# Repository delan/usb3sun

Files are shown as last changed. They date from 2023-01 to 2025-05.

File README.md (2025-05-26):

usb3sun
=======

usb3sun is an adapter that allows you to connect USB keyboards and mice to the Sun 8-pin mini-DIN interface.

* [buy now](https://www.tindie.com/products/funnycomputer/usb3sun/) on tindie
* read more about
    * [the breadboard prototype](https://cohost.org/delan/post/787278-usb3sun-a-usb-input)
    * [the development of rev A1](https://cohost.org/delan/post/1650431-usb3sun-rev-a1-a-us)
    * [the development of rev A2](https://cohost.org/delan/post/2042852-usb3sun-rev-a2-now)
    * [the development of rev A3](https://cohost.org/delan/post/2973101-usb3sun-rev-a3-guar)
    * [the development of firmware 2.0](https://cohost.org/delan/post/5806830-usb3sun-2-0-faster)
    * [the development of rev B0](https://cohost.org/delan/post/6029886-usb3sun-rev-b0-a-us)
    * [the funny computer museum](https://funny.computer.daz.cat/)

see also:

* [USB2Sun](https://github.com/jgilje/USB2Sun) by @jgilje
* [sun2usb](https://github.com/jareklupinski/sun2usb) by @jareklupinski

**note:** this repo uses submodules! clone with `--recursive`, or if you forgot to do that:

```sh
$ git submodule update --init --recursive
```

documentation
-------------

* **[user guide](doc/manual.md)**
* hacking and assembly docs
    * [firmware](doc/firmware.md)
    * [breadboard prototype](doc/prototype.md)
    * [pcb](hardware/pcb) docs coming soon!
* maintainer docs
    * [how to release](doc/releasing.md)

what’s new
----------

**rev B0** allows for debug logging (and the new debug cli) **without disabling the sun keyboard interface**, and fixes some [minor bugs](https://github.com/delan/usb3sun/blob/B0/doc/manual.md#errata) that happen when resetting the adapter.

new in **firmware 2.0**:

- support for **NeXTSTEP** and **Plan 9**, which require the mouse to run at 1200 baud
- configurable **mouse baud rate** — 9600 (default), 4800, 2400, or 1200 baud
- **debug cli** over UART_RX, allowing you to automate keyboard and mouse inputs

as of **firmware 1.5**, usb3sun can now [**reprogram your idprom**](https://funny.computer.daz.cat/sun/nvram-hostid-faq.txt) with just a few keystrokes, making it easier to boot your workstation with a dead nvram battery!

hardware features
-----------------

usb3sun includes an **audible buzzer** to emulate the bell and click functions that would normally be included with a Sun keyboard.

usb3sun also emulates the **power key** in two ways:

* **soft power key** (Right Ctrl+P)
    * sends the power key scancodes (30h/B0h)
    * can turn on your workstation (only when usb3sun is powered externally)
* **onboard power button** (near the display)
    * doesn’t send any scancodes
    * can turn on your workstation (even when not powered externally)

usb3sun has an **oled display** that shows:

* keyboard led indicators (caps, compose, scroll, num)
* visual buzzer (click, bell)
* the settings menu

usb3sun has an **onboard reset button** in case the firmware gets stuck, and a **0.1″ debug header** (pins available as an option) that allows you to power the adapter externally for flashing or debugging.

firmware features
-----------------

usb3sun has **persistent settings** for:

* forcing click mode (no/off/on)
* click duration (5–100 ms)
* mouse baud rate (for NeXTSTEP and Plan 9)
* your hostid

features planned for a future firmware version:

* settings for bell/click tone frequency
* led indicators on your USB keyboard itself

release notes
-------------

### firmware ?.? (????-??-??)

* added experimental support for **leds on your usb keyboard** — led updates are not yet reliable, and currently has bugs that can cause usb devices to stop responding
* added experimental support for **analysing other sun keyboards** — this allows us to improve our firmware by observing the behaviour of real sun keyboards

### firmware 2.1 (2025-05-26)

* [pio_pkg_list.txt](https://github.com/delan/usb3sun/blob/2.1/pio_pkg_list.txt) = dependency tree at time of release
* [#15](https://github.com/delan/usb3sun/issues/15) — fixed “The IDPROM contents are invalid” when reprogramming the idprom on some machines, including the Ultra5
* [#20](https://github.com/delan/usb3sun/issues/20) — fixed a bug where the display may not work correctly on a cold start (affects rev B0 units starting from B1#7)

### pcb rev B1 (2025-04-20)

* this board **requires firmware 2.1** or newer — firmware 2.0 is affected by [#20](https://github.com/delan/usb3sun/issues/20)
* changed J1 from [USB-U267-BWS](https://jlcpcb.com/partdetail/HanboElectronic-USB_U267BWS/C2962392) to the compatible [USB-269-BRW](https://jlcpcb.com/partdetail/Xunpu-USB_268BRY/C720548) due to stock shortage
* migrated from kicad 7 to kicad 8

### pcb rev B0 (2024-05-25)

* this board **requires firmware 2.0** or newer
* [#2](https://github.com/delan/usb3sun/issues/2) — fixed a limitation where the workstation **drops you into an ok prompt** when resetting the adapter
* [#11](https://github.com/delan/usb3sun/issues/11) — fixed a bug where the adapter can **hang until power cycled** after being reset, especially when reset frequently
* [#10](https://github.com/delan/usb3sun/issues/10) — added support for logging over UART_TX/UART_RX **without disabling the sun keyboard interface**
* reworked component layout and routing for **sun interfaces** and **led indicators** — none of the user-facing component locations have changed
* replaced transistors Q1 through Q4 (2N7000) with dual transistors Q1 and Q3 (2N7002DW)
* removed solder jumpers JP1 and JP2, which were added in rev A2 in case of errata

### firmware 2.0 (2024-05-02)

* [pio_pkg_list.txt](https://github.com/delan/usb3sun/blob/2.0/pio_pkg_list.txt) = dependency tree at time of release
* added support for adapters with **pcb rev B0** — these use pinout v2, while older revs use pinout v1
* added a **mouse baud setting** that can be set to 9600 baud (default), 4800, 2400, or 1200 baud
    * this adds support for **NeXTSTEP** and **Plan 9**, which require the mouse to run at a lower baud rate ([#8](https://github.com/delan/usb3sun/issues/8))
* you can now choose whether to **save or discard settings changes** when you close the menu
    * this change was made as part of a workaround for usb devices that malfunction when saving settings ([#14](https://github.com/delan/usb3sun/issues/14)); if you have any affected devices, hold **Shift** while pressing **Enter** to reboot the adapter after saving settings
* the displayed **version number** can now include **uncommitted and/or unreleased changes** (`2.0+` / `2.0+1` / `2.0+1+`)
* several other improvements to the user interface
    * you can now **close the menu by pressing Esc**
    * the menu now **automatically closes** after *Reprogram idprom* and *Wipe idprom (AAh)*
    * the menu now **shows four menu items**, rather than three menu items and the version number
    * *Click duration* now **beeps to preview your changes**, regardless of whether clicks are enabled
    * *Reprogram idprom* now **tells you what hostid is being programmed** into your idprom
* **updated our usb host stack**, making usb devices enumerate faster
    * Adafruit TinyUSB Library (2.0.1 → 3.1.0), Pico PIO USB (0.5.2 → 0.5.3)
    * this may affect [compatibility](https://github.com/delan/usb3sun/blob/default/doc/manual.md#compatibility) with your usb devices; please [report any regressions or improvements](https://github.com/delan/usb3sun/issues?q=is%3Aissue+is%3Aopen+label%3Acompatibility)
* added support for logging over UART_TX/UART_RX **without disabling the sun keyboard interface** ([#10](https://github.com/delan/usb3sun/issues/10))
    * this feature requires **pcb rev B0** or newer, due to the pinout changes required
    * please report any regressions with the **buzzer** or **sun mouse interface**; the buzzer had to be moved from pio to hardware pwm, and the sun mouse had to be moved from hardware uart to pio
* added a **debug cli** over UART_RX — this lets you press keys and move the mouse without a usb keyboard or mouse
* the firmware can now be **built as a normal program for linux**, thanks to a new hardware abstraction layer; as a result:
    * added an **interactive demo** (`run-demo.sh`) that can be used to play with or develop the user interface
    * added a **test suite** (`run-tests.sh`) for the setup and pinout routines, sun keyboard interface (reset sequence), buzzer (click and bell), settings (reads, writes, upgrades), and menu (confirm-save, hostid, i/o)
    * we can **catch some memory access violations** with dynamic analysis by **AddressSanitizer** (asan)
* added some **build tests** (`run-build-tests.sh`) to catch compile errors with custom build flags
* fixed some potential future compatibility issues in the settings formats (variable-width integer types and variable struct padding)
    * your existing settings in their v1 formats will be upgraded automatically
* fixed a compile error when debug logging was enabled (**PICOPROBE_ENABLE**, now known as **DEBUG_OVER_UART**)
* fixed all compile warnings under -Wall with the current toolchains for `pico` and `linux` (via nix-shell)
* fixed incorrect debug log output for **report id**, **usage**, and **usage page** when enumerating usb hid devices
* fixed missing newline in debug log output when reporting ErrorRollOver inputs from usb keyboards
* fixed missing newline in UHID_VERBOSE output when reporting inputs from non-boot-protocol usb devices
* removed the splash screen from debug logging — this significantly slowed down the setup routine
* removed the fake sun emulation feature — this wasn’t too useful, and was broken by the pinout changes
* several changes to config.h
    * added **DEBUG_OVER_CDC** to disable logging over usb cdc
    * added **UHID_LED_ENABLE** to opt into experimental usb hid led support
    * added **UHID_LED_TEST** to blink leds on all usb keyboards
    * added pin definitions **PINOUT_V2_PIN**, **KTX_ENABLE**, **DISPLAY_ENABLE**, **DEBUG_UART**, **SUNK_UART_V1**, **SUNK_UART_V2**, and **SUNM_UART_V1**
    * removed **SUNM_BAUD** in favour of the new menu setting
    * renamed **PICOPROBE_ENABLE** to **DEBUG_OVER_UART**
    * renamed **PICOPROBE_BAUD** to **DEBUG_UART_BAUD**
    * renamed **PICOPROBE_TX** to **DEBUG_UART_TX**
    * renamed **PICOPROBE_RX** to **DEBUG_UART_RX**
    * **SUN_KTX**, **SUN_KRX**, **SUN_MTX**, and **SUN_MRX** were split into pinout v1 and v2 variants
    * **DEBUG_OVER_UART** no longer disables logging over usb cdc (see **DEBUG_OVER_CDC**)
    * **SUNK_ENABLE** was moved to platformio.ini, and takes precedence over **DEBUG_OVER_UART** in pinout v1
    * **SUNM_ENABLE** was moved to platformio.ini

### pcb rev [A3](https://github.com/delan/usb3sun/releases/tag/A3) (2023-10-15)

* fixed the inconsistent and excessive brightness of the led indicators (D2, D3)
* fixed a bug where the VBUS indicator led (D2) can be dimly lit without VBUS being connected
* changed J1 from [UJ2-ADH-W1-TH](https://jlcpcb.com/partdetail/CuiDevices-UJ2_ADH_W1TH/C5201729) to the compatible [USB-U267-BWS](https://jlcpcb.com/partdetail/HanboElectronic-USB_U267BWS/C2962392) due to stock shortage
* cleaned up unused kicad libraries, and checked in libraries that were missing from the repo

### firmware [1.5](https://github.com/delan/usb3sun/releases/tag/1.5) (2023-07-18)

* [pio_pkg_list.txt](https://github.com/delan/usb3sun/blob/1.5/pio_pkg_list.txt) = dependency tree at time of release
* added a **macro to reprogram your idprom** — this makes it easier to boot your workstation with a dead nvram battery
* added a **macro to wipe your idprom** — this makes your idprom contents invalid, as if you had a dead nvram battery
* added a **hostid setting** — this sets the hostid used when reprogramming your idprom
* changed behaviour of builtin led to turn on at the very start of setup — this may help troubleshoot problems with CDC serial port initialisation

### firmware [1.4](https://github.com/delan/usb3sun/releases/tag/1.4) (2023-07-17)

* [pio_pkg_list.txt](https://github.com/delan/usb3sun/blob/1.4/pio_pkg_list.txt) = dependency tree at time of release
* **fixed a serious bug** where opening the settings menu can make the adapter start releasing keys at the wrong times
* **fixed a serious bug** where special key bindings (Right Ctrl) can get stuck down if Right Ctrl is released early
* you can now press special key bindings (Right Ctrl) together with other modifiers (e.g. [Shift+Undo](https://docs.oracle.com/cd/E19683-01/806-7612/startup-tbl-5/index.html) for Redo)
* improved performance of keyboard processing — this reduces the latency of key presses by up to 90 µs

you should update your firmware if you have any of the following symptoms:

* modifiers like Shift stop working after closing the settings menu
* modifiers like Shift appear to have a delayed effect after closing the settings menu
* when a key gets stuck down, it remains stuck even after pressing and releasing another key

you can also work around these bugs by resetting the adapter.

### firmware [1.3](https://github.com/delan/usb3sun/releases/tag/1.3) (2023-07-16)

* [pio_pkg_list.txt](https://github.com/delan/usb3sun/blob/1.3/pio_pkg_list.txt) = dependency tree at time of release
* added **firmware version to display** — this replaces the logo, which became a bit redundant
* added **marquee display for long menu items** — this fixes a bug where they would wrap in an unreadable way

### pcb rev [A2](https://github.com/delan/usb3sun/releases/tag/A2) (2023-06-30)

* added usb-c port J4 — this makes firmware updates much easier, and makes it possible to debug the sun keyboard and mouse interfaces simultaneously
* added polyfuse F3 after power supply switches — this protects the adapter under more fault conditions, in addition to faults in the downstream usb ports
* changed led resistors R12 and R13 from 200R to 1K — this reduces the luminous intensity from ~80% down to ~10% relative to 20mA
* changed tactile switches SW1 and SW2 from [TS-1187A-C-H-B](https://jlcpcb.com/partdetail/XkbConnectivity-TS_1187A_C_HB/C528025) to [TS-1187A-B-A-B](https://jlcpcb.com/partdetail/XkbConnectivity-TS_1187A_B_AB/C318884) — this reduces the extended parts fee with jlcpcb

### firmware [1.2](https://github.com/delan/usb3sun/releases/tag/1.2) (2023-06-11)

* [pio_pkg_list.txt](https://github.com/delan/usb3sun/blob/1.2/pio_pkg_list.txt) = dependency tree at time of release
* added **audible usb plug/unplug notifications**
* added **persistence for settings** — including click duration!
* added **“force click” setting** — this replaces the old disable/enable click option in the settings menu, which toggled the same state as the host machine, with an independent override
* changed the initial click mode state to off
* changed the initial led indicator states to off
* fixed theoretical(?) race condition in buzzer management
* fixed errors in the README bindings table

### pcb rev [A1](https://github.com/delan/usb3sun/releases/tag/A1) (2023-05-10)

* added display mechanical support — **committed later in [74b367a12600d](https://github.com/delan/usb3sun/commit/74b367a12600d712eb7a05a9fc67c958bae3fe62)**
* added tactile switches for reset and hard power key
* added header pins for debug logging over UART0
* added mounting holes for display mechanical support
* added LED indicators for VBUS and VSUN
* improved enclosure compatibility by moving mini-din beyond bottom edge
* improved ground plane islands by stitching vias
* made all corner mounting holes padded on both sides — previously this was only the case for the hole connected to GNDPWR, but not the other three

### firmware [1.1](https://github.com/delan/usb3sun/releases/tag/1.1) (2023-05-06)

* [pio_pkg_list.txt](https://github.com/delan/usb3sun/blob/1.1/pio_pkg_list.txt) = dependency tree at time of release
* fixed regressions due to dependency updates
    * fixed panic regression with *Pico Pio USB* 0.5.2 by removing non-idempotent workaround for a bug that was fixed upstream (sekigon-gonnoc/Pico-PIO-USB#77)
    * worked around unsolved usb hid regression (adafruit/Adafruit_TinyUSB_Arduino#296) by pinning *Adafruit TinyUSB Library* to 2.0.1
* fixed panic when combining PICOPROBE_ENABLE and CFG_TINYUSB_DEBUG
* changed default DISPLAY_ROTATION to 0 — this better suits pcb rev A0 than the old value, and is equally suitable for the breadboard prototype
* changed debug/upload protocols to cmsis-dap — this fixes compatibility with new picoprobe firmware
* pinned sensitive dependencies to reduce future breakage — note that not all dependencies are pinned yet (platformio/platformio-core#4613), but see above for known-good dependency tree

### pcb rev [A0](https://github.com/delan/usb3sun/releases/tag/A0) (2023-04-28)

* initial release

### firmware [1.0](https://github.com/delan/usb3sun/releases/tag/1.0) (2023-01-08)

* initial release

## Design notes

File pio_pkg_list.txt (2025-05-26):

********************************************************************************
Obsolete PIO Core v6.1.11 is used (previous was 6.1.17)
Please remove multiple PIO Cores from a system:
https://docs.platformio.org/en/latest/core/installation/troubleshooting.html
********************************************************************************
Warning! Ignore unknown configuration option `rust_lib` in section [env]
Warning! Ignore unknown configuration option `rust_target` in section [env:pico]
Resolving pico dependencies...
Platform raspberrypi @ 1.14.0+sha.5e87ae3 (required: git+https://github.com/maxgerhardt/platform-raspberrypi.git#v1.2.0-gcc12)
├── framework-arduinopico @ 1.30101.0+sha.c276a36 (required: git+https://github.com/earlephilhower/arduino-pico.git#3.1.1)
├── tool-mklittlefs-rp2040-earlephilhower @ 5.100300.230216 (required: earlephilhower/tool-mklittlefs-rp2040-earlephilhower @ ~5.100300.0)
├── tool-openocd-rp2040-earlephilhower @ 5.120300.240818 (required: https://github.com/earlephilhower/pico-quick-toolchain/releases/download/2.2.0/x86_64-linux-gnu.openocd-ebec9504d.240818.tar.gz)
├── tool-picotool-rp2040-earlephilhower @ 5.120300.240818 (required: https://github.com/earlephilhower/pico-quick-toolchain/releases/download/2.2.0/x86_64-linux-gnu.picotool-8a9af99.240818.tar.gz)
└── toolchain-rp2040-earlephilhower @ 5.120300.240125 (required: https://github.com/earlephilhower/pico-quick-toolchain/releases/download/2.2.0/x86_64-linux-gnu.arm-none-eabi-028e019.240125.tar.gz)

Libraries
├── Adafruit GFX Library @ 1.11.5+sha.5ea4be3 (required: git+https://github.com/adafruit/Adafruit-GFX-Library.git#1.11.5)
│   └── Adafruit BusIO @ 1.17.0 (required: Adafruit BusIO)
├── Adafruit SSD1306 @ 2.5.7+sha.88711ef (required: git+https://github.com/adafruit/Adafruit_SSD1306.git#2.5.7)
├── Adafruit TinyUSB Library @ 0.0.0+sha.2ebb6ab (required: git+https://github.com/adafruit/Adafruit_TinyUSB_Arduino.git#3.1.0)
└── Pico PIO USB @ 0.5.3+sha.e2c862b (required: git+https://github.com/sekigon-gonnoc/Pico-PIO-USB.git#0.5.3)

Resolving linux dependencies...
Platform native @ 1.2.1 (required: native)
├── contrib-piohome @ 3.4.4 (required: platformio/contrib-piohome)
├── framework-arduinopico @ 1.30101.0+sha.c276a36 (required: git+https://github.com/earlephilhower/arduino-pico.git#3.1.1)
├── tool-mklittlefs-rp2040-earlephilhower @ 5.100300.230216 (required: earlephilhower/tool-mklittlefs-rp2040-earlephilhower)
├── tool-openocd-rp2040-earlephilhower @ 5.120300.240818 (required: https://github.com/earlephilhower/pico-quick-toolchain/releases/download/2.2.0/x86_64-linux-gnu.openocd-ebec9504d.240818.tar.gz)
├── tool-picotool-rp2040-earlephilhower @ 5.120300.240818 (required: https://github.com/earlephilhower/pico-quick-toolchain/releases/download/2.2.0/x86_64-linux-gnu.picotool-8a9af99.240818.tar.gz)
├── tool-scons @ 4.40502.0 (required: platformio/tool-scons)
└── toolchain-rp2040-earlephilhower @ 5.120300.240125 (required: https://github.com/earlephilhower/pico-quick-toolchain/releases/download/2.2.0/x86_64-linux-gnu.arm-none-eabi-028e019.240125.tar.gz)

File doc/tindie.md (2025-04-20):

SPARCstations have [a unique serial-like interface](https://deskthority.net/wiki/Sun_keyboard/mouse_interface) for keyboard and mouse input, using a single 8-pin mini-din port. **usb3sun** allows you to use an ordinary USB keyboard and mouse with your SPARCstation!

in addition to the adapter itself, you will also need a male-to-male 8-pin mini-din cable (available as an option or [sold separately](https://www.tindie.com/products/funnycomputer/sun-mini-din-cable-2-metres/)), and your own USB keyboard and mouse (see below for compatibility).

**caution:** these cables are often sold elsewhere as a “mini-din serial cable”, but you **must** check that each pin is connected to the same pin on the other end. some cables, like the apple 590-0552-A, swap pins 1/2 + 3/5 + 6/8, and such cables must not be used.

* [user guide](https://github.com/delan/usb3sun/blob/default/doc/manual.md)
* [release notes](https://github.com/delan/usb3sun/releases)
* [project writeups and other links](https://go.daz.cat/usb3sun)

### testimonials

[europa64](https://linktr.ee/europa64) says:

“Honestly this is such a game changer, it really makes Suns so much more accessible for people who don’t have a hoard of vintage kit or the money to buy a keyboard on eBay. Getting these old machines into the hands of people is honestly one of the best ways to ensure they get preserved and your device really helps with that <3”

### what’s new

**rev B0** allows for debug logging (and the new debug cli) **without disabling the sun keyboard interface**, and fixes some [minor bugs](https://github.com/delan/usb3sun/blob/B0/doc/manual.md#errata) that happen when resetting the adapter.

**rev B1** is the same as rev B0, but with the USB-A connector changed due to stock shortage.

new in **firmware 2.0**:

- support for **NeXTSTEP** and **Plan 9**, which require the mouse to run at 1200 baud
- configurable **mouse baud rate** — 9600 (default), 4800, 2400, or 1200 baud
- **debug cli** over UART_RX, allowing you to automate keyboard and mouse inputs

as of **firmware 1.5**, usb3sun can now [**reprogram your idprom**](https://funny.computer.daz.cat/sun/nvram-hostid-faq.txt) with just a few keystrokes, making it easier to boot your workstation with a dead nvram battery!

### hardware features

usb3sun includes an **audible buzzer** to emulate the bell and click functions that would normally be included with a Sun keyboard.

usb3sun also emulates the **power key** in two ways:

* **soft power key** (Right Ctrl+P)
    * sends the power key scancodes (30h/B0h)
    * can turn on your workstation (only when usb3sun is powered externally)
* **onboard power button** (below the display)
    * doesn’t send any scancodes
    * can turn on your workstation (even when not powered externally)

usb3sun has an **oled display** that shows:

* led indicators (caps, compose, scroll, num)
* visual buzzer (click, bell)
* the settings menu

usb3sun has an **onboard reset button** in case the firmware gets stuck, and a **0.1″ debug header** with pins that allow you to power the adapter externally for flashing or debugging.

### firmware features

usb3sun has **persistent settings** for:

* forcing click mode (no/off/on)
* click duration (5–100 ms)
* mouse baud rate (for NeXTSTEP and Plan 9)
* your hostid

### compatibility

usb3sun is compatible with any machine that would normally use a

* Sun Compact 1
* Sun Type 4
* Sun Type 5
* Sun Type 5c
* Sun Type 6 (non-usb)

usb3sun has been tested successfully with

- SPARCstation IPC (sun4c)
- SPARCstation IPX (sun4c)
- SPARCstation 2 (sun4c)
- SPARCstation 5 (sun4m)
- SPARCstation 20 (sun4m)
- Ultra 5 (sun4u)
- 1209:A1E5 Atreus (Technomancy version) **keyboard** with QMK
- 04A5:8001 BenQ Zowie EC2 **mouse**
- 046D:C063 Dell M-UAV-DEL8 **mouse**
- FEED:1307 gBoards Gergo **keyboard** with QMK
- 03F0:6941 HP 150 Wired **Keyboard** (HSA-A013K, 664R5AA)
- 0461:4E24 HP KB71211 **keyboard** — no scroll lock or right meta
- 0461:4E23 HP MOGIUO **mouse**
- 04D9:1503 Inland 208397 **keyboard**
- 30FA:2031 Keji KECK801UKB **keyboard**
- 17EF:608D Lenovo EMS-537A **mouse**
- 17EF:6019 Lenovo MSU1175 **mouse**
- 045E:0040 Microsoft Wheel **Mouse** Optical 1.1A — enumeration is unreliable
- 045E:0752 Microsoft Wired **Keyboard** 400
- 045E:0750 Microsoft Wired **Keyboard** 600
- 045E:0773 Microsoft Explorer Touch **Mouse** (model 1490)
- FEED:6061 Preonic OLKB-60 **keyboard** with QMK

usb3sun is not yet compatible with

- [#4](https://github.com/delan/usb3sun/issues/4) — 05AC:024F Apple Magic **Keyboard** with Numeric Keypad (model A1243)
- [#5](https://github.com/delan/usb3sun/issues/5) — 1209:2303 Atreus (Keyboardio version) **keyboard** with Kaleidoscope
- [#6](https://github.com/delan/usb3sun/issues/6) — 3367:1903 Endgame Gear XM1r **mouse** — buttons only (16-bit dx/dy, no boot protocol)
- [#7](https://github.com/delan/usb3sun/issues/7) — 045E:0039 Microsoft Intelli**Mouse** Optical 1.1A — broken (“Control FAILED”)

### bindings

| USB | Sun |
|---|---|
| context menu | Compose |
| Left Alt | Alt |
| Right Alt | Graph/Alt |
| Left GUI* | left Meta (diamond) |
| Right GUI* | right Meta (diamond) |
| Left Ctrl | Control |
| Right Ctrl+Space  | (usb3sun settings menu) |
| Right Ctrl+. | Stop |
| Right Ctrl+Esc | Front |
| Right Ctrl+Return | Line Feed |
| Right Ctrl+C | Copy |
| Right Ctrl+F | Find |
| Right Ctrl+O | Open |
| Right Ctrl+P | Power |
| Right Ctrl+V | Paste |
| Right Ctrl+X | Cut |
| Right Ctrl+Y | Again |
| Right Ctrl+Z | Undo |
| Right Ctrl+F1 | Help |
| Right Ctrl+F4 | Props |
| Right Ctrl+= | keypad = |

\* aka Super, Mod4, Windows, etc

### specs

|  |  |
| --- | --- |
| width | 36 mm |
| length | 98 mm |
| height | 23 mm |
| ports | 1x Sun mini-din |
|  | 2x USB-A |
|  | 1x USB-C (debug only) |
| buttons | power (for workstation) |
|  | reset (for adapter) |
| led indicators | VBUS ok |
|  | VSUN ok |
| debug header pinout | 1. GND |
|  | 2. UART_TX |
|  | 3. UART_RX |
|  | 4. SWDIO |
|  | 5. SWCLK |
|  | 6. VBUS |

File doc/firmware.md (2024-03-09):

[README](../README.md) >

firmware
========

## how to build the firmware

1. `git apply picopiousb1.patch` ([picopiousb1.patch](../picopiousb1.patch), [#12](https://github.com/delan/usb3sun/issues/12))\
→ improves compatibility with Microsoft Wired Keyboard 600 (045E:0750)
2. `git apply tinyusb3.patch` ([tinyusb3.patch](../tinyusb3.patch), [#13](https://github.com/delan/usb3sun/issues/13))\
→ fixes a bug where dummy event callbacks shadow our own callbacks ([Adafruit_TinyUSB_Arduino#296](https://github.com/adafruit/Adafruit_TinyUSB_Arduino/issues/296))
3. `git apply debug1.patch` ([debug1.patch](../debug1.patch))\
→ makes TinyUSB debug logging configurable at runtime
4. `git -C ~/.platformio/packages/framework-arduinopico apply $PWD/debug2.patch` ([debug2.patch](../debug2.patch))\
→ makes arduino-pico debug logging configurable at runtime
5. `git -C ~/.platformio/packages/framework-arduinopico apply $PWD/debug3.patch` ([debug3.patch](../debug3.patch))\
→ makes TinyUSB debug logging configurable at runtime

### linux users

if you get “patch does not apply” errors:

```sh
$ dos2unix '.pio/libdeps/pico/Adafruit TinyUSB Library/src/host/usbh.c'
```

copy these commands to do all of the above:

```sh
dos2unix '.pio/libdeps/pico/Adafruit TinyUSB Library/src/host/usbh.c'
git apply tinyusb1.patch
git apply tinyusb2.patch
git apply debug1.patch
git -C ~/.platformio/packages/framework-arduinopico apply $PWD/debug2.patch
```

### windows users

if you encounter problems with paths being too long:

1. open an admin command prompt (Win+X, A)
2. `git config --system core.longpaths true`
3. whenever you get `[WinError 3]` or `[WinError 145]`, delete `%USERPROFILE%\.platformio\.cache\tmp`

if you get “patch does not apply” errors in step 2:

1. change the line endings from CRLF to LF in <.pio/libdeps/pico/Adafruit TinyUSB Library/src/host/usbh.c>

## how to get clangd (LSP) working

```sh
$ pio run -t compiledb
```

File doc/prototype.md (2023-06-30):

[README](../README.md) >

breadboard prototype
====================

## bill of materials

* 1x [raspberry pi pico, with headers](https://www.altronics.com.au/p/z6421a-raspberry-pi-pico-rp2040-development-board-with-headers/)
    * or 1x [raspberry pi pico](https://www.altronics.com.au/p/z6421-raspberry-pi-pico-microcontroller-board/) + 1x [0.1″ header pin block, 40x1](https://www.altronics.com.au/p/p5430-oupiin-40-way-header-pin/)
* 1x [ssd1306 i2c oled display, 128x32, with headers](https://www.aliexpress.com/item/1005004375650245.html)
* 2x [2n7000, n-channel mosfet, to-92 (s, g, d)](https://www.altronics.com.au/p/z1555-2n7000-to-92-n-channel-tmosfet/) ([datasheet](https://www.onsemi.com/pdf/datasheet/nds7002a-d.pdf))
* 3x 20K resistor, through hole
    * or 1x [20K resistor, through hole, 1% 0W25, bulk 10 units](https://www.altronics.com.au/p/r7589-20k-0.25w-metal-film-resistor-pk-10/)
    * or 1x [tinker component kit](https://www.altronics.com.au/p/k9640-tinker-parts-starter-kit/)
* 1x [solderless breadboard, 400 tie points (300+50+50)](https://www.altronics.com.au/p/p1002-400-way-breadboard/)
* 1x [solid wire kit, for solderless breadboards](https://www.altronics.com.au/p/p1018a-prototyping-breadboard-wire-packs-350pcs/)
    * or any sufficient amount of suitable solid wire
* 1x [mini-din plug, 8 pins, reversible](https://www.altronics.com.au/p/p1098-8-pin-line-mini-din-plug/)
* 16x jumper wire, dupont 0.1″, pin to socket
    * or 1x [jumper wire, dupont 0.1″, pin to socket, row of 30](https://www.altronics.com.au/p/p1021-pin-to-socket-30-way-prototyping-ribbon-strips/)
* ⎰ 3x crimp housing, dupont 0.1″, 4x1
* ⎱ 4x crimp housing, dupont 0.1″, 2x1
    * or 1x [crimp kit, dupont 0.1″](https://www.altronics.com.au/p/k9642-2.54mm-header-kit-310pc/)
* ⎰ 1x usb breakout board, usb a, 2 ports
* ⎱ 1x piezo buzzer, passive
    * you can often find these in old computer cases

## reference designators

* Q1 = 2n7000 for keyboard rx level shifter
* Q2 = 2n7000 for keyboard tx level shifter (optional)
* Q3 = 2n7000 for mouse tx level shifter (optional)
* Q4 = 2n7000 for soft power key
* U1 = pico
* U2 = display

## assembly instructions

1. connect a3 (U1 GND) to the left (Vusb) negative rail
2. connect g1 (U1 VBUS) to the left (Vusb) positive rail
3. connect j3 (U1 GND) to the right (3V3) negative rail
4. connect j5 (U1 3V3(OUT)) to the right (3V3) positive rail
5. connect j23 (U2 GND) to the right (3V3) negative rail
6. connect j22 (U2 VCC) to the right (3V3) positive rail
7. connect e22 (Q1 pin 2) to f22 (3V3 supply)
8. connect a24 (Q4 pin 1) to the left (Vusb) negative rail
9. connect g21 (U2 SCK) to g19 (U1 GP17)
10. connect d21 (Q1 pin 1) to d17 (U1 GP13)
    * picture below erroneously shows d21 to d12 (U1 GP9)
11. connect e25 (Q4 pin 2) to e20 (U1 GP15)
12. place Q1 pins (1,2,3) in (c21,c22,c23)
13. place Q4 pins (1,2,3) in (c24,c25,c26)
14. place resistor between b21 (Q1 pin 1) and b22 (3V3 supply)
15. place resistor between b23 (Q1 pin 3) and b27 (Vsun)
16. place resistor between b25 (Q4 pin 2) and b24 (ground)

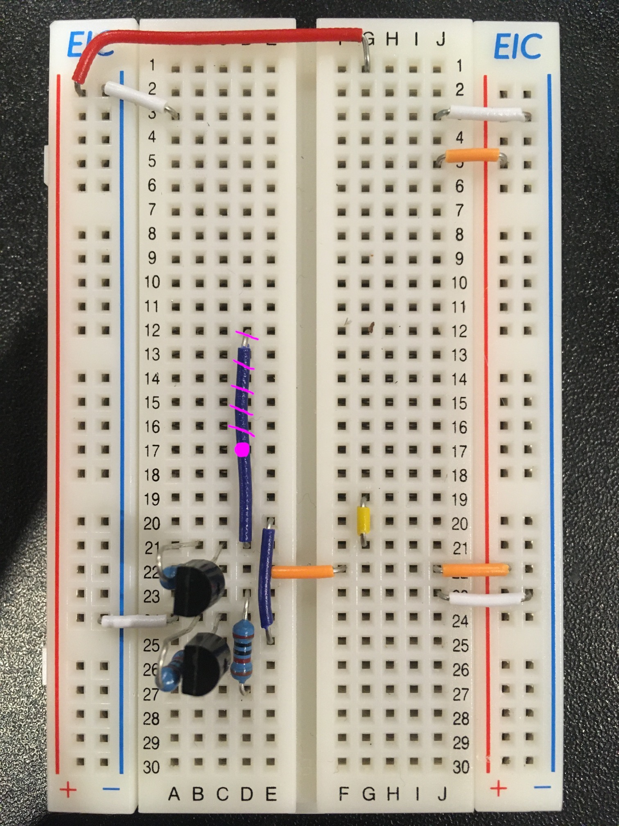
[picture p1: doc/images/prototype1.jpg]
prototype1


17. extract 1x1 crimp housings from both ends of 8 jumper wires
18. attach 4x1 crimp housing to socket ends of (VCC1,D-1,D+1,GND1)
19. attach 4x1 crimp housing to socket ends of (VCC2,D-2,D+2,GND2)
20. attach 2x1 crimp housing to pin ends of (VCC1,VCC2)
21. attach 2x1 crimp housing to pin ends of (GND1,GND2)
22. attach 4x1 crimp housing to pin ends of (D+1,D-1,D+2,D-2)
23. connect socket ends of (VCC1,D-1,D+1,GND1) and (VCC2,D-2,D+2,GND2)
24. connect pin ends of (GND1,GND2) to left (Vusb) negative rail
25. connect pin ends of (VCC1,VCC2) to left (Vusb) positive rail
26. connect pin ends of (D+1,D-1,D+2,D-2) to (a4,a5,a6,a7) (U1 (GP2,GP3,GP4,GP5))

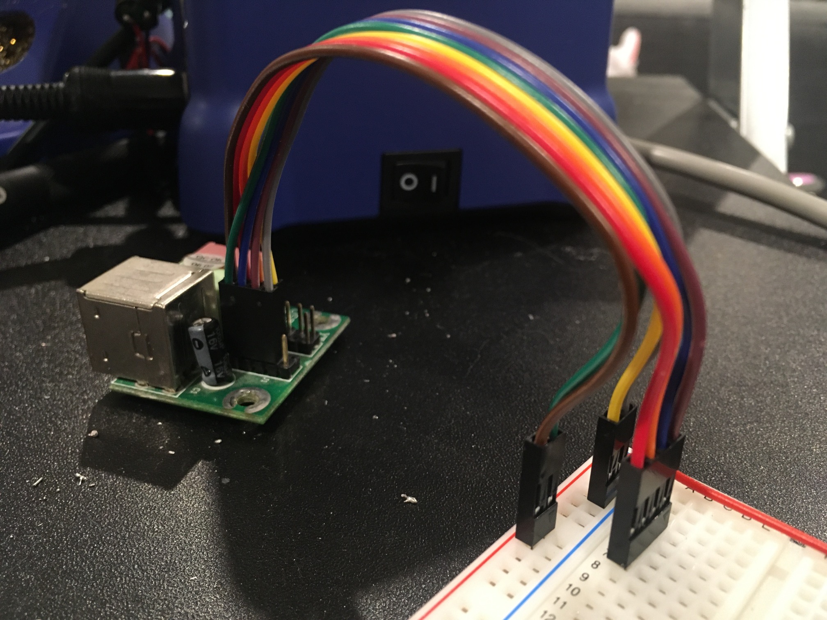
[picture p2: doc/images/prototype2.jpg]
prototype2


27. strip and tin the socket ends of 8 jumper wires
28. solder those wires to the mini-din plug

**DO NOT** solder to the side where the middle pin is closer to the left, when orienting the connector body such that the pins are in rows of (3,3,2) from top to bottom. this is the side that faces the sun.

**DO** solder to the side where the middle pin is closer to the right.

```
 side facing sun           solder side
                         (same as socket
                             on sun)

        ^                       ^
    6   7   8               8   7   6
  3   4       5           5       4   3
      1   2                   2   1
```

29. extract 1x1 crimp housings from wires for mini-din pins (1,2) (ground)
30. attach 2x1 crimp housing to wires for mini-din pins (1,2) (ground)
31. extract 1x1 crimp housings from wires for mini-din pins (3,8) (Vsun)
32. attach 2x1 crimp housing to wires for mini-din pins (3,8) (Vsun)
33. connect wires for mini-din pins (1,2) (ground) to left (Vusb) negative rail
34. connect wire for mini-din pins (3,8) (Vsun) to (a27,b27) (resistor on Q1 pin 3)
35. connect wire for mini-din pin 4 (mouse tx) to b11 (U1 GP8)
36. connect wire for mini-din pin 6 (keyboard tx) to b16 (U1 GP12)
37. connect wire for mini-din pin 5 (keyboard rx) to b23 (Q1 pin 3)
38. connect wire for mini-din pin 7 (power key) to b26 (Q4 pin 3)

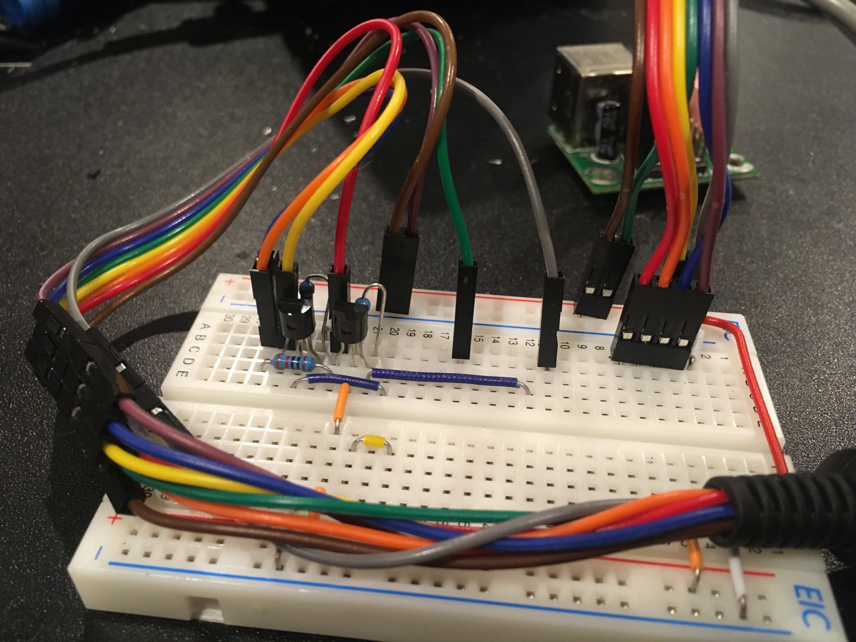
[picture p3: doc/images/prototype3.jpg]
prototype3


39. place U1 pins (GP0…GP15,GP16…VBUS) in (c1…c20,h20…h1)
40. place U2 pins (SDA,SCK,VCC,GND) in (i20,i21,i22,i23)
41. connect buzzer negative to i8 (U1 GND)
42. connect buzzer positive to i7 (U1 GP28)

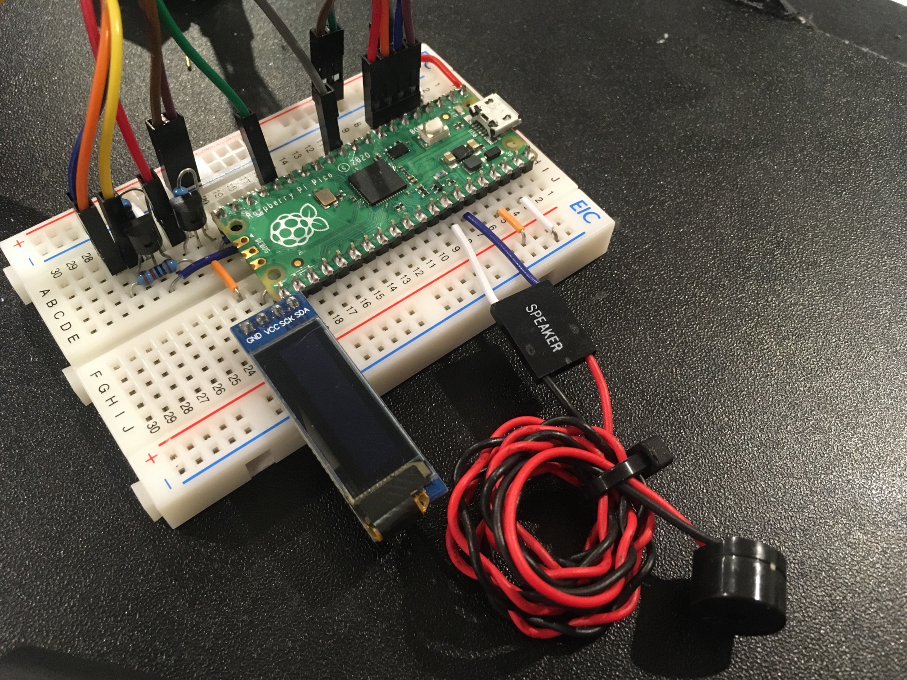
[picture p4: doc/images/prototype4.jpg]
prototype4


## troubleshooting

### monitor gets sync but no video

*observed on SPARCstation 5*

some machines will refuse to send any video unless a working keyboard is connected.

1. check that your adapter is assembled correctly
2. check that your mini-din housing isn’t interfering with the connection
    * you may need to retract the housing from time to time (see below)

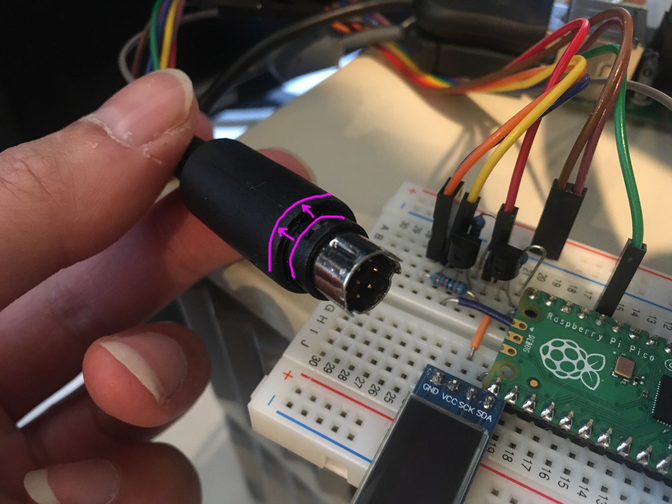
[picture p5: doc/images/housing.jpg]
housing


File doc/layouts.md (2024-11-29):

# sun keyboard layout support

supporting the various type 4 and type 5 keyboard layouts has a few challenges:
- identifying the physical keyboard layouts
- knowing what keycodes they send
- building tables of what the keycodes mean in each layout
- deciding how to map usb keycodes to them

also…
- layout codes ([0Fh Layout Command](https://temlib.org/pub/SparcStation/Standards/KBD.pdf) and [FEh Layout Request Response](https://temlib.org/pub/SparcStation/Standards/KBD.pdf)) are used to select the keymap in solaris/sunos and the firmware (openboot/sunmon), but seem to be ignored by linux distros (tested with debian 7.11.0)
- [sparc keyboard spec version1](https://temlib.org/pub/SparcStation/Standards/KBD.pdf) has incomplete and incorrect information about non-US keyboard layouts, notably table 2 (“International Scan Set”) is identical to table 1 (“US Scan Set”), both only documenting the 107-key layout

## physical keyboard layouts

- there are ?two physical type 4 layouts
  - 107-key layout with 47 main character keys ([pic en-US](https://www.flickr.com/photos/jgrove/3051883468/)), used by the US keyboard (320-1005)
  - 109-key layout with 49 main character keys ([pic de-DE](https://github.com/delan/usb3sun/assets/465303/2aa3ea0e-02fa-488c-a6cb-80acda7aae20), [pic BE fr-FR](https://tinkerdifferent.com/threads/sun-type-4-keyboard.1444/#post-9703)), used by ?all other keyboards ([part numbers](https://dogemicrosystems.ca/pub/Sun/System_Handbook/Sun_syshbk_V3.4/Systems/Sun4/INPUT_Type4_Keyboard.html))
  - see also [§ appendix: type 4 keyboard variants](#appendix-type-4-keyboard-variants)
- there are four physical type 5 layouts [[1]](https://www.vaxbarn.com/downloads/pub/pdf/sun/workstation/Sun%20Type%205c%20Keyboard%20and%20Type%205%20Mouse%20Product%20Notes%20-%201994-07.pdf)[[2]](https://vtda.org/docs/computing/Sun/hardware/800-6802-12_Type5KeyboardandMouseProductNotes_RevA_Oct93.pdf)[[3]](https://ia802806.us.archive.org/29/items/Sun_Type_5_Keyboard_Product_Notes/Sun_Type_5_Keyboard_Product_Notes.pdf)
  - 118-key layout with 47 main character keys ([pic en-US](https://www.flickr.com/photos/jgrove/3051046581/)), for US/TW/KR keyboards <!-- 10+1+1+4+4+4+3+4+6+4+4+3+4+3+3+14+14+13+12+7; 10+9+7+10+3+3+2+3 -->
  - 119-key layout with 47 main character keys ([pic en-US](https://deskthority.net/wiki/File:Suntype5.jpg)), for the “UNIX” keyboard <!-- 10+1+1+4+4+4+3+4+6+4+4+3+4+3+3+15+14+13+12+7; 10+9+7+10+4+2+2+3 -->
  - 119-key layout with 48 main character keys ([pic de-DE](https://github.com/delan/usb3sun/assets/465303/ecaf231e-8db7-405c-a329-d7a3bd58c9db), [pic en-UK](https://deskthority.net/wiki/File:Sun_Type_5_UK.jpg), [pic sv-SE](https://deskthority.net/wiki/File:SunType5c.jpg)), for “TUV-Compliant” keyboards (all other keyboards) <!-- 10+1+1+4+4+4+3+4+6+4+4+3+4+3+3+14+13+14+13+7; 10+9+7+10+3+2+3+4 -->
  - 122-key layout with 48 main character keys, for the JP keyboard <!-- 10+1+1+4+4+4+3+4+6+4+4+3+4+3+3+14+13+14+13+10; 10+9+7+10+3+2+3+4 --> ([pic jp-JP](images/type5-jp.jpg))
  - see also [§ appendix: type 5 keyboard variants](#appendix-type-4-keyboard-variants)
- physical usb layouts
  - 101/104-key layout with 47 main character keys, ansi/incits 154 <!-- 10+9+7+10+3+3+2+3 -->
  - 102/105-key layout with 48 main character keys, [iso 9995](https://en.wikipedia.org/w/index.php?title=ISO/IEC_9995&oldid=1242965538#ISO/IEC_9995-2) with B00 and C12 <!-- 10+9+7+10+3+2+3+4 -->
  - 106/109-key layout with 48 main character keys, jis x 6002 <!-- 10+9+7+10+3+2+3+4 -->
  - see also [List of QWERTY keyboard language variants](https://en.wikipedia.org/w/index.php?title=List_of_QWERTY_keyboard_language_variants&oldid=1253689618) and [Keyboard layout#Physical layouts](https://en.wikipedia.org/w/index.php?title=Keyboard_layout&oldid=1259709337#Physical_layouts) on wikipedia

## keycodes for each physical layout

### type 4, 107-key en-US (320-1005)

- gathered by building the firmware with `-DSUNK_SNIFFER_ENABLE` ([25d9defbb9ef7](https://github.com/delan/usb3sun/commit/25d9defbb9ef707f8eb204be7a572ce0c875a7cc)), then connecting my real sun keyboard to both workstation and usb3sun
- as expected, keycodes did not change when changing layout code from 00h ([United States](https://dogemicrosystems.ca/pub/Sun/System_Handbook/Sun_syshbk_V3.4/Systems/Sun4/INPUT_Type4_Keyboard.html)) to 02h ([Belgium/French](https://dogemicrosystems.ca/pub/Sun/System_Handbook/Sun_syshbk_V3.4/Systems/Sun4/INPUT_Type4_Keyboard.html)) or 05h ([German](https://dogemicrosystems.ca/pub/Sun/System_Handbook/Sun_syshbk_V3.4/Systems/Sun4/INPUT_Type4_Keyboard.html))

```
01h 03h  05h 06h 08h 0Ah 0Ch 0Eh 10h 11h 12h 07h 09h 0Bh 58h ====42h  15h 16h 17h 62h
19h 1Ah  1Dh 1Eh 1Fh 20h 21h 22h 23h 24h 25h 26h 27h 28h 29h ====2Bh  2Dh 2Eh 2Fh 47h
31h 33h  35h== 36h 37h 38h 39h 3Ah 3Bh 3Ch 3Dh 3Eh 3Fh 40h 41h |___|  44h 45h 46h |_|
48h 49h  4Ch=== 4Dh 4Eh 4Fh 50h 51h 52h 53h 54h 55h 56h 57h 2Ah |59h  5Bh 5Ch 5Dh 7Dh
5Fh 61h  63h===== 64h 65h 66h 67h 68h 69h 6Ah 6Bh 6Ch 6Dh ===6Eh 6Fh  70h 71h 72h |_|
76h====  77h 13h 78h 79h================================ 7Ah 43h 0Dh  5Eh==== 32h 5Ah
```

### type 4, 109-key layouts

- gathered by collating illumos keymaps (see [§ what the keycodes mean in each layout](#what-the-keycodes-mean-in-each-layout)) with some photos found online ([pic de-DE](https://github.com/delan/usb3sun/assets/465303/2aa3ea0e-02fa-488c-a6cb-80acda7aae20), [pic BE fr-FR](https://tinkerdifferent.com/threads/sun-type-4-keyboard.1444/#post-9703))

```
01h 03h  05h 06h 08h 0Ah 0Ch 0Eh 10h 11h 12h 07h 09h 0Bh 58h 0Fh 42h  15h 16h 17h 62h
19h 1Ah  1Dh 1Eh 1Fh 20h 21h 22h 23h 24h 25h 26h 27h 28h 29h ====2Bh  2Dh 2Eh 2Fh 47h
31h 33h  35h== 36h 37h 38h 39h 3Ah 3Bh 3Ch 3Dh 3Eh 3Fh 40h 41h |___|  44h 45h 46h |_|
48h 49h  4Ch=== 4Dh 4Eh 4Fh 50h 51h 52h 53h 54h 55h 56h 57h 2Ah |59h  5Bh 5Ch 5Dh 7Dh
5Fh 61h  63h= 7Ch 64h 65h 66h 67h 68h 69h 6Ah 6Bh 6Ch 6Dh ===6Eh 6Fh  70h 71h 72h |_|
76h====  77h 13h 78h 79h================================ 7Ah 43h 0Dh  5Eh==== 32h 5Ah
```

### type 5, 118-key US/TW/KR

- gathered from *Sun Type 5 Keyboard and Mouse Product Notes* (October 1993, [800-6802-12](https://vtda.org/docs/computing/Sun/hardware/800-6802-12_Type5KeyboardandMouseProductNotes_RevA_Oct93.pdf)), figure 7

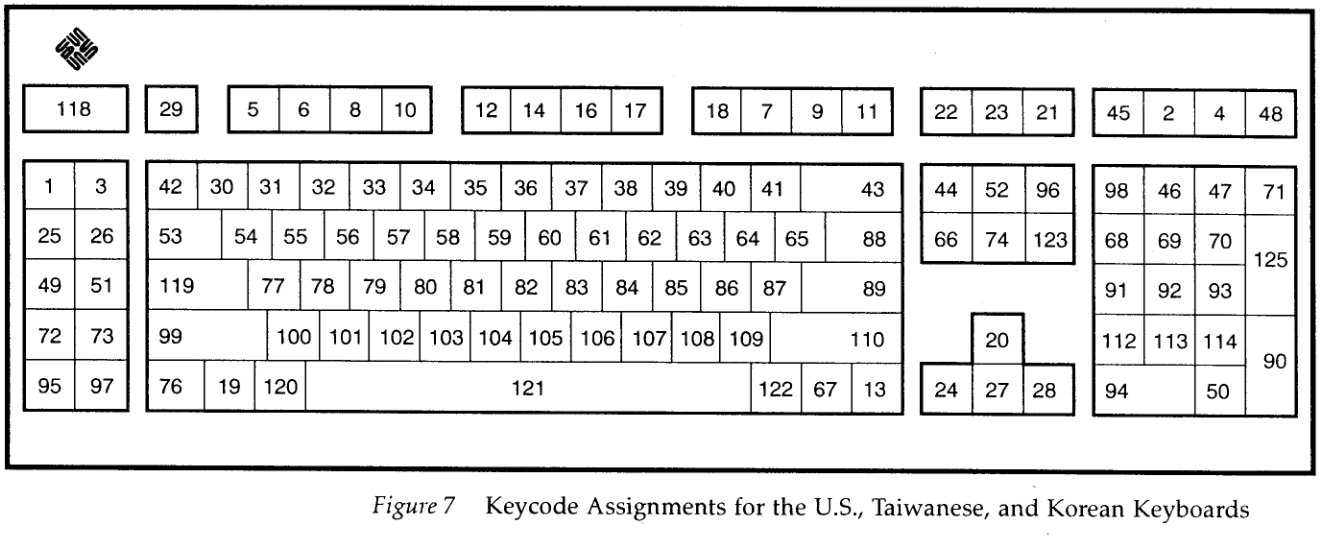
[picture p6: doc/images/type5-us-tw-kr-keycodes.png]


### type 5, 119-key “UNIX”

- gathered from *Sun Type 5 Keyboard and Mouse Product Notes* (October 1993, [800-6802-12](https://vtda.org/docs/computing/Sun/hardware/800-6802-12_Type5KeyboardandMouseProductNotes_RevA_Oct93.pdf)), figure 8

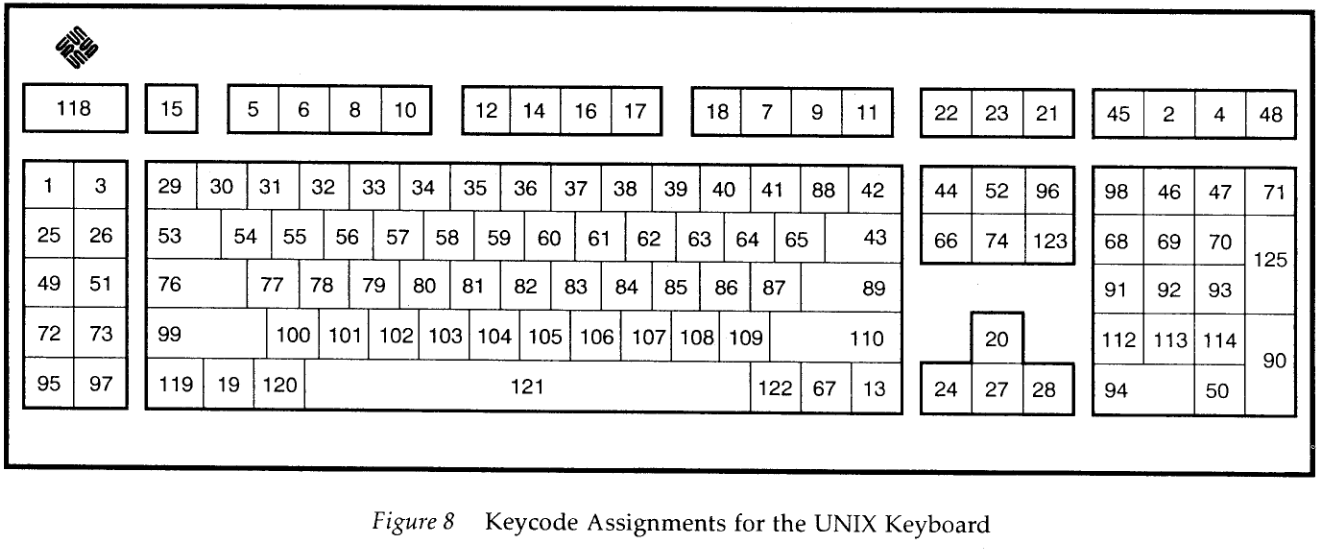
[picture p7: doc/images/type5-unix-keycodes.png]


### type 5, 119-key “TUV-Compliant”

- gathered from *Sun Type 5 Keyboard and Mouse Product Notes* (October 1993, [800-6802-12](https://vtda.org/docs/computing/Sun/hardware/800-6802-12_Type5KeyboardandMouseProductNotes_RevA_Oct93.pdf)), figure 9

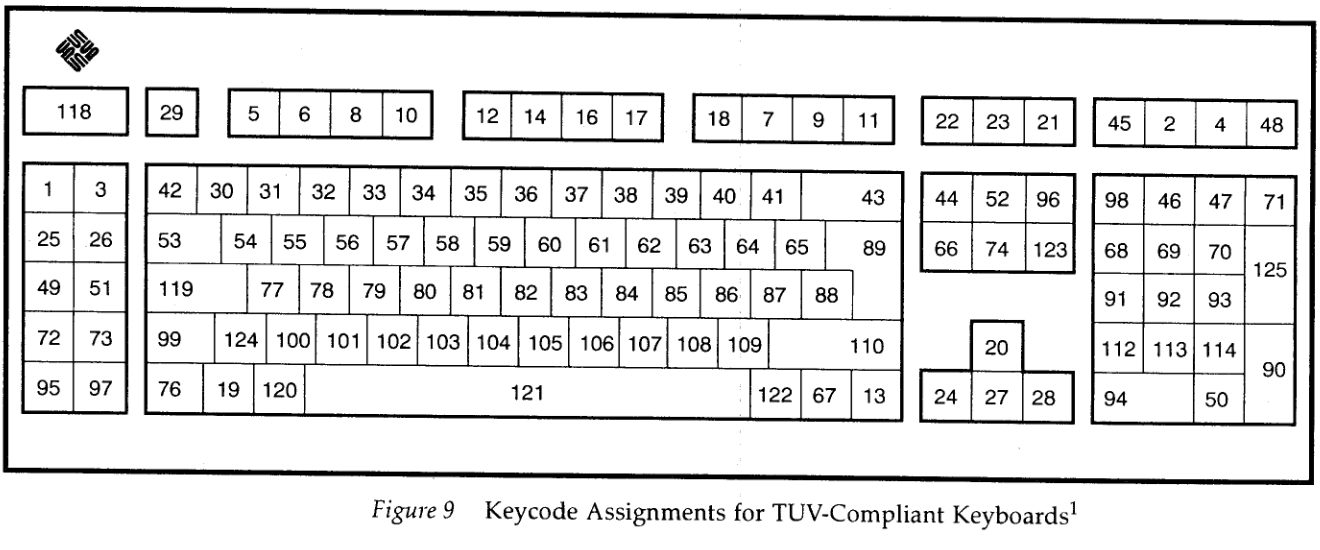
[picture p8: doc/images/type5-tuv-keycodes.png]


### type 5, 122-key JP

- gathered from *Sun Type 5 Keyboard and Mouse Product Notes* (October 1993, [800-6802-12](https://vtda.org/docs/computing/Sun/hardware/800-6802-12_Type5KeyboardandMouseProductNotes_RevA_Oct93.pdf)), figure 10

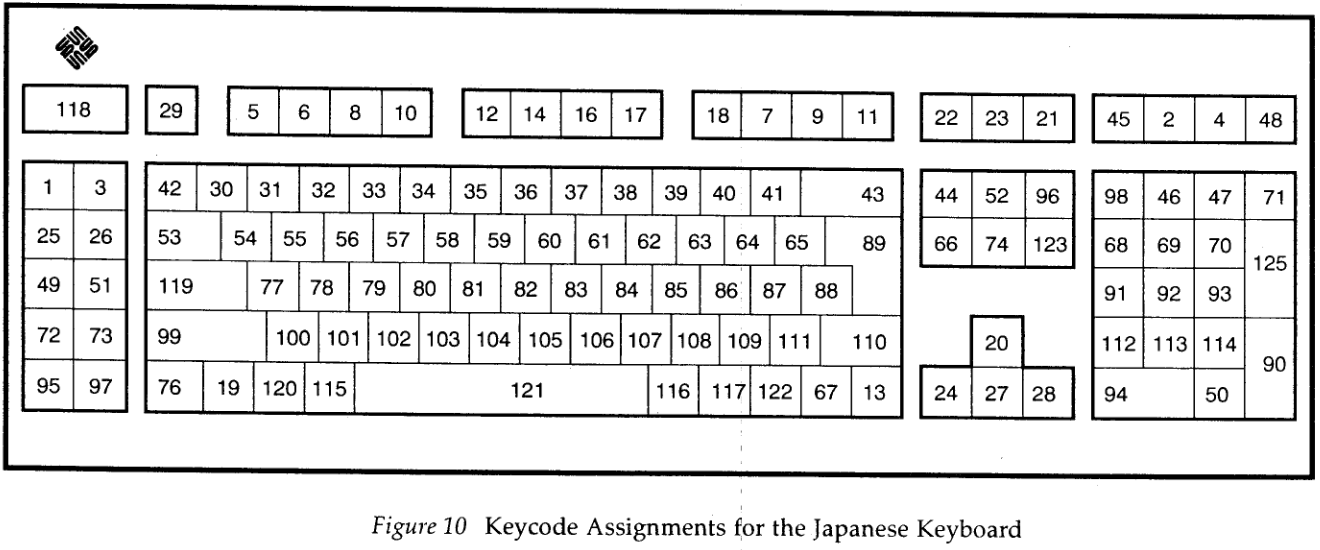
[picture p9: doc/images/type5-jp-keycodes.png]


## what the keycodes mean in each layout

- gathered from the [type 4 (and 5) keymaps](https://github.com/illumos/illumos-gate/tree/616c76953410e11aab663c510c9ba143e545bd4b/usr/src/cmd/loadkeys/type_4) in illumos-gate with [`doc/attic/query-illumos-keymaps.sh`](https://github.com/delan/usb3sun/blob/ce851c6adff445e0aab2189fc1ff3773a01b7e50/doc/attic/query-illumos-keymaps.sh) ([ce851c6adff44](https://github.com/delan/usb3sun/commit/ce851c6adff445e0aab2189fc1ff3773a01b7e50))
  - the layout code associated with each keymap is defined in [the Makefile](https://github.com/illumos/illumos-gate/blob/616c76953410e11aab663c510c9ba143e545bd4b/usr/src/cmd/loadkeys/type_4/Makefile)
- how to understand the output
  - [`src/bindings.h`](https://github.com/delan/usb3sun/blob/ce851c6adff445e0aab2189fc1ff3773a01b7e50/src/bindings.h) as of [ce851c6adff44](https://github.com/delan/usb3sun/commit/ce851c6adff445e0aab2189fc1ff3773a01b7e50) is included for reference
  - `reset` is next, because every keycode inherits its meaning from it if unspecified
  - finally the meanings of the keycode as overriden by other keymaps
  - for more details about the keymap syntax, see [solaris keytables(4)](https://docs.oracle.com/cd/E86824_01/html/E54775/keytables-4.html)

<details><summary>type 4 layouts</summary>

```
0 (00h)
reset:key 0	 all hole

1 (01h)
bindings.h:  {120, 0x01, 0x81}, // Keyboard Stop → 15. Stop
bindings.h:  {1u << 4, 55, 0x01, 0x81}, // CtrlR+. → 15. Stop
reset:key 1	 all buckybits+systembit up buckybits+systembit

2 (02h)
reset:key 2	 all hole

3 (03h)
bindings.h:  {121, 0x03, 0x83}, // Keyboard Again → 16. Again
bindings.h:  {1u << 4, 28, 0x03, 0x83}, // CtrlR+Y → 16. Again
reset:key 3	 all lf(2)

4 (04h)
reset:key 4	 all hole

5 (05h)
bindings.h:  {58, 0x05, 0x85}, // 1. F1
reset:key 5	 all tf(1)

6 (06h)
bindings.h:  {59, 0x06, 0x86}, // 2. F2
reset:key 6	 all tf(2)

7 (07h)
bindings.h:  {67, 0x07, 0x87}, // 10. F10
reset:key 7	 all tf(10)

8 (08h)
bindings.h:  {60, 0x08, 0x88}, // 3. F3
reset:key 8	 all tf(3)

9 (09h)
bindings.h:  {68, 0x09, 0x89}, // 11. F11
reset:key 9	 all tf(11)

10 (0Ah)
bindings.h:  {61, 0x0A, 0x8A}, // 4. F4
reset:key 10	 all tf(4)

11 (0Bh)
bindings.h:  {69, 0x0B, 0x8B}, // 12. F12
reset:key 11	 all tf(12)

12 (0Ch)
bindings.h:  {62, 0x0C, 0x8C}, // 5. F5
reset:key 12	 all tf(5)

13 (0Dh)
bindings.h:  {1u << 6, 0x0D, 0x8D}, // 105. Graph	Alt
reset:key 13	 all shiftkeys+altgraph up shiftkeys+altgraph
us:key 13	 all shiftkeys+altgraph up shiftkeys+altgraph
germany:key 13	 all shiftkeys+alt up shiftkeys+alt
swiss_german:key 13	 all compose
belgium_france:key 13	 all shiftkeys+capslock
uk:key 13	 all shiftkeys+altgraph up shiftkeys+altgraph
swiss_french:key 13	 all compose
netherlands:key 13	 all shiftkeys+capslock
sweden_finland:key 13	 all compose
denmark:key 13	 all compose
norway:key 13	 all shiftkeys+altgraph up shiftkeys+altgraph
italy:key 13	 all shiftkeys+altgraph up shiftkeys+altgraph
spain_latin_america:key 13	 all shiftkeys+altgraph up shiftkeys+altgraph
portugal:key 13	 all shiftkeys+altgraph up shiftkeys+altgraph
canada:key 13	 all shiftkeys+capslock

14 (0Eh)
bindings.h:  {63, 0x0E, 0x8E}, // 6. F6
reset:key 14	 all tf(6)

15 (0Fh)
reset:key 15	 all hole
us:key 15	 all hole
germany:key 15	 base ] shift } caps ] ctrl ^] altg »
swiss_german:key 15	 base > shift } caps > ctrl > altg nop
belgium_france:key 15	 base ] shift } caps ] ctrl ^] altg »
uk:key 15	 all hole
swiss_french:key 15	 base > shift } caps > ctrl > altg nop
netherlands:key 15	 base '\\' shift | caps '\\' ctrl ^\ altg nop
sweden_finland:key 15	 base ~ shift ^ caps ~ ctrl ^^ altg nop
denmark:key 15	 base ~ shift ^ caps ~ ctrl ^^ altg nop
norway:key 15	 base ~ shift ^ caps ~ ctrl ^^ altg nop
italy:key 15	 base ] shift } caps ] ctrl ^] altg »
spain_latin_america:key 15	 base ] shift } caps ] ctrl ^] altg »
portugal:key 15	 base ] shift } caps ] ctrl ^] altg »

16 (10h)
bindings.h:  {64, 0x10, 0x90}, // 7. F7
reset:key 16	 all tf(7)

17 (11h)
bindings.h:  {65, 0x11, 0x91}, // 8. F8
reset:key 17	 all tf(8)

18 (12h)
bindings.h:  {66, 0x12, 0x92}, // 9. F9
reset:key 18	 all tf(9)

19 (13h)
bindings.h:  {1u << 2, 0x13, 0x93}, // 100. Alt
reset:key 19	 all shiftkeys+alt up shiftkeys+alt
us:key 19	 all shiftkeys+alt up shiftkeys+alt
germany:key 19	 all shiftkeys+altgraph up shiftkeys+altgraph
swiss_german:key 19	 all shiftkeys+alt up shiftkeys+alt
belgium_france:key 19	 all shiftkeys+alt up shiftkeys+alt
uk:key 19	 all shiftkeys+alt up shiftkeys+alt
swiss_french:key 19	 all shiftkeys+alt up shiftkeys+alt
netherlands:key 19	 all shiftkeys+alt up shiftkeys+alt
sweden_finland:key 19	 all shiftkeys+alt up shiftkeys+alt
denmark:key 19	 all shiftkeys+alt up shiftkeys+alt
norway:key 19	 all shiftkeys+alt up shiftkeys+alt
italy:key 19	 all shiftkeys+alt up shiftkeys+alt
spain_latin_america:key 19	 all shiftkeys+alt up shiftkeys+alt
portugal:key 19	 all shiftkeys+alt up shiftkeys+alt
canada:key 19	 all shiftkeys+alt up shiftkeys+alt

20 (14h)
reset:key 20	 all hole

21 (15h)
bindings.h:  {72, 0x15, 0x95}, // Pause/Break(!) aka “Keyboard Pause” → 17. Pause
reset:key 21	 all rf(1)

22 (16h)
bindings.h:  {70, 0x16, 0x96}, // PrintScreen/SysRq aka “Keyboard PrintScreen” → 70. Pr Sc
reset:key 22	 all rf(2)

23 (17h)
bindings.h:  {71, 0x17, 0x97}, // Keyboard Scroll Lock → 71. Break(!)	Scroll Lock
reset:key 23	 all rf(3)

24 (18h)
reset:key 24	 all hole

25 (19h)
bindings.h:  {163, 0x19, 0x99}, // Keyboard CrSel/Props → 21. Props
bindings.h:  {1u << 4, 61, 0x19, 0x99}, // CtrlR+F4 → 21. Props
reset:key 25	 all lf(3)

26 (1Ah)
bindings.h:  {122, 0x1A, 0x9A}, // Keyboard Undo → 22. Undo
bindings.h:  {1u << 4, 29, 0x1A, 0x9A}, // CtrlR+Z → 22. Undo
reset:key 26	 all lf(4)

27 (1Bh)
reset:key 27	 all hole

28 (1Ch)
reset:key 28	 all hole

29 (1Dh)
bindings.h:  {41, 0x1D, 0x9D}, // 23. Esc
reset:key 29	 all ^[

30 (1Eh)
bindings.h:  {30, 0x1E, 0x9E}, // 24. 1	!
reset:key 30	 base 1 shift ! caps 1 ctrl 1 altg nop
us:key 30	 base 1 shift ! caps 1 ctrl 1 altg nop
germany:key 30	 base 1 shift ! caps 1 ctrl 1 altg nop
swiss_german:key 30	 base 1 shift + caps 1 ctrl 1 altg !
belgium_france:key 30	 base & shift 1 caps & ctrl & altg nop
uk:key 30	 base 1 shift ! caps 1 ctrl 1 altg |
swiss_french:key 30	 base 1 shift + caps 1 ctrl 1 altg !
netherlands:key 30	 base 1 shift ! caps 1 ctrl 1 altg ¹
sweden_finland:key 30	 base 1 shift ! caps 1 ctrl 1 altg nop
denmark:key 30	 base 1 shift ! caps 1 ctrl 1 altg nop
norway:key 30	 base 1 shift ! caps 1 ctrl 1 altg nop
italy:key 30	 base 1 shift ! caps 1 ctrl 1 altg nop
spain_latin_america:key 30	 base 1 shift ! caps 1 ctrl 1 altg nop
portugal:key 30	 base 1 shift ! caps 1 ctrl 1 altg nop
canada:key 30	 base 1 shift ! caps 1 ctrl 1 altg ±

31 (1Fh)
bindings.h:  {31, 0x1F, 0x9F}, // 25. 2	@
reset:key 31	 base 2 shift @ caps 2 ctrl ^@ altg nop
us:key 31	 base 2 shift @ caps 2 ctrl ^@ altg nop
germany:key 31	 base 2 shift '"' caps 2 ctrl 2 altg ²
swiss_german:key 31	 base 2 shift '"' caps 2 ctrl ^@ altg @
belgium_france:key 31	 base é shift 2 caps E ctrl É altg ²
uk:key 31	 base 2 shift @ caps 2 ctrl ^@ altg nop
swiss_french:key 31	 base 2 shift '"' caps 2 ctrl ^@ altg @
netherlands:key 31	 base 2 shift '"' caps 2 ctrl 2 altg ²
sweden_finland:key 31	 base 2 shift '"' caps 2 ctrl ^@ altg @
denmark:key 31	 base 2 shift '"' caps 2 ctrl ^@ altg @
norway:key 31	 base 2 shift '"' caps 2 ctrl ^@ altg @
italy:key 31	 base 2 shift '"' caps 2 ctrl 2 altg ²
spain_latin_america:key 31	 base 2 shift '"' caps 2 ctrl ^@ altg @
portugal:key 31	 base 2 shift '"' caps 2 ctrl ^@ altg @
canada:key 31	 base 2 shift '"' caps 2 ctrl ^@ altg @

32 (20h)
bindings.h:  {32, 0x20, 0xA0}, // 26. 3	#
reset:key 32	 base 3 shift # caps 3 ctrl 3 altg nop
us:key 32	 base 3 shift # caps 3 ctrl 3 altg nop
germany:key 32	 base 3 shift § caps 3 ctrl 3 altg ³
swiss_german:key 32	 base 3 shift * caps 3 ctrl 3 altg #
belgium_france:key 32	 base '"' shift 3 caps '"' ctrl '"' altg ³
uk:key 32	 base 3 shift £ caps 3 ctrl 3 altg #
swiss_french:key 32	 base 3 shift * caps 3 ctrl 3 altg #
netherlands:key 32	 base 3 shift # caps 3 ctrl 3 altg ³
sweden_finland:key 32	 base 3 shift # caps 3 ctrl 3 altg £
denmark:key 32	 base 3 shift # caps 3 ctrl 3 altg £
norway:key 32	 base 3 shift # caps 3 ctrl 3 altg £
italy:key 32	 base 3 shift £ caps 3 ctrl 3 altg ³
spain_latin_america:key 32	 base 3 shift · caps 3 ctrl 3 altg #
portugal:key 32	 base 3 shift # caps 3 ctrl 3 altg £
canada:key 32	 base 3 shift / caps 3 ctrl 3 altg £

33 (21h)
bindings.h:  {33, 0x21, 0xA1}, // 27. 4	$
reset:key 33	 base 4 shift $ caps 4 ctrl 4 altg nop
us:key 33	 base 4 shift $ caps 4 ctrl 4 altg nop
germany:key 33	 base 4 shift $ caps 4 ctrl 4 altg nop
swiss_german:key 33	 base 4 shift ç caps 4 ctrl 4 altg ¢
belgium_france:key 33	 base '\'' shift 4 caps '\'' ctrl '\'' altg nop
uk:key 33	 base 4 shift $ caps 4 ctrl 4 altg nop
swiss_french:key 33	 base 4 shift ç caps 4 ctrl 4 altg ¢
netherlands:key 33	 base 4 shift $ caps 4 ctrl 4 altg ¼
sweden_finland:key 33	 base 4 shift ¤ caps 4 ctrl 4 altg $
denmark:key 33	 base 4 shift ¤ caps 4 ctrl 4 altg $
norway:key 33	 base 4 shift ¤ caps 4 ctrl 4 altg $
italy:key 33	 base 4 shift $ caps 4 ctrl 4 altg nop
spain_latin_america:key 33	 base 4 shift $ caps 4 ctrl 4 altg nop
portugal:key 33	 base 4 shift $ caps 4 ctrl 4 altg §
canada:key 33	 base 4 shift $ caps 4 ctrl 4 altg ¢

34 (22h)
bindings.h:  {34, 0x22, 0xA2}, // 28. 5	%
reset:key 34	 base 5 shift % caps 5 ctrl 5 altg nop
us:key 34	 base 5 shift % caps 5 ctrl 5 altg nop
germany:key 34	 base 5 shift % caps 5 ctrl 5 altg nop
swiss_german:key 34	 base 5 shift % caps 5 ctrl 5 altg ~
belgium_france:key 34	 base ( shift 5 caps ( ctrl ( altg nop
uk:key 34	 base 5 shift % caps 5 ctrl 5 altg nop
swiss_french:key 34	 base 5 shift % caps 5 ctrl 5 altg ~
netherlands:key 34	 base 5 shift % caps 5 ctrl 5 altg ½
sweden_finland:key 34	 base 5 shift % caps 5 ctrl 5 altg nop
denmark:key 34	 base 5 shift % caps 5 ctrl 5 altg nop
norway:key 34	 base 5 shift % caps 5 ctrl 5 altg nop
italy:key 34	 base 5 shift % caps 5 ctrl 5 altg nop
spain_latin_america:key 34	 base 5 shift % caps 5 ctrl 5 altg °
portugal:key 34	 base 5 shift % caps 5 ctrl 5 altg nop
canada:key 34	 base 5 shift % caps 5 ctrl 5 altg ¤

35 (23h)
bindings.h:  {35, 0x23, 0xA3}, // 29. 6	^
reset:key 35	 base 6 shift ^ caps 6 ctrl ^^ altg nop
us:key 35	 base 6 shift ^ caps 6 ctrl ^^ altg nop
germany:key 35	 base 6 shift & caps 6 ctrl 6 altg nop
swiss_german:key 35	 base 6 shift & caps 6 ctrl 6 altg §
belgium_france:key 35	 base § shift 6 caps § ctrl ^^ altg ^
uk:key 35	 base 6 shift ^ caps 6 ctrl ^^ altg nop
swiss_french:key 35	 base 6 shift & caps 6 ctrl 6 altg §
netherlands:key 35	 base 6 shift & caps 6 ctrl 6 altg ¾
sweden_finland:key 35	 base 6 shift & caps 6 ctrl 6 altg nop
denmark:key 35	 base 6 shift & caps 6 ctrl 6 altg nop
norway:key 35	 base 6 shift & caps 6 ctrl 6 altg nop
italy:key 35	 base 6 shift & caps 6 ctrl 6 altg ¬
spain_latin_america:key 35	 base 6 shift & caps 6 ctrl 6 altg ¬
portugal:key 35	 base 6 shift & caps 6 ctrl 6 altg ¬
canada:key 35	 base 6 shift ? caps 6 ctrl 6 altg ¬

36 (24h)
bindings.h:  {36, 0x24, 0xA4}, // 30. 7	&
reset:key 36	 base 7 shift & caps 7 ctrl 7 altg nop
us:key 36	 base 7 shift & caps 7 ctrl 7 altg nop
germany:key 36	 base 7 shift / caps 7 ctrl 7 altg °
swiss_german:key 36	 base 7 shift / caps 7 ctrl 7 altg |
belgium_france:key 36	 base è shift 7 caps E ctrl è altg nop
uk:key 36	 base 7 shift & caps 7 ctrl 7 altg nop
swiss_french:key 36	 base 7 shift / caps 7 ctrl 7 altg |
netherlands:key 36	 base 7 shift _ caps 7 ctrl ^_ altg £
sweden_finland:key 36	 base 7 shift / caps 7 ctrl 7 altg {
denmark:key 36	 base 7 shift / caps 7 ctrl 7 altg {
norway:key 36	 base 7 shift / caps 7 ctrl 7 altg {
italy:key 36	 base 7 shift / caps 7 ctrl 7 altg nop
spain_latin_america:key 36	 base 7 shift / caps 7 ctrl 7 altg nop
portugal:key 36	 base 7 shift / caps 7 ctrl 7 altg nop
canada:key 36	 base 7 shift & caps 7 ctrl 7 altg |

37 (25h)
bindings.h:  {37, 0x25, 0xA5}, // 31. 8	*
reset:key 37	 base 8 shift * caps 8 ctrl 8 altg nop
us:key 37	 base 8 shift * caps 8 ctrl 8 altg nop
germany:key 37	 base 8 shift ( caps 8 ctrl 8 altg `
swiss_german:key 37	 base 8 shift ( caps 8 ctrl 8 altg °
belgium_france:key 37	 base ! shift 8 caps ! ctrl ! altg £
uk:key 37	 base 8 shift * caps 8 ctrl 8 altg nop
swiss_french:key 37	 base 8 shift ( caps 8 ctrl 8 altg °
netherlands:key 37	 base 8 shift ( caps 8 ctrl 8 altg {
sweden_finland:key 37	 base 8 shift ( caps 8 ctrl ^[ altg [
denmark:key 37	 base 8 shift ( caps 8 ctrl ^[ altg [
norway:key 37	 base 8 shift ( caps 8 ctrl ^[ altg [
italy:key 37	 base 8 shift ( caps 8 ctrl 8 altg nop
spain_latin_america:key 37	 base 8 shift ( caps 8 ctrl 8 altg nop
portugal:key 37	 base 8 shift ( caps 8 ctrl 8 altg nop
canada:key 37	 base 8 shift * caps 8 ctrl 8 altg ²

38 (26h)
bindings.h:  {38, 0x26, 0xA6}, // 32. 9	(
reset:key 38	 base 9 shift ( caps 9 ctrl 9 altg nop
us:key 38	 base 9 shift ( caps 9 ctrl 9 altg nop
germany:key 38	 base 9 shift ) caps 9 ctrl 9 altg '
swiss_german:key 38	 base 9 shift ) caps 9 ctrl ^\ altg '\\'
belgium_france:key 38	 base ç shift 9 caps C ctrl ^\ altg '\\'
uk:key 38	 base 9 shift ( caps 9 ctrl 9 altg nop
swiss_french:key 38	 base 9 shift ) caps 9 ctrl ^\ altg '\\'
netherlands:key 38	 base 9 shift ) caps 9 ctrl ^\ altg }
sweden_finland:key 38	 base 9 shift ) caps 9 ctrl ^] altg ]
denmark:key 38	 base 9 shift ) caps 9 ctrl ^] altg ]
norway:key 38	 base 9 shift ) caps 9 ctrl ^] altg ]
italy:key 38	 base 9 shift ) caps 9 ctrl ^\ altg '\\'
spain_latin_america:key 38	 base 9 shift ) caps 9 ctrl ^\ altg '\\'
portugal:key 38	 base 9 shift ) caps 9 ctrl ^\ altg '\\'
canada:key 38	 base 9 shift ( caps 9 ctrl 9 altg ³

39 (27h)
bindings.h:  {39, 0x27, 0xA7}, // 33. 0	)
reset:key 39	 base 0 shift ) caps 0 ctrl 0 altg nop
us:key 39	 base 0 shift ) caps 0 ctrl 0 altg nop
germany:key 39	 base 0 shift = caps 0 ctrl 0 altg |
swiss_german:key 39	 base 0 shift = caps 0 ctrl ^^ altg ^
belgium_france:key 39	 base à shift 0 caps A ctrl à altg nop
uk:key 39	 base 0 shift ) caps 0 ctrl 0 altg nop
swiss_french:key 39	 base 0 shift = caps 0 ctrl ^^ altg ^
netherlands:key 39	 base 0 shift '\'' caps 0 ctrl 0 altg `
sweden_finland:key 39	 base 0 shift = caps 0 ctrl 0 altg }
denmark:key 39	 base 0 shift = caps 0 ctrl 0 altg }
norway:key 39	 base 0 shift = caps 0 ctrl 0 altg }
italy:key 39	 base 0 shift = caps 0 ctrl 0 altg |
spain_latin_america:key 39	 base 0 shift = caps 0 ctrl 0 altg |
portugal:key 39	 base 0 shift = caps 0 ctrl 0 altg |
canada:key 39	 base 0 shift ) caps 0 ctrl 0 altg ¼

40 (28h)
bindings.h:  {45, 0x28, 0xA8}, // 34. -	_
reset:key 40	 base - shift _ caps - ctrl ^_ altg nop
us:key 40	 base - shift _ caps - ctrl ^_ altg nop
germany:key 40	 base ß shift ? caps ß ctrl ^\ altg '\\' 
swiss_german:key 40	 base '\'' shift ? caps '\'' ctrl '\'' altg `
belgium_france:key 40	 base ) shift ° caps ) ctrl ) altg ~
uk:key 40	 base - shift _ caps - ctrl ^_ altg ¬
swiss_french:key 40	 base '\'' shift ? caps '\'' ctrl '\'' altg `
netherlands:key 40	 base / shift ? caps / ctrl / altg nop
sweden_finland:key 40	 base + shift ? caps + ctrl ^\ altg '\\'
denmark:key 40	 base + shift ? caps + ctrl ^_ altg nop
norway:key 40	 base + shift ? caps + ctrl + altg nop
italy:key 40	 base '\'' shift ? caps '\'' ctrl '\'' altg `
spain_latin_america:key 40	 base '\'' shift ? caps '\'' ctrl ^\ altg `
portugal:key 40	 base '\'' shift ? caps '\'' ctrl '\'' altg `
canada:key 40	 base - shift _ caps - ctrl ^_ altg ½

41 (29h)
bindings.h:  {46, 0x29, 0xA9}, // 35. =	+
reset:key 41	 base = shift + caps = ctrl = altg nop
us:key 41	 base = shift + caps = ctrl = altg nop
germany:key 41	 base fa_acute shift fa_grave caps fa_acute ctrl fa_acute altg nop
swiss_german:key 41	 base fa_cflex shift fa_grave caps fa_cflex ctrl fa_cflex altg nop
belgium_france:key 41	 base - shift _ caps - ctrl ^_ altg #
uk:key 41	 base = shift + caps = ctrl = altg nop
swiss_french:key 41	 base fa_cflex shift fa_grave caps fa_cflex ctrl fa_cflex altg nop
netherlands:key 41	 base ° shift fa_tilde caps ° ctrl ° altg fa_cedilla
sweden_finland:key 41	 base fa_acute shift fa_grave caps fa_acute ctrl fa_acute altg nop
denmark:key 41	 base fa_acute shift fa_grave caps fa_acute ctrl fa_acute altg |
norway:key 41	 base '\\' shift fa_grave caps '\\' ctrl ^\ altg fa_acute
italy:key 41	 base ì shift ^ caps Ì ctrl ^^ altg nop
spain_latin_america:key 41	 base ¡ shift ¿ caps ¡ ctrl ¡ altg nop
portugal:key 41	 base ¡ shift ¿ caps ¡ ctrl ¡ altg nop
canada:key 41	 base = shift + caps = ctrl = altg ¾

42 (2Ah)
bindings.h:  {53, 0x2A, 0xAA}, // 75. `	~
reset:key 42	 base ` shift ~ caps ` ctrl ^^ altg nop
us:key 42	 base ` shift ~ caps ` ctrl ^^ altg nop
germany:key 42	 base # shift ^ caps # ctrl ^^ altg @
swiss_german:key 42	 base $ shift fa_tilde caps $ ctrl $ altg £
belgium_france:key 42	 base * shift | caps * ctrl ^\ altg ¤
uk:key 42	 base ` shift ~ caps ` ctrl ^^ altg nop
swiss_french:key 42	 base $ shift fa_tilde caps $ ctrl $ altg £
netherlands:key 42	 base < shift > caps < ctrl ^] altg nop
sweden_finland:key 42	 base '\'' shift * caps '\'' ctrl ^^ altg `
denmark:key 42	 base '\'' shift * caps '\'' ctrl ^^ altg `
norway:key 42	 base '\'' shift * caps '\'' ctrl '\'' altg `
italy:key 42	 base ù shift § caps U ctrl ù altg nop
spain_latin_america:key 42	 base ç shift Ç caps Ç ctrl ç altg nop
portugal:key 42	 base fa_tilde shift fa_cflex caps fa_tilde ctrl ^^ altg ^
canada:key 42	 base < shift > caps < ctrl ^[ altg }

43 (2Bh)
bindings.h:  {42, 0x2B, 0xAB}, // 36. Backspace
reset:key 43	 all '\b'

44 (2Ch)
reset:key 44	 all hole

45 (2Dh)
bindings.h:  {103, 0x2D, 0xAD}, // Keypad Equal Sign → 37. =
bindings.h:  {1u << 4, 46, 0x2D, 0xAD}, // “Keypad = and +” → 37. =
reset:key 45	 all rf(4) numl padequal

46 (2Eh)
bindings.h:  {84, 0x2E, 0xAE}, // 38. /
reset:key 46	 all rf(5) numl padslash

47 (2Fh)
bindings.h:  {85, 0x2F, 0xAF}, // 39. *
reset:key 47	 all rf(6) numl padstar

48 (30h)
bindings.h:  {102, 0x30, 0xB0}, // keyboard Power → bf(13) Power
bindings.h:  {1u << 4, 19, 0x30, 0xB0}, // CtrlR+P → bf(13) Power
reset:key 48	 all bf(13)

49 (31h)
bindings.h:  {1u << 4, 41, 0x31, 0xB1}, // CtrlR+Esc → 41. Front
reset:key 49	 all lf(5)

50 (32h)
bindings.h:  {99, 0x32, 0xB2}, // 107. Del	.
reset:key 50	 all bf(10) numl paddot

51 (33h)
bindings.h:  {124, 0x33, 0xB3}, // Keyboard Copy → 42. Copy
bindings.h:  {1u << 4, 6, 0x33, 0xB3}, // CtrlR+C → 42. Copy
reset:key 51	 all lf(6)

52 (34h)
reset:key 52	 all hole

53 (35h)
bindings.h:  {43, 0x35, 0xB5}, // 43. Tab
reset:key 53	 all '\t'

54 (36h)
bindings.h:  {20, 0x36, 0xB6}, // 44. Q
reset:key 54	 base q shift Q caps Q ctrl ^Q altg nop
us:key 54	 base q shift Q caps Q ctrl ^Q altg nop
germany:key 54	 base q shift Q caps Q ctrl ^Q altg nop
swiss_german:key 54	 base q shift Q caps Q ctrl ^Q altg nop
belgium_france:key 54	 base a shift A caps A ctrl ^A altg nop
uk:key 54	 base q shift Q caps Q ctrl ^Q altg nop
swiss_french:key 54	 base q shift Q caps Q ctrl ^Q altg nop
netherlands:key 54	 base q shift Q caps Q ctrl ^Q altg nop
sweden_finland:key 54	 base q shift Q caps Q ctrl ^Q altg nop
denmark:key 54	 base q shift Q caps Q ctrl ^Q altg nop
norway:key 54	 base q shift Q caps Q ctrl ^Q altg nop
italy:key 54	 base q shift Q caps Q ctrl ^Q altg nop
spain_latin_america:key 54	 base q shift Q caps Q ctrl ^Q altg nop
portugal:key 54	 base q shift Q caps Q ctrl ^Q altg nop
canada:key 54	 base q shift Q caps Q ctrl ^Q altg nop

55 (37h)
bindings.h:  {26, 0x37, 0xB7}, // 45. W
reset:key 55	 base w shift W caps W ctrl ^W altg nop
us:key 55	 base w shift W caps W ctrl ^W altg nop
germany:key 55	 base w shift W caps W ctrl ^W altg nop
swiss_german:key 55	 base w shift W caps W ctrl ^W altg nop
belgium_france:key 55	 base z shift Z caps Z ctrl ^Z altg nop
uk:key 55	 base w shift W caps W ctrl ^W altg nop
swiss_french:key 55	 base w shift W caps W ctrl ^W altg nop
netherlands:key 55	 base w shift W caps W ctrl ^W altg nop
sweden_finland:key 55	 base w shift W caps W ctrl ^W altg nop
denmark:key 55	 base w shift W caps W ctrl ^W altg nop
norway:key 55	 base w shift W caps W ctrl ^W altg nop
italy:key 55	 base w shift W caps W ctrl ^W altg nop
spain_latin_america:key 55	 base w shift W caps W ctrl ^W altg nop
portugal:key 55	 base w shift W caps W ctrl ^W altg nop
canada:key 55	 base w shift W caps W ctrl ^W altg nop

56 (38h)
bindings.h:  {8, 0x38, 0xB8}, // 46. E
reset:key 56	 base e shift E caps E ctrl ^E altg nop

57 (39h)
bindings.h:  {21, 0x39, 0xB9}, // 47. R
reset:key 57	 base r shift R caps R ctrl ^R altg nop

58 (3Ah)
bindings.h:  {23, 0x3A, 0xBA}, // 48. T
reset:key 58	 base t shift T caps T ctrl ^T altg nop

59 (3Bh)
bindings.h:  {28, 0x3B, 0xBB}, // 49. Y
reset:key 59	 base y shift Y caps Y ctrl ^Y altg nop
us:key 59	 base y shift Y caps Y ctrl ^Y altg nop
germany:key 59	 base z shift Z caps Z ctrl ^Z altg nop
swiss_german:key 59	 base z shift Z caps Z ctrl ^Z altg nop
belgium_france:key 59	 base y shift Y caps Y ctrl ^Y altg nop
uk:key 59	 base y shift Y caps Y ctrl ^Y altg nop
swiss_french:key 59	 base z shift Z caps Z ctrl ^Z altg nop
netherlands:key 59	 base y shift Y caps Y ctrl ^Y altg nop
sweden_finland:key 59	 base y shift Y caps Y ctrl ^Y altg nop
denmark:key 59	 base y shift Y caps Y ctrl ^Y altg nop
norway:key 59	 base y shift Y caps Y ctrl ^Y altg nop
italy:key 59	 base y shift Y caps Y ctrl ^Y altg nop
spain_latin_america:key 59	 base y shift Y caps Y ctrl ^Y altg nop
portugal:key 59	 base y shift Y caps Y ctrl ^Y altg nop
canada:key 59	 base y shift Y caps Y ctrl ^Y altg nop

60 (3Ch)
bindings.h:  {24, 0x3C, 0xBC}, // 50. U
reset:key 60	 base u shift U caps U ctrl ^U altg nop

61 (3Dh)
bindings.h:  {12, 0x3D, 0xBD}, // 51. I
reset:key 61	 base i shift I caps I ctrl '\t' altg nop

62 (3Eh)
bindings.h:  {18, 0x3E, 0xBE}, // 52. O
reset:key 62	 base o shift O caps O ctrl ^O altg nop
us:key 62	 base o shift O caps O ctrl ^O altg nop
germany:key 62	 base o shift O caps O ctrl ^O altg nop
swiss_german:key 62	 base o shift O caps O ctrl ^O altg nop
belgium_france:key 62	 base o shift O caps O ctrl ^O altg nop
uk:key 62	 base o shift O caps O ctrl ^O altg nop
swiss_french:key 62	 base o shift O caps O ctrl ^O altg nop
netherlands:key 62	 base o shift O caps O ctrl ^O altg nop
sweden_finland:key 62	 base o shift O caps O ctrl ^O altg nop
denmark:key 62	 base o shift O caps O ctrl ^O altg nop
norway:key 62	 base o shift O caps O ctrl ^O altg nop
italy:key 62	 base o shift O caps O ctrl ^O altg nop
spain_latin_america:key 62	 base o shift O caps O ctrl ^O altg º
portugal:key 62	 base o shift O caps O ctrl ^O altg nop
canada:key 62	 base o shift O caps O ctrl ^O altg §

63 (3Fh)
bindings.h:  {19, 0x3F, 0xEF}, // 53. P
reset:key 63	 base p shift P caps P ctrl ^P altg nop
us:key 63	 base p shift P caps P ctrl ^P altg nop
germany:key 63	 base p shift P caps P ctrl ^P altg nop
swiss_german:key 63	 base p shift P caps P ctrl ^P altg nop
belgium_france:key 63	 base p shift P caps P ctrl ^P altg nop
uk:key 63	 base p shift P caps P ctrl ^P altg nop
swiss_french:key 63	 base p shift P caps P ctrl ^P altg nop
netherlands:key 63	 base p shift P caps P ctrl ^P altg nop
sweden_finland:key 63	 base p shift P caps P ctrl ^P altg nop
denmark:key 63	 base p shift P caps P ctrl ^P altg nop
norway:key 63	 base p shift P caps P ctrl ^P altg nop
italy:key 63	 base p shift P caps P ctrl ^P altg nop
spain_latin_america:key 63	 base p shift P caps P ctrl ^P altg nop
portugal:key 63	 base p shift P caps P ctrl ^P altg nop
canada:key 63	 base p shift P caps P ctrl ^P altg ¶

64 (40h)
bindings.h:  {47, 0x40, 0xC0}, // 54. [	{
reset:key 64	 base [ shift { caps [ ctrl ^[ altg nop
us:key 64	 base [ shift { caps [ ctrl ^[ altg nop
germany:key 64	 base ü shift Ü caps Ü ctrl ü altg nop
swiss_german:key 64	 base ü shift è caps ü ctrl ü altg nop
belgium_france:key 64	 base fa_cflex shift fa_umlaut caps fa_cflex ctrl fa_cflex altg nop
uk:key 64	 base [ shift { caps [ ctrl ^[ altg nop
swiss_french:key 64	 base è shift ü caps E ctrl è altg nop
netherlands:key 64	 base fa_umlaut shift ^ caps fa_umlaut ctrl ^^ altg fa_cflex
sweden_finland:key 64	 base å shift Å caps Å ctrl å altg nop
denmark:key 64	 base å shift Å caps Å ctrl å altg nop
norway:key 64	 base å shift Å caps Å ctrl å altg nop
italy:key 64	 base è shift é caps E ctrl è altg nop
spain_latin_america:key 64	 base fa_grave shift fa_cflex caps fa_grave ctrl ^^ altg ^
portugal:key 64	 base fa_umlaut shift * caps fa_umlaut ctrl fa_umlaut altg +
canada:key 64   base fa_cflex shift ^ caps fa_cflex ctrl ^^ altg [

65 (41h)
bindings.h:  {48, 0x41, 0xC1}, // 55. ]	}
reset:key 65	 base ] shift } caps ] ctrl ^] altg nop
us:key 65	 base ] shift } caps ] ctrl ^] altg nop
germany:key 65	 base + shift * caps + ctrl + altg ~
swiss_german:key 65	 base fa_umlaut shift fa_acute caps fa_umlaut ctrl fa_umlaut altg nop
belgium_france:key 65	 base ` shift $ caps ` ctrl ^@ altg @
uk:key 65	 base ] shift } caps ] ctrl ^] altg nop
swiss_french:key 65	 base fa_umlaut shift fa_acute caps fa_umlaut ctrl fa_umlaut altg nop
netherlands:key 65	 base * shift ¦ caps * ctrl * altg ~
sweden_finland:key 65	 base fa_umlaut shift fa_cflex caps fa_umlaut ctrl fa_umlaut altg fa_tilde
denmark:key 65	 base fa_umlaut shift fa_cflex caps fa_umlaut ctrl fa_umlaut altg fa_tilde
norway:key 65	 base fa_umlaut shift fa_cflex caps fa_umlaut ctrl fa_umlaut altg fa_tilde
italy:key 65	 base + shift * caps + ctrl + altg ~
spain_latin_america:key 65	 base + shift * caps + ctrl + altg ~
portugal:key 65	 base fa_acute shift fa_grave caps fa_acute ctrl fa_acute altg ~
canada:key 65   base fa_cedilla shift fa_umlaut caps fa_cedilla ctrl ^] altg ]

66 (42h)
bindings.h:  {76, 0x42, 0xC2}, // 14. Delete
reset:key 66	 all '\177'

67 (43h)
bindings.h:  {101, 0x43, 0xC3}, // context menu aka “Keyboard Application” → 101. Compose
reset:key 67	 all compose
us:key 67	 all compose
germany:key 67	 all compose
swiss_german:key 67	 all shiftkeys+altgraph up shiftkeys+altgraph
belgium_france:key 67	 all compose
uk:key 67	 all compose
swiss_french:key 67	 all shiftkeys+altgraph up shiftkeys+altgraph
netherlands:key 67	 all compose
sweden_finland:key 67	 all shiftkeys+altgraph up shiftkeys+altgraph
denmark:key 67	 all shiftkeys+altgraph up shiftkeys+altgraph
norway:key 67	 all compose
italy:key 67	 all compose
spain_latin_america:key 67	 all compose
portugal:key 67	 all compose
canada:key 67	 all compose

68 (44h)
bindings.h:  {95, 0x44, 0xC4}, // 57. Home	7
reset:key 68	 all rf(7) numl pad7

69 (45h)
bindings.h:  {96, 0x45, 0xC5}, // 58. (up cur)	8
reset:key 69	 all string+uparrow numl pad8

70 (46h)
bindings.h:  {97, 0x46, 0xC6}, // 59. PgUp	9
reset:key 70	 all rf(9) numl pad9

71 (47h)
bindings.h:  {86, 0x47, 0xC7}, // 40. -
reset:key 71	 all bf(15) numl padminus

72 (48h)
bindings.h:  {1u << 4, 18, 0x48, 0xC8}, // CtrlR+O → 61. Open
reset:key 72	 all lf(7)

73 (49h)
bindings.h:  {125, 0x49, 0xC9}, // Keyboard Paste → 62. Paste
bindings.h:  {1u << 4, 25, 0x49, 0xC9}, // CtrlR+V → 62. Paste
reset:key 73	 all lf(8)

74 (4Ah)
reset:key 74	 all hole

75 (4Bh)
reset:key 75	 all hole

76 (4Ch)
bindings.h:  {1u << 0, 0x4C, 0xCC}, // CtrlL → 63. Control
reset:key 76	 all shiftkeys+leftctrl up shiftkeys+leftctrl
us:key 76	 all shiftkeys+leftctrl up shiftkeys+leftctrl
germany:key 76	 all shiftkeys+capslock
swiss_german:key 76	 all shiftkeys+capslock
belgium_france:key 76	 all shiftkeys+leftctrl up shiftkeys+leftctrl
uk:key 76	 all shiftkeys+leftctrl up shiftkeys+leftctrl
swiss_french:key 76	 all shiftkeys+capslock
netherlands:key 76	 all shiftkeys+leftctrl up shiftkeys+leftctrl
sweden_finland:key 76	 all shiftkeys+capslock
denmark:key 76	 all shiftkeys+capslock
norway:key 76 	 all shiftkeys+capslock
italy:key 76	 all shiftkeys+capslock
spain_latin_america:key 76	 all shiftkeys+capslock
portugal:key 76	 all shiftkeys+capslock
canada:key 76	 all shiftkeys+leftctrl up shiftkeys+leftctrl

77 (4Dh)
bindings.h:  {4, 0x4D, 0xCD}, // 64. A
reset:key 77	 base a shift A caps A ctrl ^A altg nop
us:key 77	 base a shift A caps A ctrl ^A altg nop
germany:key 77	 base a shift A caps A ctrl ^A altg nop
swiss_german:key 77	 base a shift A caps A ctrl ^A altg nop
belgium_france:key 77	 base q shift Q caps Q ctrl ^Q altg nop
uk:key 77	 base a shift A caps A ctrl ^A altg nop
swiss_french:key 77	 base a shift A caps A ctrl ^A altg nop
netherlands:key 77	 base a shift A caps A ctrl ^A altg nop
sweden_finland:key 77	 base a shift A caps A ctrl ^A altg nop
denmark:key 77	 base a shift A caps A ctrl ^A altg nop
norway:key 77	 base a shift A caps A ctrl ^A altg nop
italy:key 77	 base a shift A caps A ctrl ^A altg nop
spain_latin_america:key 77	 base a shift A caps A ctrl ^A altg ª
portugal:key 77	 base a shift A caps A ctrl ^A altg nop
canada:key 77	 base a shift A caps A ctrl ^A altg nop

78 (4Eh)
bindings.h:  {22, 0x4E, 0xCE}, // 65. S
reset:key 78	 base s shift S caps S ctrl ^S altg nop
us:key 78	 base s shift S caps S ctrl ^S altg nop
germany:key 78	 base s shift S caps S ctrl ^S altg nop
swiss_german:key 78	 base s shift S caps S ctrl ^S altg nop
belgium_france:key 78	 base s shift S caps S ctrl ^S altg nop
uk:key 78	 base s shift S caps S ctrl ^S altg nop
swiss_french:key 78	 base s shift S caps S ctrl ^S altg nop
netherlands:key 78	 base s shift S caps S ctrl ^S altg ß
sweden_finland:key 78	 base s shift S caps S ctrl ^S altg nop
denmark:key 78	 base s shift S caps S ctrl ^S altg nop
norway:key 78	 base s shift S caps S ctrl ^S altg nop
italy:key 78	 base s shift S caps S ctrl ^S altg nop
spain_latin_america:key 78	 base s shift S caps S ctrl ^S altg nop
portugal:key 78	 base s shift S caps S ctrl ^S altg nop
canada:key 78	 base s shift S caps S ctrl ^S altg nop

79 (4Fh)
bindings.h:  {7, 0x4F, 0xCF}, // 66. D
reset:key 79	 base d shift D caps D ctrl ^D altg nop

80 (50h)
bindings.h:  {9, 0x50, 0xD0}, // 67. F
reset:key 80	 base f shift F caps F ctrl ^F altg nop

81 (51h)
bindings.h:  {10, 0x51, 0xD1}, // 68. G
reset:key 81	 base g shift G caps G ctrl ^G altg nop

82 (52h)
bindings.h:  {11, 0x52, 0xD2}, // 69. H
reset:key 82	 base h shift H caps H ctrl '\b' altg nop

83 (53h)
bindings.h:  {13, 0x53, 0xD3}, // 70. J
reset:key 83	 base j shift J caps J ctrl '\n' altg nop

84 (54h)
bindings.h:  {14, 0x54, 0xD4}, // 71. K
reset:key 84	 base k shift K caps K ctrl '\v' altg nop

85 (55h)
bindings.h:  {15, 0x55, 0xD5}, // 72. L
reset:key 85	 base l shift L caps L ctrl ^L altg nop

86 (56h)
bindings.h:  {51, 0x56, 0xD6}, // 73. ;	:
reset:key 86	 base ; shift : caps ; ctrl ; altg nop
us:key 86	 base ; shift : caps ; ctrl ; altg nop
germany:key 86	 base ö shift Ö caps Ö ctrl ö altg nop
swiss_german:key 86	 base ö shift é caps ö ctrl ö altg nop
belgium_france:key 86	 base m shift M caps M ctrl '\r' altg µ
uk:key 86	 base ; shift : caps ; ctrl ; altg nop
swiss_french:key 86	 base é shift ö caps E ctrl é altg nop
netherlands:key 86	 base + shift ± caps + ctrl + altg nop
sweden_finland:key 86	 base ö shift Ö caps Ö ctrl ö altg nop
denmark:key 86	 base æ shift Æ caps Æ ctrl æ altg nop
norway:key 86	 base ø shift Ø caps Ø ctrl ø altg nop
italy:key 86	 base ò shift ç caps O ctrl ^@ altg @
spain_latin_america:key 86	 base ñ shift Ñ caps Ñ ctrl ñ altg nop
portugal:key 86	 base ç shift Ç caps Ç ctrl ç altg nop
canada:key 86	 base ; shift : caps ; ctrl ; altg ~

87 (57h)
bindings.h:  {52, 0x57, 0xD7}, // 74. '	"
reset:key 87	 base '\'' shift '"' caps '\'' ctrl '\'' altg nop
us:key 87	 base '\'' shift '"' caps '\'' ctrl '\'' altg nop
germany:key 87	 base ä shift Ä caps Ä ctrl ä altg nop
swiss_german:key 87	 base ä shift à caps ä ctrl ä altg nop
belgium_france:key 87	 base ù shift % caps U ctrl ù altg nop
uk:key 87	 base '\'' shift '"' caps '\'' ctrl '\'' altg nop
swiss_french:key 87	 base à shift ä caps A ctrl à altg nop
netherlands:key 87	 base fa_acute shift fa_grave caps fa_acute ctrl fa_acute altg nop
sweden_finland:key 87	 base ä shift Ä caps Ä ctrl ä altg nop
denmark:key 87	 base ø shift Ø caps Ø ctrl ø altg nop
norway:key 87	 base æ shift Æ caps Æ ctrl æ altg nop
italy:key 87	 base à shift ° caps A ctrl à altg #
spain_latin_america:key 87	 base fa_acute shift fa_umlaut caps fa_acute ctrl fa_acute altg nop
portugal:key 87	 base º shift ª caps º ctrl º altg nop
canada:key 87	 base fa_grave shift ` caps fa_grave ctrl ` altg {

88 (58h)
bindings.h:  {49, 0x58, 0xD8}, // Keyboard \ and | = 13. \	|
bindings.h:  {100, 0x58, 0xD8}, // Keyboard Non-US \ and | = 13. \	|
reset:key 88	 base '\\' shift | caps '\\' ctrl ^\ altg nop
us:key 88	 base '\\' shift | caps '\\' ctrl ^\ altg nop
germany:key 88	 base [ shift { caps [ ctrl ^[ altg «
swiss_german:key 88	 base < shift { caps < ctrl < altg nop
belgium_france:key 88	 base [ shift { caps [ ctrl ^[ altg «
uk:key 88	 base '\\' shift | caps '\\' ctrl ^\ altg nop
swiss_french:key 88	 base < shift { caps < ctrl < altg nop
netherlands:key 88	 base @ shift § caps @ ctrl ^@ altg '¬'
sweden_finland:key 88	 base § shift ½ caps § ctrl § altg nop
denmark:key 88	 base ½ shift § caps ½ ctrl ½ altg nop
norway:key 88	 base | shift § caps | ctrl | altg nop
italy:key 88	 base [ shift { caps [ ctrl ^[ altg «
spain_latin_america:key 88	 base [ shift { caps [ ctrl ^[ altg «
portugal:key 88	 base [ shift { caps [ ctrl ^[ altg «
canada:key 88	 base # shift | caps # ctrl ^\ altg '\\'

89 (59h)
bindings.h:  {40, 0x59, 0xD9}, // Keyboard Return (ENTER) (*not* “Keyboard Return”) → 56. Return
bindings.h:  {158, 0x59, 0xD9}, // Keyboard Return (*not* “Keyboard Return (ENTER)”) → 56. Return
reset:key 89	 all '\r'

90 (5Ah)
bindings.h:  {88, 0x5A, 0xDA}, // Keypad ENTER → 97. Enter
reset:key 90	 all bf(11) numl padenter

91 (5Bh)
bindings.h:  {92, 0x5B, 0xDB}, // 76. (Left Cur)	4
reset:key 91	 all string+leftarrow numl pad4

92 (5Ch)
bindings.h:  {93, 0x5C, 0xDC}, // 77. 5
reset:key 92	 all rf(11) numl pad5

93 (5Dh)
bindings.h:  {94, 0x5D, 0xDD}, // 78. (Right Cur)	6
reset:key 93	 all string+rightarrow numl pad6

94 (5Eh)
bindings.h:  {98, 0x5E, 0xDE}, // 106. Ins	0
reset:key 94	 all bf(8) numl pad0

95 (5Fh)
bindings.h:  {126, 0x5F, 0xDF}, // Keyboard Find → 79. Find
bindings.h:  {1u << 4, 9, 0x5F, 0xDF}, // CtrlR+F → 79. Find
reset:key 95	 all lf(9)

96 (60h)
reset:key 96	 all hole

97 (61h)
bindings.h:  {123, 0x61, 0xE1}, // Keyboard Cut → 80. Cut
bindings.h:  {1u << 4, 27, 0x61, 0xE1}, // CtrlR+X → 80. Cut
reset:key 97	 all lf(10)

98 (62h)
bindings.h:  {83, 0x62, 0xE2}, // 20. Num Lock
reset:key 98	 all shiftkeys+numlock

99 (63h)
bindings.h:  {1u << 1, 0x63, 0xE3}, // 81. left “Shift”
reset:key 99	 all shiftkeys+leftshift up shiftkeys+leftshift

100 (64h)
bindings.h:  {29, 0x64, 0xE4}, // 82. Z
reset:key 100	 base z shift Z caps Z ctrl ^Z altg nop
us:key 100	 base z shift Z caps Z ctrl ^Z altg nop
germany:key 100	 base y shift Y caps Y ctrl ^Y altg nop
swiss_german:key 100	 base y shift Y caps Y ctrl ^Y altg nop
belgium_france:key 100	 base w shift W caps W ctrl ^W altg nop
uk:key 100	 base z shift Z caps Z ctrl ^Z altg nop
swiss_french:key 100	 base y shift Y caps Y ctrl ^Y altg nop
netherlands:key 100	 base z shift Z caps Z ctrl ^Z altg «
sweden_finland:key 100	 base z shift Z caps Z ctrl ^Z altg nop
denmark:key 100	 base z shift Z caps Z ctrl ^Z altg nop
denmark:key 100	 base z shift Z caps Z ctrl ^Z altg nop
norway:key 100	 base z shift Z caps Z ctrl ^Z altg nop
italy:key 100	 base z shift Z caps Z ctrl ^Z altg nop
spain_latin_america:key 100	 base z shift Z caps Z ctrl ^Z altg nop
portugal:key 100	 base z shift Z caps Z ctrl ^Z altg nop
canada:key 100	 base z shift Z caps Z ctrl ^Z altg nop

101 (65h)
bindings.h:  {27, 0x65, 0xE5}, // 83. X
reset:key 101	 base x shift X caps X ctrl ^X altg nop
us:key 101  base x shift X caps X ctrl ^X altg nop
germany:key 101  base x shift X caps X ctrl ^X altg nop
swiss_german:key 101  base x shift X caps X ctrl ^X altg nop
belgium_france:key 101  base x shift X caps X ctrl ^X altg nop
uk:key 101  base x shift X caps X ctrl ^X altg nop
swiss_french:key 101  base x shift X caps X ctrl ^X altg nop
netherlands:key 101  base x shift X caps X ctrl ^X altg »
sweden_finland:key 101  base x shift X caps X ctrl ^X altg nop
denmark:key 101  base x shift X caps X ctrl ^X altg nop
italy:key 101  base x shift X caps X ctrl ^X altg nop
spain_latin_america:key 101  base x shift X caps X ctrl ^X altg nop
portugal:key 101  base x shift X caps X ctrl ^X altg nop
canada:key 101  base x shift X caps X ctrl ^X altg nop

102 (66h)
bindings.h:  {6, 0x66, 0xE6}, // 84. C
reset:key 102	 base c shift C caps C ctrl ^C altg nop
us:key 102	 base c shift C caps C ctrl ^C altg nop
germany:key 102	 base c shift C caps C ctrl ^C altg nop
swiss_german:key 102	 base c shift C caps C ctrl ^C altg nop
belgium_france:key 102	 base c shift C caps C ctrl ^C altg nop
uk:key 102	 base c shift C caps C ctrl ^C altg nop
swiss_french:key 102	 base c shift C caps C ctrl ^C altg nop
netherlands:key 102	 base c shift C caps C ctrl ^C altg ¢
sweden_finland:key 102	 base c shift C caps C ctrl ^C altg nop
denmark:key 102	 base c shift C caps C ctrl ^C altg nop
norway:key 102	 base c shift C caps C ctrl ^C altg nop
italy:key 102	 base c shift C caps C ctrl ^C altg nop
spain_latin_america:key 102	 base c shift C caps C ctrl ^C altg nop
portugal:key 102	 base c shift C caps C ctrl ^C altg nop
canada:key 102	 base c shift C caps C ctrl ^C altg nop

103 (67h)
bindings.h:  {25, 0x67, 0xE7}, // 85. V
reset:key 103	 base v shift V caps V ctrl ^V altg nop
us:key 103  base v shift V caps V ctrl ^V altg nop
germany:key 103  base v shift V caps V ctrl ^V altg nop
swiss_german:key 103  base v shift V caps V ctrl ^V altg nop
belgium_france:key 103  base v shift V caps V ctrl ^V altg nop
uk:key 103  base v shift V caps V ctrl ^V altg nop
swiss_french:key 103  base v shift V caps V ctrl ^V altg nop
netherlands:key 103  base v shift V caps V ctrl ^V altg nop
sweden_finland:key 103  base v shift V caps V ctrl ^V altg nop
denmark:key 103  base v shift V caps V ctrl ^V altg nop
italy:key 103  base v shift V caps V ctrl ^V altg nop
spain_latin_america:key 103  base v shift V caps V ctrl ^V altg nop
portugal:key 103  base v shift V caps V ctrl ^V altg nop
canada:key 103  base v shift V caps V ctrl ^V altg «

104 (68h)
bindings.h:  {5, 0x68, 0xE8}, // 86. B
reset:key 104	 base b shift B caps B ctrl ^B altg nop
us:key 104  base b shift B caps B ctrl ^B altg nop
germany:key 104  base b shift B caps B ctrl ^B altg nop
swiss_german:key 104  base b shift B caps B ctrl ^B altg nop
belgium_france:key 104  base b shift B caps B ctrl ^B altg nop
uk:key 104  base b shift B caps B ctrl ^B altg nop
swiss_french:key 104  base b shift B caps B ctrl ^B altg nop
netherlands:key 104  base b shift B caps B ctrl ^B altg nop
sweden_finland:key 104  base b shift B caps B ctrl ^B altg nop
denmark:key 104  base b shift B caps B ctrl ^B altg nop
italy:key 104  base b shift B caps B ctrl ^B altg nop
spain_latin_america:key 104  base b shift B caps B ctrl ^B altg nop
portugal:key 104  base b shift B caps B ctrl ^B altg nop
canada:key 104  base b shift B caps B ctrl ^B altg »

105 (69h)
bindings.h:  {17, 0x69, 0xE9}, // 87. N
reset:key 105	 base n shift N caps N ctrl ^N altg nop
us:key 105	 base n shift N caps N ctrl ^N altg nop
germany:key 105	 base n shift N caps N ctrl ^N altg nop
swiss_german:key 105	 base n shift N caps N ctrl ^N altg nop
belgium_france:key 105	 base n shift N caps N ctrl ^N altg nop
uk:key 105	 base n shift N caps N ctrl ^N altg nop
swiss_french:key 105	 base n shift N caps N ctrl ^N altg nop
netherlands:key 105	 base n shift N caps N ctrl ^N altg nop
sweden_finland:key 105	 base n shift N caps N ctrl ^N altg nop
denmark:key 105	 base n shift N caps N ctrl ^N altg nop
norway:key 105	 base n shift N caps N ctrl ^N altg nop
italy:key 105	 base n shift N caps N ctrl ^N altg nop
spain_latin_america:key 105	 base n shift N caps N ctrl ^N altg nop
portugal:key 105	 base n shift N caps N ctrl ^N altg nop
canada:key 105	 base n shift N caps N ctrl ^N altg °

106 (6Ah)
bindings.h:  {16, 0x6A, 0xEA}, // 88. M
reset:key 106	 base m shift M caps M ctrl '\r' altg nop
us:key 106	 base m shift M caps M ctrl '\r' altg nop
germany:key 106	 base m shift M caps M ctrl '\r' altg µ
swiss_german:key 106	 base m shift M caps M ctrl '\r' altg µ
belgium_france:key 106	 base , shift ? caps , ctrl , altg nop
uk:key 106	 base m shift M caps M ctrl '\r' altg nop
swiss_french:key 106	 base m shift M caps M ctrl '\r' altg µ
netherlands:key 106	 base m shift M caps M ctrl '\r' altg µ
sweden_finland:key 106	 base m shift M caps M ctrl '\r' altg nop
denmark:key 106	 base m shift M caps M ctrl '\r' altg nop
norway:key 106	 base m shift M caps M ctrl '\r' altg nop
italy:key 106	 base m shift M caps M ctrl '\r' altg nop
spain_latin_america:key 106	 base m shift M caps M ctrl '\r' altg nop
portugal:key 106	 base m shift M caps M ctrl '\r' altg nop
canada:key 106	 base m shift M caps M ctrl '\r' altg µ

107 (6Bh)
bindings.h:  {54, 0x6B, 0xEB}, // 89. ,	<
reset:key 107	 base , shift < caps , ctrl , altg nop
us:key 107	 base , shift < caps , ctrl , altg nop
germany:key 107	 base , shift ; caps , ctrl , altg nop
swiss_german:key 107	 base , shift ; caps , ctrl , altg nop
belgium_france:key 107	 base ; shift . caps ; ctrl ; altg nop
uk:key 107	 base , shift < caps , ctrl , altg nop
swiss_french:key 107	 base , shift ; caps , ctrl , altg nop
netherlands:key 107	 base , shift ; caps , ctrl , altg nop
sweden_finland:key 107	 base , shift ; caps , ctrl , altg nop
denmark:key 107	 base , shift ; caps , ctrl , altg nop
norway:key 107	 base , shift ; caps , ctrl , altg nop
italy:key 107	 base , shift ; caps , ctrl , altg nop
spain_latin_america:key 107	 base , shift ; caps , ctrl , altg nop
portugal:key 107	 base , shift ; caps , ctrl , altg nop
canada:key 107	 base , shift '\'' caps , ctrl , altg ¯

108 (6Ch)
bindings.h:  {55, 0x6C, 0xEC}, // 90. .	>
reset:key 108	 base . shift > caps . ctrl . altg nop
us:key 108	 base . shift > caps . ctrl . altg nop
germany:key 108	 base . shift : caps . ctrl . altg nop
swiss_german:key 108	 base . shift : caps . ctrl . altg nop
belgium_france:key 108	 base : shift / caps : ctrl : altg nop
uk:key 108	 base . shift > caps . ctrl . altg nop
swiss_french:key 108	 base . shift : caps . ctrl . altg nop
netherlands:key 108	 base . shift : caps . ctrl . altg nop
sweden_finland:key 108	 base . shift : caps . ctrl . altg nop
denmark:key 108	 base . shift : caps . ctrl . altg nop
norway:key 108	 base . shift : caps . ctrl . altg nop
italy:key 108	 base . shift : caps . ctrl . altg nop
spain_latin_america:key 108	 base . shift : caps . ctrl . altg nop
portugal:key 108	 base . shift : caps . ctrl . altg nop
canada:key 108	 base . shift . caps . ctrl . altg nop

109 (6Dh)
bindings.h:  {56, 0x6D, 0xED}, // 91. /	?
reset:key 109	 base / shift ? caps / ctrl ^_ altg nop
us:key 109	 base / shift ? caps / ctrl ^_ altg nop
germany:key 109	 base - shift _ caps - ctrl ^_ altg nop
swiss_german:key 109	 base - shift _ caps - ctrl ^_ altg nop
belgium_france:key 109	 base = shift + caps = ctrl = altg nop
uk:key 109	 base / shift ? caps / ctrl ^_ altg nop
swiss_french:key 109	 base - shift _ caps - ctrl ^_ altg nop
netherlands:key 109	 base - shift = caps - ctrl ^_ altg nop
sweden_finland:key 109	 base - shift _ caps - ctrl ^_ altg nop
denmark:key 109	 base - shift _ caps - ctrl ^_ altg nop
norway:key 109	 base - shift _ caps - ctrl ^_ altg nop
italy:key 109	 base - shift _ caps - ctrl ^_ altg nop
spain_latin_america:key 109	 base - shift _ caps - ctrl ^_ altg nop
portugal:key 109	 base - shift _ caps - ctrl ^_ altg nop
canada:key 109	 base é shift É caps É ctrl é altg fa_acute

110 (6Eh)
bindings.h:  {1u << 5, 0x6E, 0xEE}, // 92. right “Shift”
reset:key 110	 all shiftkeys+rightshift up shiftkeys+rightshift

111 (6Fh)
bindings.h:  {1u << 4, 40, 0x6F, 0xEF}, // CtrlR + Keyboard Return (ENTER) → 93. Line Feed
reset:key 111	 all '\n'

112 (70h)
bindings.h:  {89, 0x70, 0xF0}, // 94. End	1
reset:key 112	 all rf(13) numl pad1

113 (71h)
bindings.h:  {90, 0x71, 0xF1}, // 95. (Dn Cur)	2
reset:key 113	 all string+downarrow numl pad2

114 (72h)
bindings.h:  {91, 0x72, 0xF2}, // 96. PgDn	3
reset:key 114	 all rf(15) numl pad3

115 (73h)
reset:key 115	 all hole

116 (74h)
reset:key 116	 all hole

117 (75h)
reset:key 117	 all hole

118 (76h)
bindings.h:  {117, 0x76, 0xF6}, // Keyboard Help → 98. Help
bindings.h:  {1u << 4, 58, 0x76, 0xF6}, // CtrlR+F1 → 98. Help
reset:key 118	 all lf(16)

119 (77h)
bindings.h:  {57, 0x77, 0xF7}, // 99. Caps Lock
reset:key 119	 all shiftkeys+capslock
us:key 119	 all shiftkeys+capslock
germany:key 119	 all shiftkeys+leftctrl up shiftkeys+leftctrl
swiss_german:key 119	 all shiftkeys+leftctrl up shiftkeys+leftctrl
belgium_france:key 119	 all shiftkeys+altgraph up shiftkeys+altgraph
uk:key 119	 all shiftkeys+capslock
swiss_french:key 119	 all shiftkeys+leftctrl up shiftkeys+leftctrl
netherlands:key 119	 all shiftkeys+altgraph up shiftkeys+altgraph
sweden_finland:key 119	 all shiftkeys+leftctrl up shiftkeys+leftctrl
denmark:key 119	 all shiftkeys+leftctrl up shiftkeys+leftctrl
norway:key 119	 all shiftkeys+leftctrl up shiftkeys+leftctrl
italy:key 119	 all shiftkeys+leftctrl up shiftkeys+leftctrl
spain_latin_america:key 119	 all shiftkeys+leftctrl up shiftkeys+leftctrl
portugal:key 119	 all shiftkeys+leftctrl up shiftkeys+leftctrl
canada:key 119	 all shiftkeys+altgraph up shiftkeys+altgraph

120 (78h)
bindings.h:  {1u << 3, 0x78, 0xF8}, // 101. left meta aka “(L Triangle)”
reset:key 120	 all buckybits+metabit up buckybits+metabit

121 (79h)
bindings.h:  {44, 0x79, 0xF9}, // 102. (Space Bar)
reset:key 121	 base ' ' shift ' ' caps ' ' ctrl ^@ altg ' '

122 (7Ah)
bindings.h:  {1u << 7, 0x7A, 0xFA}, // 102. right meta aka “(R triangle)”
reset:key 122	 all buckybits+metabit up buckybits+metabit

123 (7Bh)
reset:key 123	 all hole

124 (7Ch)
reset:key 124	 all hole
us:key 124	 all hole
germany:key 124	 base < shift > caps < ctrl < altg nop numl nonl
swiss_german:key 124	 base ] shift [ caps ] ctrl ^] altg '\\' numl nonl
belgium_france:key 124	 base < shift > caps < ctrl < altg nop numl nonl
uk:key 124	 all hole
swiss_french:key 124	 base ] shift [ caps ] ctrl ^] altg '\\' numl nonl
netherlands:key 124	 base ] shift [ caps ] ctrl ^[ altg nop numl nonl
sweden_finland:key 124	 base < shift > caps < ctrl ^\ altg | numl nonl
denmark:key 124	 base < shift > caps < ctrl ^\ altg '\\' numl nonl
norway:key 124	 base < shift > caps < ctrl < altg nop numl nonl
italy:key 124	 base < shift > caps < ctrl < altg nop numl nonl
spain_latin_america:key 124	 base < shift > caps < ctrl < altg nop numl nonl
portugal:key 124	 base < shift > caps < ctrl < altg nop numl nonl
canada:key 124	 base « shift » caps « ctrl « altg ° numl nonl

125 (7Dh)
bindings.h:  {87, 0x7D, 0xFD}, // 60. +
reset:key 125	 all bf(14) numl padplus

126 (7Eh)
reset:key 126	 all error numl error up hole

127 (7Fh)
reset:key 127	 all idle numl idle up reset
```
</details>

<details><summary>type 5 layouts</summary>

```
0 (00h)
reset:key 0	 all hole

1 (01h)
bindings.h:  {120, 0x01, 0x81}, // Keyboard Stop → 15. Stop
bindings.h:  {1u << 4, 55, 0x01, 0x81}, // CtrlR+. → 15. Stop
reset:key 1	 all buckybits+systembit up buckybits+systembit

2 (02h)
reset:key 2	 all hole

3 (03h)
bindings.h:  {121, 0x03, 0x83}, // Keyboard Again → 16. Again
bindings.h:  {1u << 4, 28, 0x03, 0x83}, // CtrlR+Y → 16. Again
reset:key 3	 all lf(2)

4 (04h)
reset:key 4	 all hole

5 (05h)
bindings.h:  {58, 0x05, 0x85}, // 1. F1
reset:key 5	 all tf(1)

6 (06h)
bindings.h:  {59, 0x06, 0x86}, // 2. F2
reset:key 6	 all tf(2)

7 (07h)
bindings.h:  {67, 0x07, 0x87}, // 10. F10
reset:key 7	 all tf(10)

8 (08h)
bindings.h:  {60, 0x08, 0x88}, // 3. F3
reset:key 8	 all tf(3)

9 (09h)
bindings.h:  {68, 0x09, 0x89}, // 11. F11
reset:key 9	 all tf(11)

10 (0Ah)
bindings.h:  {61, 0x0A, 0x8A}, // 4. F4
reset:key 10	 all tf(4)

11 (0Bh)
bindings.h:  {69, 0x0B, 0x8B}, // 12. F12
reset:key 11	 all tf(12)

12 (0Ch)
bindings.h:  {62, 0x0C, 0x8C}, // 5. F5
reset:key 12	 all tf(5)

13 (0Dh)
bindings.h:  {1u << 6, 0x0D, 0x8D}, // 105. Graph	Alt
reset:key 13	 all shiftkeys+altgraph up shiftkeys+altgraph
japan_5:key 13         all bf(4)
korea_5:key 13  all bf(3)
traditional_chinese_5:key 13	all bf(3)
us_5:key 13	 all shiftkeys+altgraph up shiftkeys+altgraph

14 (0Eh)
bindings.h:  {63, 0x0E, 0x8E}, // 6. F6
reset:key 14	 all tf(6)

15 (0Fh)
reset:key 15	 all hole
sweden_5:key 15	 base ~ shift ^ caps ~ ctrl ^^ altg nop
us_5:key 15	 all hole

16 (10h)
bindings.h:  {64, 0x10, 0x90}, // 7. F7
reset:key 16	 all tf(7)

17 (11h)
bindings.h:  {65, 0x11, 0x91}, // 8. F8
reset:key 17	 all tf(8)

18 (12h)
bindings.h:  {66, 0x12, 0x92}, // 9. F9
reset:key 18	 all tf(9)

19 (13h)
bindings.h:  {1u << 2, 0x13, 0x93}, // 100. Alt
reset:key 19	 all shiftkeys+alt up shiftkeys+alt
us_5:key 19	 all shiftkeys+alt up shiftkeys+alt

20 (14h)
reset:key 20	 all hole
canadian_french_5:key 20   all string+uparrow
czech_5:key 20   all string+uparrow
denmark_5:key 20   all string+uparrow
france_5:key 20   all string+uparrow
germany_5:key 20   all string+uparrow
hungary_5:key 20   all string+uparrow
italy_5:key 20   all string+uparrow
japan_5:key 20   all string+uparrow
korea_5:key 20   all string+uparrow
netherlands_5:key 20   all string+uparrow
norway_5:key 20   all string+uparrow
poland_5:key 20   all string+uparrow
portugal_5:key 20   all string+uparrow
russia_5:key 20   all string+uparrow
spain_5:key 20   all string+uparrow
sweden_5:key 20   all string+uparrow
swiss_french_5:key 20   all string+uparrow
swiss_german_5:key 20   all string+uparrow
traditional_chinese_5:key 20   all string+uparrow
uk_5:key 20   all string+uparrow
us_5:key 20   all string+uparrow

21 (15h)
bindings.h:  {72, 0x15, 0x95}, // Pause/Break(!) aka “Keyboard Pause” → 17. Pause
reset:key 21	 all rf(1)

22 (16h)
bindings.h:  {70, 0x16, 0x96}, // PrintScreen/SysRq aka “Keyboard PrintScreen” → 70. Pr Sc
reset:key 22	 all rf(2)

23 (17h)
bindings.h:  {71, 0x17, 0x97}, // Keyboard Scroll Lock → 71. Break(!)	Scroll Lock
reset:key 23	 all rf(3)

24 (18h)
reset:key 24	 all hole
canadian_french_5:key 24   all string+leftarrow
czech_5:key 24   all string+leftarrow
denmark_5:key 24   all string+leftarrow
france_5:key 24   all string+leftarrow
germany_5:key 24   all string+leftarrow
hungary_5:key 24   all string+leftarrow
italy_5:key 24   all string+leftarrow
japan_5:key 24   all string+leftarrow
korea_5:key 24   all string+leftarrow
netherlands_5:key 24   all string+leftarrow
norway_5:key 24   all string+leftarrow
poland_5:key 24   all string+leftarrow
portugal_5:key 24   all string+leftarrow
russia_5:key 24   all string+leftarrow
spain_5:key 24   all string+leftarrow
sweden_5:key 24   all string+leftarrow
swiss_french_5:key 24   all string+leftarrow
swiss_german_5:key 24   all string+leftarrow
traditional_chinese_5:key 24   all string+leftarrow
uk_5:key 24   all string+leftarrow
us_5:key 24   all string+leftarrow

25 (19h)
bindings.h:  {163, 0x19, 0x99}, // Keyboard CrSel/Props → 21. Props
bindings.h:  {1u << 4, 61, 0x19, 0x99}, // CtrlR+F4 → 21. Props
reset:key 25	 all lf(3)

26 (1Ah)
bindings.h:  {122, 0x1A, 0x9A}, // Keyboard Undo → 22. Undo
bindings.h:  {1u << 4, 29, 0x1A, 0x9A}, // CtrlR+Z → 22. Undo
reset:key 26	 all lf(4)

27 (1Bh)
reset:key 27	 all hole
canadian_french_5:key 27   all string+downarrow
czech_5:key 27   all string+downarrow
denmark_5:key 27   all string+downarrow
france_5:key 27   all string+downarrow
germany_5:key 27   all string+downarrow
hungary_5:key 27   all string+downarrow
italy_5:key 27   all string+downarrow
japan_5:key 27   all string+downarrow
korea_5:key 27   all string+downarrow
netherlands_5:key 27   all string+downarrow
norway_5:key 27   all string+downarrow
poland_5:key 27   all string+downarrow
portugal_5:key 27   all string+downarrow
russia_5:key 27   all string+downarrow
spain_5:key 27   all string+downarrow
sweden_5:key 27   all string+downarrow
swiss_french_5:key 27   all string+downarrow
swiss_german_5:key 27   all string+downarrow
traditional_chinese_5:key 27   all string+downarrow
uk_5:key 27   all string+downarrow
us_5:key 27   all string+downarrow

28 (1Ch)
reset:key 28	 all hole
canadian_french_5:key 28   all string+rightarrow
czech_5:key 28   all string+rightarrow
denmark_5:key 28   all string+rightarrow
france_5:key 28   all string+rightarrow
germany_5:key 28   all string+rightarrow
hungary_5:key 28   all string+rightarrow
italy_5:key 28   all string+rightarrow
japan_5:key 28   all string+rightarrow
korea_5:key 28   all string+rightarrow
netherlands_5:key 28   all string+rightarrow
norway_5:key 28   all string+rightarrow
poland_5:key 28   all string+rightarrow
portugal_5:key 28   all string+rightarrow
russia_5:key 28   all string+rightarrow
spain_5:key 28   all string+rightarrow
sweden_5:key 28   all string+rightarrow
swiss_french_5:key 28   all string+rightarrow
swiss_german_5:key 28   all string+rightarrow
traditional_chinese_5:key 28   all string+rightarrow
uk_5:key 28   all string+rightarrow
us_5:key 28   all string+rightarrow

29 (1Dh)
bindings.h:  {41, 0x1D, 0x9D}, // 23. Esc
reset:key 29	 all ^[

30 (1Eh)
bindings.h:  {30, 0x1E, 0x9E}, // 24. 1	!
reset:key 30	 base 1 shift ! caps 1 ctrl 1 altg nop
canadian_french_5:key 30	 base 1 shift ! caps 1 ctrl 1 altg ±
czech_5:key 30	 base + shift 1 caps + ctrl nop altg +
france_5:key 30	 base & shift 1 caps & ctrl & altg nop
germany_5:key 30   base 1 shift ! caps 1 ctrl 1 altg nop
hungary_5:key 30   base 1 shift '\'' caps 1 ctrl 1 altg nop
netherlands_5:key 30	 base 1 shift ! caps 1 ctrl 1 altg ¹
poland_5:key 30	 base 1 shift ! caps 1 ctrl nop altg nop
spain_5:key 30	 base 1 shift ! caps 1 ctrl 1 altg |
swiss_french_5:key 30	 base 1 shift + caps 1 ctrl 1 altg |
swiss_german_5:key 30	 base 1 shift + caps 1 ctrl 1 altg |
us_5:key 30	 base 1 shift ! caps 1 ctrl 1 altg nop

31 (1Fh)
bindings.h:  {31, 0x1F, 0x9F}, // 25. 2	@
reset:key 31	 base 2 shift @ caps 2 ctrl ^@ altg nop
canadian_french_5:key 31	 base 2 shift @ caps 2 ctrl ^@ altg nop
czech_5:key 31	 base @ shift 2 caps @ ctrl nop altg @
denmark_5:key 31	 base 2 shift '"' caps 2 ctrl ^@ altg @
france_5:key 31	 base é shift 2 caps é ctrl é altg ~
germany_5:key 31	 base 2 shift '"' caps 2 ctrl ^@ altg ²
hungary_5:key 31	 base 2 shift '"' caps 2 ctrl 2 altg nop
italy_5:key 31	 base 2 shift '"' caps 2 ctrl 2 altg nop
japan_5:key 31         base 2 shift '"' caps 2 ctrl 2 altg nop
netherlands_5:key 31	 base 2 shift '"' caps 2 ctrl 2 altg ²
norway_5:key 31	 base 2 shift '"' caps 2 ctrl ^@ altg @
poland_5:key 31	 base 2 shift '"' caps 2 ctrl 2 altg @
portugal_5:key 31	 base 2 shift '"' caps 2 ctrl ^@ altg @
russia_5:key 31	 base 2 shift @ caps 2 ctrl 2 altg nop
spain_5:key 31	 base 2 shift '"' caps 2 ctrl ^@ altg @
sweden_5:key 31	 base 2 shift '"' caps 2 ctrl ^@ altg @
swiss_french_5:key 31	 base 2 shift '"' caps 2 ctrl ^@ altg @
swiss_german_5:key 31	 base 2 shift '"' caps 2 ctrl ^@ altg @
uk_5:key 31	 base 2 shift '"' caps 2 ctrl 2 altg nop
us_5:key 31	 base 2 shift @ caps 2 ctrl ^@ altg nop

32 (20h)
bindings.h:  {32, 0x20, 0xA0}, // 26. 3	#
reset:key 32	 base 3 shift # caps 3 ctrl 3 altg nop
canadian_french_5:key 32	 base 3 shift # caps 3 ctrl 3 altg £
czech_5:key 32	 base # shift 3 caps # ctrl nop altg #
denmark_5:key 32	 base 3 shift # caps 3 ctrl 3 altg £
france_5:key 32	 base '"' shift 3 caps '"' ctrl '"' altg #
germany_5:key 32	 base 3 shift § caps 3 ctrl 3 altg ³
hungary_5:key 32	 base 3 shift + caps 3 ctrl 3 altg #
italy_5:key 32	 base 3 shift £ caps 3 ctrl 3 altg nop
netherlands_5:key 32	 base 3 shift # caps 3 ctrl 3 altg ³
norway_5:key 32	 base 3 shift # caps 3 ctrl 3 altg £
poland_5:key 32	 base 3 shift : caps 3 ctrl 3 altg #
portugal_5:key 32	 base 3 shift # caps 3 ctrl 3 altg £
russia_5:key 32	 base 3 shift # caps 3 ctrl 3 altg nop
spain_5:key 32	 base 3 shift · caps 3 ctrl 3 altg #
sweden_5:key 32	 base 3 shift # caps 3 ctrl 3 altg £
swiss_french_5:key 32	 base 3 shift * caps 3 ctrl 3 altg #
swiss_german_5:key 32	 base 3 shift * caps 3 ctrl 3 altg #
uk_5:key 32	 base 3 shift £ caps 3 ctrl 3 altg nop
us_5:key 32	 base 3 shift # caps 3 ctrl 3 altg nop

33 (21h)
bindings.h:  {33, 0x21, 0xA1}, // 27. 4	$
reset:key 33	 base 4 shift $ caps 4 ctrl 4 altg nop
canadian_french_5:key 33	 base 4 shift $ caps 4 ctrl 4 altg ¢
czech_5:key 33	 base $ shift 4 caps $ ctrl nop altg $
denmark_5:key 33	 base 4 shift ¤ caps 4 ctrl 4 altg $
france_5:key 33	 base '\'' shift 4 caps '\'' ctrl '\'' altg {
germany_5:key 33   base 4 shift $ caps 4 ctrl 4 altg nop
hungary_5:key 33   base 4 shift ! caps 4 ctrl 4 altg $
netherlands_5:key 33	 base 4 shift $ caps 4 ctrl 4 altg ¼
norway_5:key 33	 base 4 shift ¤ caps 4 ctrl 4 altg $
poland_5:key 33	 base 4 shift ? caps 4 ctrl 4 altg $
portugal_5:key 33	 base 4 shift $ caps 4 ctrl 4 altg §
spain_5:key 33   base 4 shift $ caps 4 ctrl ^^ altg ^
sweden_5:key 33	 base 4 shift ¤ caps 4 ctrl 4 altg $
swiss_french_5:key 33	 base 4 shift ç caps 4 ctrl ^^ altg ^
swiss_german_5:key 33	 base 4 shift ç caps 4 ctrl ^^ altg ^
us_5:key 33	 base 4 shift $ caps 4 ctrl 4 altg nop

34 (22h)
bindings.h:  {34, 0x22, 0xA2}, // 28. 5	%
reset:key 34	 base 5 shift % caps 5 ctrl 5 altg nop
canadian_french_5:key 34   base 5 shift % caps 5 ctrl 5 altg ¤
czech_5:key 34	 base % shift 5 caps % ctrl nop altg %
denmark_5:key 34   base 5 shift % caps 5 ctrl 5 altg ~
france_5:key 34	 base ( shift 5 caps ( ctrl ^[ altg [
germany_5:key 34   base 5 shift % caps 5 ctrl 5 altg nop
hungary_5:key 34   base 5 shift % caps 5 ctrl 5 altg nop
netherlands_5:key 34	 base 5 shift % caps 5 ctrl 5 altg ½
norway_5:key 34   base 5 shift % caps 5 ctrl 5 altg ~
poland_5:key 34	 base 5 shift % caps 5 ctrl nop altg nop
portugal_5:key 34   base 5 shift % caps 5 ctrl 5 altg ~
spain_5:key 34   base 5 shift % caps 5 ctrl 5 altg ~
swiss_french_5:key 34   base 5 shift % caps 5 ctrl 5 altg ~
swiss_german_5:key 34   base 5 shift % caps 5 ctrl 5 altg ~
us_5:key 34	 base 5 shift % caps 5 ctrl 5 altg nop

35 (23h)
bindings.h:  {35, 0x23, 0xA3}, // 29. 6	^
reset:key 35	 base 6 shift ^ caps 6 ctrl ^^ altg nop
canadian_french_5:key 35	 base 6 shift ? caps 6 ctrl 6 altg nop
czech_5:key 35	 base ^ shift 6 caps ^ ctrl nop altg ^
denmark_5:key 35	 base 6 shift & caps 6 ctrl ^^ altg ^
france_5:key 35	 base - shift 6 caps - ctrl ^_ altg |
germany_5:key 35	 base 6 shift & caps 6 ctrl 6 altg nop
hungary_5:key 35   base 6 shift / caps 6 ctrl 6 altg ^
italy_5:key 35	 base 6 shift & caps 6 ctrl 6 altg nop
japan_5:key 35         base 6 shift & caps 6 ctrl 6 altg nop
netherlands_5:key 35	 base 6 shift & caps 6 ctrl 6 altg ¾
norway_5:key 35	 base 6 shift & caps 6 ctrl ^^ altg ^
poland_5:key 35	 base 6 shift + caps 6 ctrl nop altg ^
portugal_5:key 35	 base 6 shift & caps 6 ctrl ^^ altg ^
spain_5:key 35	 base 6 shift & caps 6 ctrl 6 altg ¬
sweden_5:key 35	 base 6 shift & caps 6 ctrl 6 altg nop
swiss_french_5:key 35	 base 6 shift & caps 6 ctrl 6 altg nop
swiss_german_5:key 35	 base 6 shift & caps 6 ctrl 6 altg nop
us_5:key 35	 base 6 shift ^ caps 6 ctrl ^^ altg nop

36 (24h)
bindings.h:  {36, 0x24, 0xA4}, // 30. 7	&
reset:key 36	 base 7 shift & caps 7 ctrl 7 altg nop
canadian_french_5:key 36	 base 7 shift & caps 7 ctrl 7 altg nop
czech_5:key 36	 base & shift 7 caps & ctrl nop altg &
denmark_5:key 36	 base 7 shift / caps 7 ctrl 7 altg {
france_5:key 36	 base è shift 7 caps è ctrl è altg `
germany_5:key 36	 base 7 shift / caps 7 ctrl 7 altg {
hungary_5:key 36   base 7 shift = caps 7 ctrl 7 altg {
italy_5:key 36	 base 7 shift / caps 7 ctrl 7 altg nop
japan_5:key 36         base 7 shift '\'' caps 7 ctrl 7 altg nop
netherlands_5:key 36	 base 7 shift _ caps 7 ctrl ^_ altg £
norway_5:key 36	 base 7 shift / caps 7 ctrl 7 altg {
poland_5:key 36	 base 7 shift _ caps 7 ctrl 7 altg &
portugal_5:key 36	 base 7 shift / caps 7 ctrl 7 altg {
spain_5:key 36	 base 7 shift / caps 7 ctrl 7 altg nop
sweden_5:key 36	 base 7 shift / caps 7 ctrl 7 altg {
swiss_french_5:key 36	 base 7 shift / caps 7 ctrl 7 altg nop
swiss_german_5:key 36	 base 7 shift / caps 7 ctrl 7 altg nop
us_5:key 36	 base 7 shift & caps 7 ctrl 7 altg nop

37 (25h)
bindings.h:  {37, 0x25, 0xA5}, // 31. 8	*
reset:key 37	 base 8 shift * caps 8 ctrl 8 altg nop
canadian_french_5:key 37	 base 8 shift * caps 8 ctrl 8 altg nop
czech_5:key 37	 base * shift 8 caps * ctrl nop altg *
denmark_5:key 37	 base 8 shift ( caps 8 ctrl ^[ altg [
france_5:key 37	 base _ shift 8 caps _ ctrl ^\ altg \
germany_5:key 37	 base 8 shift ( caps 8 ctrl ^[ altg [
hungary_5:key 37   base 8 shift ( caps 8 ctrl 8 altg [
italy_5:key 37	 base 8 shift ( caps 8 ctrl 8 altg {
japan_5:key 37         base 8 shift ( caps 8 ctrl 8 altg nop
netherlands_5:key 37	 base 8 shift ( caps 8 ctrl 8 altg {
norway_5:key 37	 base 8 shift ( caps 8 ctrl ^[ altg [
poland_5:key 37	 base 8 shift ( caps 8 ctrl 8 altg *
portugal_5:key 37	 base 8 shift ( caps 8 ctrl ^[ altg [
spain_5:key 37	 base 8 shift ( caps 8 ctrl 8 altg nop
sweden_5:key 37	 base 8 shift ( caps 8 ctrl ^[ altg [
swiss_french_5:key 37	 base 8 shift ( caps 8 ctrl 8 altg nop
swiss_german_5:key 37	 base 8 shift ( caps 8 ctrl 8 altg nop
us_5:key 37	 base 8 shift * caps 8 ctrl 8 altg nop

38 (26h)
bindings.h:  {38, 0x26, 0xA6}, // 32. 9	(
reset:key 38	 base 9 shift ( caps 9 ctrl 9 altg nop
canadian_french_5:key 38	 base 9 shift ( caps 9 ctrl 9 altg [
czech_5:key 38	 base { shift 9 caps { ctrl nop altg {
denmark_5:key 38	 base 9 shift ) caps 9 ctrl ^] altg ]
france_5:key 38	 base ç shift 9 caps ç ctrl ^^ altg ^
germany_5:key 38	 base 9 shift ) caps 9 ctrl ^] altg ]
hungary_5:key 38   base 9 shift ) caps 9 ctrl 9 altg ]
italy_5:key 38	 base 9 shift ) caps 9 ctrl 9 altg }
japan_5:key 38         base 9 shift ) caps 9 ctrl 9 altg nop
netherlands_5:key 38	 base 9 shift ) caps 9 ctrl ^] altg }
norway_5:key 38	 base 9 shift ) caps 9 ctrl ^] altg ]
poland_5:key 38	 base 9 shift ) caps 9 ctrl 9 altg nop
portugal_5:key 38	 base 9 shift ) caps 9 ctrl ^] altg ]
spain_5:key 38	 base 9 shift ) caps 9 ctrl 9 altg nop
sweden_5:key 38	 base 9 shift ) caps 9 ctrl ^] altg ]
swiss_french_5:key 38	 base 9 shift ) caps 9 ctrl 9 altg nop
swiss_german_5:key 38	 base 9 shift ) caps 9 ctrl 9 altg nop
us_5:key 38	 base 9 shift ( caps 9 ctrl 9 altg nop

39 (27h)
bindings.h:  {39, 0x27, 0xA7}, // 33. 0	)
reset:key 39	 base 0 shift ) caps 0 ctrl 0 altg nop
canadian_french_5:key 39	 base 0 shift ) caps 0 ctrl 0 altg ]
czech_5:key 39	 base } shift 0 caps } ctrl nop altg }
denmark_5:key 39	 base 0 shift = caps 0 ctrl 0 altg }
france_5:key 39	 base à shift 0 caps à ctrl ^@ altg @
germany_5:key 39	 base 0 shift = caps 0 ctrl 0 altg }
hungary_5:key 39   base } shift } caps } ctrl nop altg }
italy_5:key 39	 base 0 shift = caps 0 ctrl 0 altg nop
japan_5:key 39         base 0 shift nop caps 0 ctrl 0 altg nop
netherlands_5:key 39	 base 0 shift '\'' caps 0 ctrl 0 altg '`'
norway_5:key 39	 base 0 shift = caps 0 ctrl 0 altg }
poland_5:key 39	 base 0 shift = caps 0 ctrl 0 altg nop
portugal_5:key 39	 base 0 shift = caps 0 ctrl 0 altg }
spain_5:key 39	 base 0 shift = caps 0 ctrl 0 altg nop
sweden_5:key 39	 base 0 shift = caps 0 ctrl 0 altg }
swiss_french_5:key 39	 base 0 shift = caps 0 ctrl 0 altg '`'
swiss_german_5:key 39	 base 0 shift = caps 0 ctrl 0 altg '`'
us_5:key 39	 base 0 shift ) caps 0 ctrl 0 altg nop

40 (28h)
bindings.h:  {45, 0x28, 0xA8}, // 34. -	_
reset:key 40	 base - shift _ caps - ctrl ^_ altg nop
canadian_french_5:key 40	 base - shift _ caps - ctrl - altg nop
czech_5:key 40	 base = shift % caps = ctrl nop altg nop
denmark_5:key 40	 base + shift ? caps + ctrl ^_ altg nop
france_5:key 40	 base ) shift ° caps ) ctrl ^] altg ]
germany_5:key 40	 base ß shift ? caps ß ctrl ^\ altg '\\' 
hungary_5:key 40   base \ shift \ caps \ ctrl nop altg \
italy_5:key 40	 base '\'' shift ? caps '\'' ctrl '\'' altg '`'
japan_5:key 40         base - shift = caps - ctrl - altg nop
netherlands_5:key 40	 base / shift ? caps / ctrl ^\ altg '\\'
norway_5:key 40	 base + shift ? caps + ctrl + altg nop
poland_5:key 40	 base nop shift nop caps nop ctrl nop altg nop
portugal_5:key 40	 base '\'' shift ? caps '\'' ctrl '\'' altg '`'
spain_5:key 40	 base '\'' shift ? caps '\'' ctrl '\'' altg '`'
sweden_5:key 40	 base + shift ? caps + ctrl ^\ altg '\\'
swiss_french_5:key 40	 base '\'' shift ? caps '\'' ctrl '\'' altg fa_acute
swiss_german_5:key 40	 base '\'' shift ? caps '\'' ctrl '\'' altg fa_acute
us_5:key 40	 base - shift _ caps - ctrl ^_ altg nop

41 (29h)
bindings.h:  {46, 0x29, 0xA9}, // 35. =	+
reset:key 41	 base = shift + caps = ctrl = altg nop
canadian_french_5:key 41	 base = shift + caps = ctrl = altg ¬
czech_5:key 41	 base nop shift nop caps nop ctrl nop altg nop
denmark_5:key 41	 base fa_acute shift fa_grave caps fa_acute ctrl fa_acute altg |
france_5:key 41	 base = shift + caps = ctrl = altg }
germany_5:key 41	 base fa_acute shift fa_grave caps fa_acute ctrl fa_acute altg nop
hungary_5:key 41   base ~ shift ~ caps ~ ctrl nop altg ~
italy_5:key 41	 base ì shift ^ caps Ì ctrl ^^ altg nop
japan_5:key 41         base ^ shift ~ caps ^ ctrl ^^ altg nop
netherlands_5:key 41	 base ° shift fa_tilde caps ° ctrl ° altg fa_cedilla
norway_5:key 41	 base '\\' shift fa_grave caps '\\' ctrl ^\ altg fa_acute
poland_5:key 41	 base nop shift nop caps nop ctrl nop altg nop
portugal_5:key 41	 base « shift » caps « ctrl « altg nop
spain_5:key 41   base ¡ shift ¿ caps ¡ ctrl ¡ altg nop
sweden_5:key 41	 base fa_acute shift fa_grave caps fa_acute ctrl fa_acute altg nop
swiss_french_5:key 41	 base fa_cflex shift fa_grave caps fa_cflex ctrl ^^ altg fa_tilde
swiss_german_5:key 41	 base fa_cflex shift fa_grave caps fa_cflex ctrl ^^ altg fa_tilde
us_5:key 41	 base = shift + caps = ctrl = altg nop

42 (2Ah)
bindings.h:  {53, 0x2A, 0xAA}, // 75. `	~
reset:key 42	 base ` shift ~ caps ` ctrl ^^ altg nop
canadian_french_5:key 42	 base / shift \ caps / ctrl / altg |
czech_5:key 42	 base ` shift ~ caps ` ctrl nop altg nop
denmark_5:key 42	 base ½ shift § caps ½ ctrl ½ altg nop
france_5:key 42	 base ² shift nop caps ² ctrl ² altg nop
germany_5:key 42   base ^ shift ° caps ^ ctrl ^^ altg nop
hungary_5:key 42   base 0 shift nop caps 0 ctrl 0 altg nop
italy_5:key 42   base '\\' shift | caps '\\' ctrl ^\ altg nop
japan_5:key 42         base ¥ shift | caps ¥ ctrl ¥ altg nop
netherlands_5:key 42	 base @ shift § caps @ ctrl ^@ altg '¬'
norway_5:key 42	 base | shift § caps | ctrl | altg nop
poland_5:key 42	 base ` shift ~ caps ` ctrl nop altg nop
portugal_5:key 42	 base '\\' shift | caps '\\' ctrl ^\ altg nop
russia_5:key 42	 base ` shift ~ caps ` ctrl ` altg nop
spain_5:key 42	 base º shift ª caps º ctrl ^\ altg '\\'
sweden_5:key 42	 base § shift ½ caps § ctrl § altg nop
swiss_french_5:key 42	 base § shift ° caps § ctrl § altg nop
swiss_german_5:key 42	 base § shift ° caps § ctrl § altg nop
uk_5:key 42	 base ` shift ¬ caps ` ctrl ` altg ¦
us_5:key 42	 base ` shift ~ caps ` ctrl ^^ altg nop

43 (2Bh)
bindings.h:  {42, 0x2B, 0xAB}, // 36. Backspace
reset:key 43	 all '\b'
hungary_5:key 43   all '\b'
poland_5:key 43	 base '\b'

44 (2Ch)
reset:key 44	 all hole
canadian_french_5:key 44   all bf(8)
czech_5:key 44   all bf(8)
denmark_5:key 44   all bf(8)
france_5:key 44   all bf(8)
germany_5:key 44   all bf(8)
hungary_5:key 44   all bf(8)
italy_5:key 44   all bf(8)
japan_5:key 44   all bf(8)
korea_5:key 44   all bf(8)
netherlands_5:key 44   all bf(8)
norway_5:key 44   all bf(8)
poland_5:key 44   all bf(8)
portugal_5:key 44   all bf(8)
russia_5:key 44   all bf(8)
spain_5:key 44   all bf(8)
sweden_5:key 44   all bf(8)
swiss_french_5:key 44   all bf(8)
swiss_german_5:key 44   all bf(8)
traditional_chinese_5:key 44   all bf(8)
uk_5:key 44   all bf(8)
us_5:key 44   all bf(8)

45 (2Dh)
bindings.h:  {103, 0x2D, 0xAD}, // Keypad Equal Sign → 37. =
bindings.h:  {1u << 4, 46, 0x2D, 0xAD}, // “Keypad = and +” → 37. =
reset:key 45	 all rf(4) numl padequal

46 (2Eh)
bindings.h:  {84, 0x2E, 0xAE}, // 38. /
reset:key 46	 all rf(5) numl padslash

47 (2Fh)
bindings.h:  {85, 0x2F, 0xAF}, // 39. *
reset:key 47	 all rf(6) numl padstar

48 (30h)
bindings.h:  {102, 0x30, 0xB0}, // keyboard Power → bf(13) Power
bindings.h:  {1u << 4, 19, 0x30, 0xB0}, // CtrlR+P → bf(13) Power
reset:key 48	 all bf(13)

49 (31h)
bindings.h:  {1u << 4, 41, 0x31, 0xB1}, // CtrlR+Esc → 41. Front
reset:key 49	 all lf(5)

50 (32h)
bindings.h:  {99, 0x32, 0xB2}, // 107. Del	.
reset:key 50	 all bf(10) numl paddot
denmark_5:key 50   all bf(10) numl padsep
germany_5:key 50   all bf(10) numl padsep
netherlands_5:key 50   all bf(10) numl padsep
norway_5:key 50   all bf(10) numl padsep
sweden_5:key 50   all bf(10) numl padsep

51 (33h)
bindings.h:  {124, 0x33, 0xB3}, // Keyboard Copy → 42. Copy
bindings.h:  {1u << 4, 6, 0x33, 0xB3}, // CtrlR+C → 42. Copy
reset:key 51	 all lf(6)

52 (34h)
reset:key 52	 all hole
canadian_french_5:key 52   all rf(7)
czech_5:key 52   all rf(7)
denmark_5:key 52   all rf(7)
france_5:key 52   all rf(7)
germany_5:key 52   all rf(7)
hungary_5:key 52   all rf(7)
italy_5:key 52   all rf(7)
japan_5:key 52   all rf(7)
korea_5:key 52   all rf(7)
netherlands_5:key 52   all rf(7)
norway_5:key 52   all rf(7)
poland_5:key 52   all rf(7)
portugal_5:key 52   all rf(7)
russia_5:key 52   all rf(7)
spain_5:key 52   all rf(7)
sweden_5:key 52   all rf(7)
swiss_french_5:key 52   all rf(7)
swiss_german_5:key 52   all rf(7)
traditional_chinese_5:key 52   all rf(7)
uk_5:key 52   all rf(7)
us_5:key 52   all rf(7)

53 (35h)
bindings.h:  {43, 0x35, 0xB5}, // 43. Tab
reset:key 53	 all '\t'

54 (36h)
bindings.h:  {20, 0x36, 0xB6}, // 44. Q
reset:key 54	 base q shift Q caps Q ctrl ^Q altg nop
france_5:key 54   base a shift A caps A ctrl ^A altg nop
germany_5:key 54	 base q shift Q caps Q ctrl ^Q altg @
hungary_5:key 54   base q shift Q caps Q ctrl ^Q altg @
us_5:key 54	 base q shift Q caps Q ctrl ^Q altg nop

55 (37h)
bindings.h:  {26, 0x37, 0xB7}, // 45. W
reset:key 55	 base w shift W caps W ctrl ^W altg nop
france_5:key 55	 base z shift Z caps Z ctrl ^Z altg nop
us_5:key 55	 base w shift W caps W ctrl ^W altg nop

56 (38h)
bindings.h:  {8, 0x38, 0xB8}, // 46. E
reset:key 56	 base e shift E caps E ctrl ^E altg nop

57 (39h)
bindings.h:  {21, 0x39, 0xB9}, // 47. R
reset:key 57	 base r shift R caps R ctrl ^R altg nop

58 (3Ah)
bindings.h:  {23, 0x3A, 0xBA}, // 48. T
reset:key 58	 base t shift T caps T ctrl ^T altg nop

59 (3Bh)
bindings.h:  {28, 0x3B, 0xBB}, // 49. Y
reset:key 59	 base y shift Y caps Y ctrl ^Y altg nop
czech_5:key 59	 base z shift Z caps Z ctrl ^Z altg nop
germany_5:key 59	 base z shift Z caps Z ctrl ^Z altg nop
hungary_5:key 59   base z shift Z caps Z ctrl ^Z altg nop
poland_5:key 59	 base y shift Y caps Y ctrl nop altg nop
swiss_french_5:key 59	 base z shift Z caps Z ctrl ^Z altg nop
swiss_german_5:key 59	 base z shift Z caps Z ctrl ^Z altg nop
us_5:key 59	 base y shift Y caps Y ctrl ^Y altg nop

60 (3Ch)
bindings.h:  {24, 0x3C, 0xBC}, // 50. U
reset:key 60	 base u shift U caps U ctrl ^U altg nop

61 (3Dh)
bindings.h:  {12, 0x3D, 0xBD}, // 51. I
reset:key 61	 base i shift I caps I ctrl '\t' altg nop

62 (3Eh)
bindings.h:  {18, 0x3E, 0xBE}, // 52. O
reset:key 62	 base o shift O caps O ctrl ^O altg nop
us_5:key 62	 base o shift O caps O ctrl ^O altg nop

63 (3Fh)
bindings.h:  {19, 0x3F, 0xEF}, // 53. P
reset:key 63	 base p shift P caps P ctrl ^P altg nop
canadian_french_5:key 63	 base p shift P caps P ctrl  altg ¶
us_5:key 63	 base p shift P caps P ctrl ^P altg nop

64 (40h)
bindings.h:  {47, 0x40, 0xC0}, // 54. [	{
reset:key 64	 base [ shift { caps [ ctrl ^[ altg nop
canadian_french_5:key 64	 base fa_cflex shift fa_umlaut caps fa_cflex ctrl 
 altg fa_grave
czech_5:key 64	 base [ shift / caps [ ctrl nop altg [
denmark_5:key 64	 base å shift Å caps Å ctrl å altg nop
france_5:key 64	 base fa_cflex shift fa_umlaut caps fa_cflex ctrl fa_cflex altg nop
germany_5:key 64	 base ü shift Ü caps Ü ctrl ü altg nop
hungary_5:key 64   base nop shift nop caps nop ctrl nop altg nop
italy_5:key 64	 base è shift é caps È ctrl ^[ altg [
japan_5:key 64         base @ shift ` caps @ ctrl ^@ altg nop
netherlands_5:key 64	 base fa_umlaut shift fa_cflex caps fa_umlaut ctrl fa_umlaut altg nop
norway_5:key 64	 base å shift Å caps Å ctrl å altg nop
poland_5:key 64	 base [ shift { caps [ ctrl nop altg [
portugal_5:key 64	 base + shift * caps + ctrl + altg fa_umlaut
spain_5:key 64	 base fa_grave shift fa_cflex caps fa_grave ctrl ^[ altg [
sweden_5:key 64	 base å shift Å caps Å ctrl å altg nop
swiss_french_5:key 64	 base è shift ü caps È ctrl ^[ altg [
swiss_german_5:key 64	 base ü shift è caps Ü ctrl ^[ altg [
us_5:key 64	 base [ shift { caps [ ctrl ^[ altg nop

65 (41h)
bindings.h:  {48, 0x41, 0xC1}, // 55. ]	}
reset:key 65	 base ] shift } caps ] ctrl ^] altg nop
canadian_french_5:key 65	 base ç shift Ç caps Ç ctrl ç altg ~
czech_5:key 65	 base ) shift ( caps ) ctrl nop altg ]
denmark_5:key 65	 base fa_umlaut shift fa_cflex caps fa_umlaut ctrl fa_umlaut altg fa_tilde
france_5:key 65	 base $ shift £ caps $ ctrl $ altg ¤
germany_5:key 65	 base + shift * caps + ctrl + altg ~
hungary_5:key 65   base nop shift nop caps nop ctrl nop altg nop
italy_5:key 65	 base + shift * caps + ctrl ^] altg ]
japan_5:key 65         base [ shift { caps [ ctrl ^[ altg nop
netherlands_5:key 65	 base * shift | caps * ctrl * altg ~
norway_5:key 65	 base fa_umlaut shift fa_cflex caps fa_umlaut ctrl ^^ altg fa_tilde
poland_5:key 65	 base / shift } caps / ctrl nop altg ]
portugal_5:key 65	 base fa_acute shift fa_grave caps fa_acute ctrl fa_acute altg nop
spain_5:key 65	 base + shift * caps + ctrl ^] altg ]
sweden_5:key 65	 base fa_umlaut shift ^ caps fa_umlaut ctrl ^^ altg ~
swiss_french_5:key 65	 base fa_umlaut shift ! caps fa_umlaut ctrl ^] altg ]
swiss_german_5:key 65	 base fa_umlaut shift ! caps fa_umlaut ctrl ^] altg ]
us_5:key 65	 base ] shift } caps ] ctrl ^] altg nop

66 (42h)
bindings.h:  {76, 0x42, 0xC2}, // 14. Delete
reset:key 66	 all '\177'

67 (43h)
bindings.h:  {101, 0x43, 0xC3}, // context menu aka “Keyboard Application” → 101. Compose
reset:key 67	 all compose
korea_5:key 67	all bf(4)
us_5:key 67	 all compose

68 (44h)
bindings.h:  {95, 0x44, 0xC4}, // 57. Home	7
reset:key 68	 all rf(7) numl pad7

69 (45h)
bindings.h:  {96, 0x45, 0xC5}, // 58. (up cur)	8
reset:key 69	 all string+uparrow numl pad8

70 (46h)
bindings.h:  {97, 0x46, 0xC6}, // 59. PgUp	9
reset:key 70	 all rf(9) numl pad9

71 (47h)
bindings.h:  {86, 0x47, 0xC7}, // 40. -
reset:key 71	 all bf(15) numl padminus

72 (48h)
bindings.h:  {1u << 4, 18, 0x48, 0xC8}, // CtrlR+O → 61. Open
reset:key 72	 all lf(7)

73 (49h)
bindings.h:  {125, 0x49, 0xC9}, // Keyboard Paste → 62. Paste
bindings.h:  {1u << 4, 25, 0x49, 0xC9}, // CtrlR+V → 62. Paste
reset:key 73	 all lf(8)

74 (4Ah)
reset:key 74	 all hole
canadian_french_5:key 74   all rf(13)
czech_5:key 74   all rf(13)
denmark_5:key 74   all rf(13)
france_5:key 74   all rf(13)
germany_5:key 74   all rf(13)
hungary_5:key 74   all rf(13)
italy_5:key 74   all rf(13)
japan_5:key 74   all rf(13)
korea_5:key 74   all rf(13)
netherlands_5:key 74   all rf(13)
norway_5:key 74   all rf(13)
poland_5:key 74   all rf(13)
portugal_5:key 74   all rf(13)
russia_5:key 74   all rf(13)
spain_5:key 74   all rf(13)
sweden_5:key 74   all rf(13)
swiss_french_5:key 74   all rf(13)
swiss_german_5:key 74   all rf(13)
traditional_chinese_5:key 74   all rf(13)
uk_5:key 74   all rf(13)
us_5:key 74   all rf(13)

75 (4Bh)
reset:key 75	 all hole

76 (4Ch)
bindings.h:  {1u << 0, 0x4C, 0xCC}, // CtrlL → 63. Control
reset:key 76	 all shiftkeys+leftctrl up shiftkeys+leftctrl
us_5:key 76	 all shiftkeys+leftctrl up shiftkeys+leftctrl

77 (4Dh)
bindings.h:  {4, 0x4D, 0xCD}, // 64. A
reset:key 77	 base a shift A caps A ctrl ^A altg nop
france_5:key 77   base q shift Q caps Q ctrl ^Q altg nop
us_5:key 77	 base a shift A caps A ctrl ^A altg nop
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

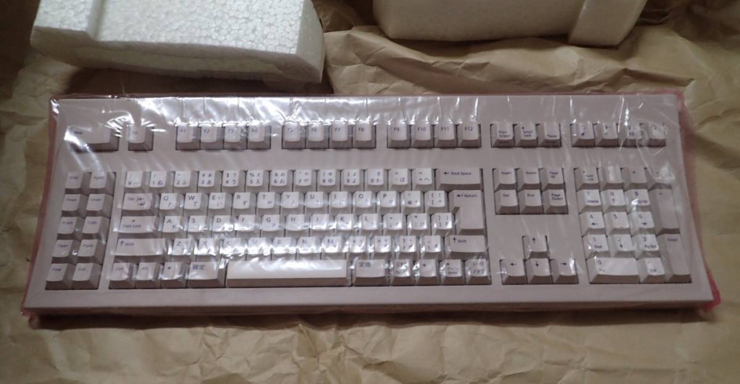
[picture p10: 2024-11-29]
doc/images/type5-jp.jpg

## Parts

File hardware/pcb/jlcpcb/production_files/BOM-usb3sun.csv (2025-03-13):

Comment | Designator | Footprint | LCSC
GZ2012D601TF | FB1 | L_0805_2012Metric | C1017
1K | R16,R17 | R_0402_1005Metric | C11702
100uF | C5 | CP_EIA-3528-21_Kemet-B | C16133
TYPE-C-31-M-12 | J4 | USB_C_Receptacle_HRO_TYPE-C-31-M-12 | C165948
330pF | C1,C2,C3,C4 | C_0603_1608Metric | C1664
1N5819WS | D4 | D_SOD-323 | C191023
22R | R10,R11,R8,R9 | R_0402_1005Metric | C25092
20K | R1,R18,R19,R2,R3,R4,R5,R6,R7 | R_0402_1005Metric | C25765
5K1 | R14,R15 | R_0402_1005Metric | C25905
MAX40200AUK | U3,U4 | SOT-23-5 | C2649430
TS-1187A-B-A-B | SW1,SW2 | SW_Push_1P1T_XKB_TS-1187A | C318884
Conn_01x06_Pin | J3 | PinHeader_1x06_P2.54mm_Vertical | C37208
6K2 | R12,R13 | R_0402_1005Metric | C4260
ESD5Z5V0 | D1 | D_SOD-523 | C502546
Pico | U1 | RPi_Pico_SMD | C5159530
CMOZ1L8 | D5,D6 | D_SOD-523 | C5240494
500mA | F1,F2 | Fuse_1206_3216Metric | C70076
1A5 | F3 | Fuse_1206_3216Metric | C70084
19-213/Y2C-CQ2R2L/3T(CY) | D2,D3 | LED_0603_1608Metric | C72038
USB-269-BRW | J1 | USB_A_CUI_UJ2-ADH-TH_Horizontal_Stacked | C720548
2N7002DW | Q1,Q3,Q7 | SOT-363_SC-70-6 | C83571
MMBT2222A | Q5,Q6 | SOT-23 | C8512
SRV05-4 | U5,U6,U7 | SOT-23-6-routable | C85364
MLT-7525 | BZ1 | PUIAudio_SMT_0825_S_4_R | C95299

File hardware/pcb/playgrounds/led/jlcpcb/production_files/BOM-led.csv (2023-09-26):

Comment | Designator | Footprint | LCSC
1K | R1 | R_0402_1005Metric | C11702
100R | R2 | R_0402_1005Metric | C25087
200R | RV3 | Potentiometer_Bourns_3314G_Vertical | C52238
CMOZ1L8 | D2 | D_SOD-523 | C5240494
2K | RV2 | Potentiometer_Bourns_3314G_Vertical | C711704
19-213/Y2C-CQ2R2L/3T(CY) | D1 | LED_0603_1608Metric | C72038
20K | RV1 | Potentiometer_Bourns_3314G_Vertical | C780217
MMDT2222A | Q1 | SOT-363_SC-70-6 | C96379

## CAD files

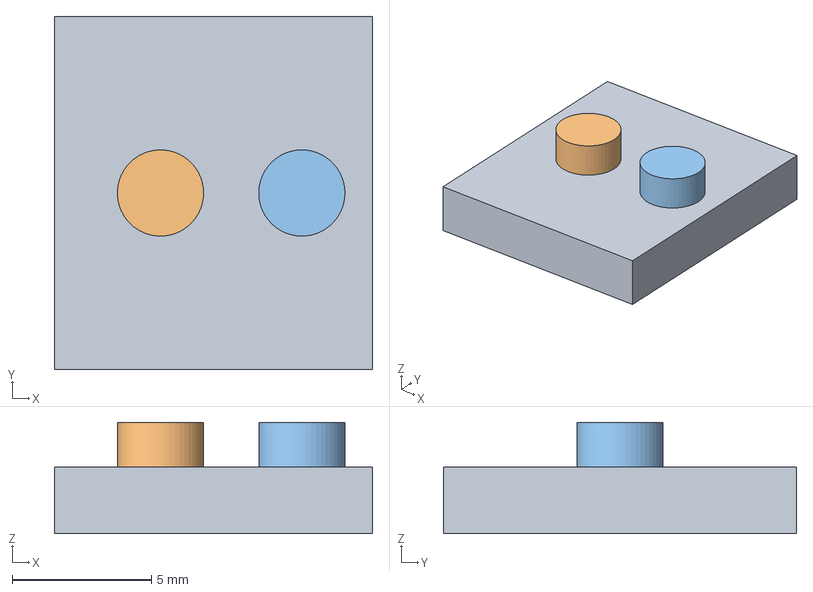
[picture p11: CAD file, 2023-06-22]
hardware/support/support.FCStd
11.4 x 12.7 x 4.00 mm

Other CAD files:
hardware/support/support.stl

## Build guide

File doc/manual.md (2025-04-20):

[README](../README.md) >

usb3sun user guide
==================

usb3sun is an adapter that allows you to use usb keyboards and mice with SPARCstations and other sun workstations.

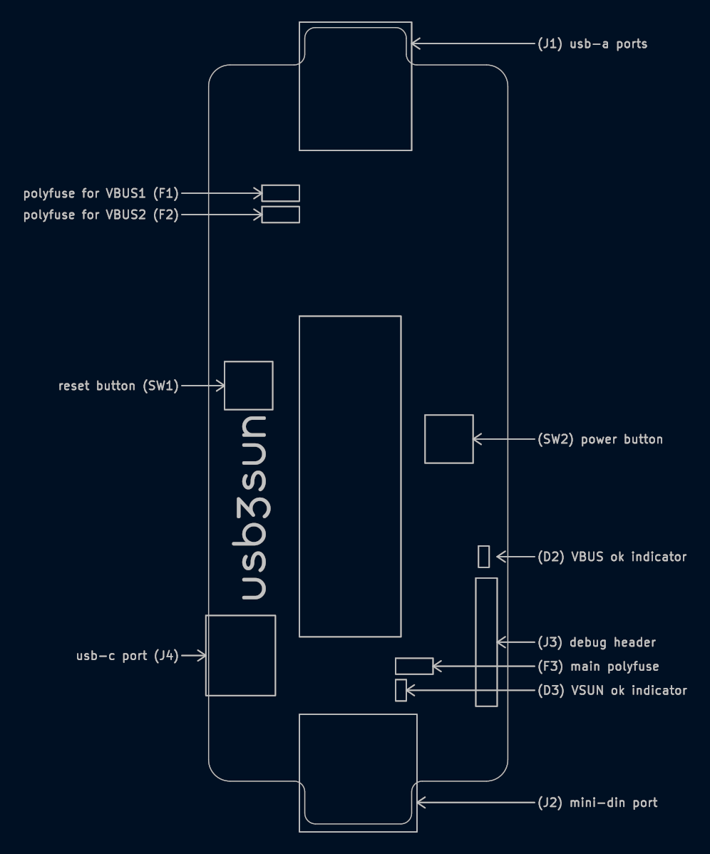
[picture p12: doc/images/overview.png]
board overview of rev A2+


<!-- export User.1 to svg, open in gimp at 300dpi, background #001023, expand 60x60 center -->

## toc

- [getting started](#getting-started)
- [the power key](#the-power-key)
- [the display](#the-display)
- [the settings menu](#the-settings-menu)
- [bindings](#bindings)
- [updating the firmware](#updating-the-firmware)
    - [usb method](#usb-method)
    - [picoprobe method](#picoprobe-method)
- [debugging and automation](#debugging-and-automation)
    - [debug logging over usb cdc](#debug-logging-over-usb-cdc)
    - [debug logging with the debug uart](#debug-logging-with-the-debug-uart)
    - [automation with the debug cli](#automation-with-the-debug-cli)
- [compatibility](#compatibility)
- [specifications](#specifications)
    - [electrical characteristics](#electrical-characteristics)
    - [design files](#design-files)
- [troubleshooting](#troubleshooting)
- [errata](#errata)

## getting started

to use the adapter, you will need a sun workstation, as well as a usb keyboard and/or mouse.

you will also need an 8-pin mini-din cable, male to male, **with each pin connected to the same pin on the other end**. we recommend the original sun cable (530-1442 or 530-1442-02) or the [lindy 31532](https://www.lindy.com.au/serial-cable-8-pin-mini-din-m-m-2m), but they are sometimes sold as a “mini-din serial cable”, LocalTalk cable, or AppleTalk cable.

|  |  |
|-|-|
| ⚠️<br>**watch out!** | do not use mini-din cables with any pins swapped, like the apple 590-0552-A. if you are unsure, check with a multimeter in continuity mode. |
| | be sure to hold the mini-din port on the adapter while connecting or disconnecting a cable. the port can be tight, so holding it will minimise strain on the board. |

connect the adapter to your sun workstation with the mini-din cable, and connect any keyboards and mice to the usb-a ports on the adapter. the usb-c port on the adapter (rev A2+) is for debugging and firmware updates only.

## the power key

some sun keyboards have a power key, which switches on the workstation by toggling pin 7 of the mini-din port, in addition to sending scancodes like other keys.

to switch on your workstation, press the onboard power button (rev A1+), or press **Right Ctrl+P** on your usb keyboard. note that the latter will only work if the adapter is powered externally via the usb-c port (rev A2+) or the VBUS pin of the debug header (J3).

to send the power key to software while the workstation is on, press **Right Ctrl+P** on your usb keyboard. the onboard power button (rev A1+) does not send any scancodes.

## the display

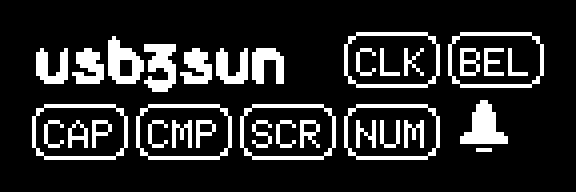
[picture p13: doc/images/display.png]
display


| off | on | meaning |
|-|-|-|
|  |  | **click mode** — as set by the workstation, ignoring the “force click” setting |
|  |  | **bell active** |
|  |  | **caps lock active** |
|  |  | **compose active** |
|  |  | **scroll lock active** |
|  |  | **num lock active** |
|  |  | **buzzer active** — making any sound, including click, bell, or plug or unplug notifications |

## the settings menu

usb3sun remembers its settings while powered off (firmware 1.2+).

to open the settings menu, press **Right Ctrl+Space**. use the **Up** and **Down** arrow keys to select a setting, then use **Left** and **Right** to change settings listed as “in place”, or **Return** or **Enter** to choose other actions.

to close the settings menu, press **Esc** (firmware 2.0+) or choose **Go back**.

if there are no unsaved changes, or if you have an older firmware that saves changes immediately (firmware &lt;2.0), that’s all you need to do! if there are unsaved changes (firmware 2.0+), you will be asked if you want to save your changes:

- press **Enter** to save your settings
- press **N** to close without saving
- press **Esc** to go back to the settings menu

some usb devices may start to malfunction after saving settings, because we need to pause the whole adapter (including the usb host) while we write to flash. if you have an affected device, pressing **Shift+Enter** instead of **Enter** will reboot usb3sun (the adapter, not your workstation) after saving your settings. please report any affected devices in the github issue ([#14](https://github.com/delan/usb3sun/issues/14)).

| setting | firmware | in place? | values |
|-|-|-|-|
| Go back | 1.0+ | no | closes the settings menu |
| Force click | 1.2+ | yes | **no** (default) = allow the workstation to control the click mode |
|  |  |  | **off** = never click when pressing keys |
|  |  |  | **on** = always click when pressing keys |
| Click duration | 1.0+ | yes | 0 ms, 5 ms (default), 10 ms, …, 100 ms |
| Mouse baud | 2.0+ | yes | 1200, 2400, 4800, 9600 (default) |
|  |  |  | lower baud rates may be required on **NeXTSTEP** and **Plan 9** |
| Hostid | 1.5+ | no | sets the hostid used when reprogramming your idprom |
| Reprogram idprom | 1.5+ | no | plays a macro that reprograms your idprom |
| Wipe idprom (AAh) | 1.5+ | no | plays a macro that makes your idprom contents invalid |

## bindings

for more details, see [/src/bindings.h](../src/bindings.h), but here are the important ones:

| USB | Sun |
|---|---|
| context menu | Compose |
| Left Alt | Alt |
| Right Alt | Graph/Alt |
| Left GUI* | left Meta (diamond) |
| Right GUI* | right Meta (diamond) |
| Left Ctrl | Control |
| Right Ctrl+Space  | (usb3sun settings menu) |
| Right Ctrl+. | Stop |
| Right Ctrl+Esc | Front |
| Right Ctrl+Return | Line Feed |
| Right Ctrl+C | Copy |
| Right Ctrl+F | Find |
| Right Ctrl+O | Open |
| Right Ctrl+P | Power |
| Right Ctrl+V | Paste |
| Right Ctrl+X | Cut |
| Right Ctrl+Y | Again |
| Right Ctrl+Z | Undo |
| Right Ctrl+F1 | Help |
| Right Ctrl+F4 | Props |
| Right Ctrl+= | keypad = |

\* aka Super, Mod4, Windows, etc

## updating the firmware

you can update or reflash the firmware over usb (rev A2+), or with a picoprobe.

### usb method

1. press and hold the BOOTSEL button underneath the adapter
2. connect the adapter’s usb-c port (J4) to your computer
3. release the BOOTSEL button
4. copy firmware.uf2 to the usb mass storage device — you can copy it as a file to the FAT file system, or write to the block device directly with dd(1)

### picoprobe method

you will need a [raspberry pi pico](https://www.altronics.com.au/p/z6421a-raspberry-pi-pico-rp2040-development-board-with-headers/), other than the one used by usb3sun, which we’ll call the debugger. you will also need a way to connect pins on the adapter’s debug header (J3) to pins on the debugger, such as [header pins](https://www.altronics.com.au/p/p5430-oupiin-40-way-header-pin/) and [jumper cables](https://www.altronics.com.au/p/p1023-socket-to-socket-30-way-prototyping-ribbon-strips/).

flash the debugger with [the picoprobe firmware](https://github.com/raspberrypi/picoprobe), then connect the adapter to the debugger as follows, being sure to connect GND first and disconnect GND last.

| rev A0 | rev A1+ | picoprobe |
|-|-|-|
| GND | GND | GND (pin 8) |
|  | UART_TX | GP5 (pin 7) |
|  | UART_RX | GP4 (pin 6) |
| SWDIO | SWDIO | GP3 (pin 5) |
| SWCLK | SWCLK | GP2 (pin 4) |
| VBUS | VBUS | VBUS (pin 40) |

to flash the adapter with firmware.elf, run the command below.

```
$ openocd -f interface/cmsis-dap.cfg -f target/rp2040.cfg -c 'adapter speed 1000' -c 'program firmware.elf verify reset exit'
```

## debugging and automation

usb3sun has a wide range of debugging options, which you can use to investigate bugs, find hardware defects, or diagnose usb compatibility issues. with new enough hardware and firmware, you can even automate input (firmware 2.0+)!

### debug logging over usb cdc

by default, usb3sun has built-in debug logging over usb cdc, via the usb-c port marked “debug only” (J4) (rev A2+). building the firmware with PICOPROBE_ENABLE (firmware &lt;2.0) or without DEBUG_OVER_CDC (firmware 2.0+) will disable this.

logging over usb cdc has some serious limitations:

- the **debug cli** (see below) is not currently supported over usb cdc — this may change in the future
- you can only get the logs for usb3sun this way, not the logs for tinyusb or the underlying arduino-pico framework — this will never change, because it would create a chicken-and-egg problem
- it can be very unreliable, because the output tx may stop working if idle for even a few seconds — the reasons for this are still unclear, but may be related to flow control or a usb suspend bug

to connect, plug your adapter into your computer via the usb-c port marked “debug only” (J4), then use picocom:

```sh
$ picocom -fn -b115200 --imap lfcrlf /dev/ttyACM0
```

### debug logging with the debug uart

the best debug logging method is to use the UART_TX and UART_RX pins in the debug header (J3) (rev A1+), which avoids all of the limitations of logging over usb cdc.

the debug uart is enabled by default in newer adapters (rev B0+), but older adapters have a hardware limitation that means you can only use the debug uart with a [custom firmware build](firmware.md#building-the-firmware-for-pico) that disables the sun keyboard interface. the exact procedure also depends on your firmware version:

- if you have **rev A0**, **rev A1**, **rev A2**, or **rev A3**, with **firmware &lt;2.0**, the debug uart is **disabled by default**, unless you build the firmware with PICOPROBE_ENABLE, and doing so disables the sun keyboard interface (even with SUNK_ENABLE)
- if you have **rev A0**, **rev A1**, **rev A2**, or **rev A3**, with **firmware 2.0+**, the debug uart is **disabled by default**, unless you build the firmware with DEBUG_OVER_UART (which is the default) but without SUNK_ENABLE (disabling the sun keyboard interface)
- if you have **rev B0** or **rev B1**, with **firmware 2.0+**, the debug uart is **enabled by default**, unless you build the firmware without DEBUG_OVER_UART

to connect, wire up your adapter to a picoprobe (see [§ *picoprobe method*](#picoprobe-method)) or 3V3-capable usb-to-serial adapter, then use picocom:

```sh
$ picocom -fn -b115200 --imap lfcrlf /dev/ttyACM0
```

### automation with the debug cli

when connected to [the debug uart](#debug-logging-with-the-debug-uart), you can type commands or press keys over that connection to send input over the sun keyboard and mouse interfaces, even without any usb devices! press **Enter** to get a prompt (`> `), then use the debug cli as follows:

- press **Alt+WASD** to **move up**, **down**, **left**, or **right** on the sun mouse
- press **Alt+QEZC** to **move diagonally** on the sun mouse
- press **Alt+123** to **toggle the left**, **middle**, or **right** buttons on the sun mouse
- press **Ctrl+H** to make the sun keyboard press **Backspace**
- press **Ctrl+J** to make the sun keyboard press **Return**
- type `stop a` to make the sun keyboard press **Stop+A**
- type `enter` to make the sun keyboard press **Enter**
- type `go` to make the sun keyboard type **“go” followed by Return**
- type `help` to get help, much like the help above

## compatibility

usb3sun is compatible with any machine that would normally use a

- Sun Compact 1
- Sun Type 4
- Sun Type 5
- Sun Type 5c
- Sun Type 6 (non-usb)

usb3sun has been tested successfully with

- SPARCstation IPC (sun4c)
- SPARCstation IPX (sun4c)
- SPARCstation 2 (sun4c)
- SPARCstation 5 (sun4m)
- SPARCstation 20 (sun4m)
- Ultra 5 (sun4u)
- 1209:A1E5 Atreus (Technomancy version) **keyboard** with QMK
- 04A5:8001 BenQ Zowie EC2 **mouse**
- 046D:C063 Dell M-UAV-DEL8 **mouse**
- FEED:1307 gBoards Gergo **keyboard** with QMK
- 03F0:6941 HP 150 Wired **Keyboard** (HSA-A013K, 664R5AA)
- 0461:4E24 HP KB71211 **keyboard** — no scroll lock or right meta
- 0461:4E23 HP MOGIUO **mouse**
- 04D9:1503 Inland 208397 **keyboard**
- 30FA:2031 Keji KECK801UKB **keyboard**
- 17EF:608D Lenovo EMS-537A **mouse**
- 17EF:6019 Lenovo MSU1175 **mouse**
- 045E:0040 Microsoft Wheel **Mouse** Optical 1.1A — enumeration is unreliable
- 045E:0752 Microsoft Wired **Keyboard** 400
- 045E:0750 Microsoft Wired **Keyboard** 600
- 045E:0773 Microsoft Explorer Touch **Mouse** (model 1490)
- FEED:6061 Preonic OLKB-60 **keyboard** with QMK

usb3sun is not yet compatible with

- [#4](https://github.com/delan/usb3sun/issues/4) — 05AC:024F Apple Magic **Keyboard** with Numeric Keypad (model A1243)
- [#5](https://github.com/delan/usb3sun/issues/5) — 1209:2303 Atreus (Keyboardio version) **keyboard** with Kaleidoscope
- [#6](https://github.com/delan/usb3sun/issues/6) — 3367:1903 Endgame Gear XM1r **mouse** — buttons only (16-bit dx/dy, no boot protocol)
- [#7](https://github.com/delan/usb3sun/issues/7) — 045E:0039 Microsoft Intelli**Mouse** Optical 1.1A — broken (“Control FAILED”)

## specifications

|  | rev A0 | rev A1 | rev A2 | rev A3+ |
|-|-|-|-|-|
| width | 36 mm | 36 mm | 36 mm | 36 mm |
| length | 95 mm | **98 mm** | 98 mm | 98 mm |
| height | 23 mm | 23 mm | 23 mm | 23 mm |
| ports | 1x sun mini-din | 1x sun mini-din | 1x sun mini-din | 1x sun mini-din |
|  | 2x usb-a | 2x usb-a | 2x usb-a | 2x usb-a |
|  |  |  | **1x usb-c (debug only)** | 1x usb-c (debug only) |
| buttons |  | **power (for workstation)** | power (for workstation) | power (for workstation) |
|  |  | **reset (for adapter)** | reset (for adapter) | reset (for adapter) |
| led indicators |  | **VBUS ok** | VBUS ok | VBUS ok |
|  |  | **VSUN ok** | VSUN ok | VSUN ok |

### electrical characteristics

|  | rev A0+ |
|-|-|
| operating temperature | -40°C to 85°C |
| storage temperature | -40°C to 85°C |
| VBUS | -0V3 to 6V0 |
| VSUN | -0V3 to 6V0 |
| I<sub>VBUS1</sub> | up to 500mA |
| I<sub>VBUS2</sub> | up to 500mA |

### design files

|  | rev A0 | rev A1 | rev A2 | rev A3 | rev B0 | rev B1 |
|-|-|-|-|-|-|-|
| schematic | [rendered](https://kicanvas.org/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) ([source](https://github.com/delan/usb3sun/blob/A0/hardware/pcb/usb3sun.kicad_sch)) | [rendered](https://kicanvas.org/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) ([source](https://github.com/delan/usb3sun/blob/A1/hardware/pcb/usb3sun.kicad_sch)) | [rendered](https://kicanvas.org/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) ([source](https://github.com/delan/usb3sun/blob/A2/hardware/pcb/usb3sun.kicad_sch)) | [rendered](https://kicanvas.org/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) ([source](https://github.com/delan/usb3sun/blob/A3/hardware/pcb/usb3sun.kicad_sch)) | [rendered](https://kicanvas.org/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) ([source](https://github.com/delan/usb3sun/blob/B0/hardware/pcb/usb3sun.kicad_sch)) | [rendered](https://kicanvas.org/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) ([source](https://github.com/delan/usb3sun/blob/B1/hardware/pcb/usb3sun.kicad_sch)) |
| pcb layout | [rendered](https://kicanvas.org/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) ([source](https://github.com/delan/usb3sun/blob/A0/hardware/pcb/usb3sun.kicad_pcb)) | [rendered](https://kicanvas.org/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) ([source](https://github.com/delan/usb3sun/blob/A1/hardware/pcb/usb3sun.kicad_pcb)) | [rendered](https://kicanvas.org/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) ([source](https://github.com/delan/usb3sun/blob/A2/hardware/pcb/usb3sun.kicad_pcb)) | [rendered](https://kicanvas.org/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) ([source](https://github.com/delan/usb3sun/blob/A3/hardware/pcb/usb3sun.kicad_pcb)) | [rendered](https://kicanvas.org/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) ([source](https://github.com/delan/usb3sun/blob/B0/hardware/pcb/usb3sun.kicad_pcb)) | [rendered](https://kicanvas.org/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) ([source](https://github.com/delan/usb3sun/blob/B1/hardware/pcb/usb3sun.kicad_pcb)) |
| display module support |  | [source](https://github.com/delan/usb3sun/blob/74b367a12600d712eb7a05a9fc67c958bae3fe62/hardware/support/support.FCStd) | [source](https://github.com/delan/usb3sun/blob/A2/hardware/support/support.FCStd) | [source](https://github.com/delan/usb3sun/blob/A3/hardware/support/support.FCStd) | [source](https://github.com/delan/usb3sun/blob/B0/hardware/support/support.FCStd) | [source](https://github.com/delan/usb3sun/blob/B1/hardware/support/support.FCStd) |

## troubleshooting

observed on solaris 2.5.1 — if you boot solaris immediately after reprogramming a previously invalid idprom, you may see the loading spinner hang after the following errors. if affected, press **Stop+A**, then rerun your `boot` command to reboot your workstation.

```
Invalid format code in IDprom.
WARNING: TOD clock not initialized -- CHECK AND RESET THE DATE!
|
```

## errata

[#2](https://github.com/delan/usb3sun/issues/2) (fixed in rev B0+) — in **rev A0**, **rev A1**, **rev A2**, and **rev A3**, resetting the adapter will make the workstation drop you into an ok prompt, because the initial state of the adapter after reset is a serial “break” on the sun keyboard tx line. this may cause the software on your workstation to behave unpredictably after typing “go” to continue. for example, solaris 2.5.1 often panics here if booted over nfs.

[#11](https://github.com/delan/usb3sun/issues/11) (fixed in rev B0+) — in **rev A0**, **rev A1**, **rev A2**, and **rev A3**, resetting the adapter may cause the adapter to hang until power cycled, with the pico’s green indicator led stuck on, because the display module can’t be reset and may start to malfunction. this is relatively rare, but also fairly easy to reproduce if you mash the reset button several times in quick succession.

[#14](https://github.com/delan/usb3sun/issues/14) (workaround available in firmware 2.0+) — in **all firmware versions**, some usb devices may start to malfunction after saving settings, because we need to pause the whole adapter (including the usb host) while we write to flash. for example, with the Microsoft Wheel Mouse Optical 1.1A (045E:0040), saving settings may make the red led go dim and make the mouse start spewing updates until disconnected. to work around this issue (firmware 2.0+), hold **Shift** while pressing **Enter** to reboot the adapter after saving settings.

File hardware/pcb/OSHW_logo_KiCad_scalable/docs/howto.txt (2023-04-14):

How to make your own:
---------------------

Watch / read this first:

* http://www.kicad-pcb.org/display/KICAD/Videos+by+zupnikal

The last two videos should be helpful for how to create a custom .emp file from images.

* http://www.re-innovation.co.uk/web12/index.php/en/blog-75/230-adding-logo-to-kicad

If you use linux (which you should), you don't have to use the online-scaler. Just use the scripts!

---

* Create a folder to hold your new footprint library.
* Copy the scripts 'make_lib.sh' and 'scale.pl' into that folder.
* Make sure these files are executable (chmod u+x ...).
* Copy your custom .emp file into that foler.

* Run the 'make_lib.sh' script as follows:

./make_lib.sh input-file.emp lib-name.mod START END

START and END are placeholders for positive integer numbers (1,2,3...) that determine
the range of created footprint sizes. The units are metric (mm).

The 'lib-name.mod' file will show up in the 'lib' sub-folder. Add it to your pcbnew
library settings as usual.

Footprints that are created for back-layers are automagically mirrored horizontally.
To place them onto a back-layer, hover the mouse-pointer over them and press 'f' for 'flip'.

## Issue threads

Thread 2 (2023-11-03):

workstation drops back to ok prompt when resetting adapter

delan, 2023-11-03:

delan, 2024-05-25:
fixed in [pcb rev B0](https://github.com/delan/usb3sun/releases/tag/B0)

Closed 2024-05-25.

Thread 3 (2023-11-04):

17EF:6019 Lenovo MSU1175 mouse — only works after reconnecting

hanshuebner, 2023-11-04:
Hey,

I have two Lenovo mice of the same type (MSU1175) which are not working when I start my SPARCstation IPX.  If I unplug and re-plug them, they work.  I hear one confirmation tone when the adapter initially starts - Would I head two separate tones for keyboard and mouse if they'd both be recognized upon power-up?

I have suspected that the problem might be a startup-up timing issue, but adding a second of delay in `setup()` or `loop()` did not solve the issue.

On one occasion, I found that only the mouse was enumerated, but not the keyboard: I re-plugged the usb3sun with both USB devices connected and heard one device confirmation tone.  The keyboard did not work, however.  When I unplugged and re-plugged it, it worked.

Does enumeration of both the mouse and keyboard at startup usually work, or is this a known issue?

Thanks,
Hans

delan, 2023-11-11:
The confirmation tones can overlap, depending on USB enumeration timing, so you may only hear a longer-than-usual low tone followed by a high tone when multiple devices are connected.

The underlying USB stack has often had bugs that cause problems when enumerating some devices. For example, the Microsoft Wired Keyboard 600 (045E:0750) and 400 (045E:0752) [needed a delay](https://github.com/delan/usb3sun/blob/5086173a7fd0bd8d7045c1833cf50d6981e62c4c/tinyusb2.patch) to work, while the WMO 1.1a (045E:0040) still fails to enumerate occasionally. Do you have the same problems with a different mouse and/or keyboard?

By the way, can you connect your keyboard and mouse to a Linux machine, and attach the output of `lsusb -v`?

hanshuebner, 2023-11-11:
I've verified that the problem only occurs with the Lenovo mouse, no matter what keyboard is connected.  The other mice that I tested work right away.

Here's the `lsusb` output for the mouse:

```
Bus 001 Device 028: ID 17ef:6019 Lenovo M-U0025-O Mouse
Device Descriptor:
  bLength                18
  bDescriptorType         1
  bcdUSB               2.00
  bDeviceClass            0
  bDeviceSubClass         0
  bDeviceProtocol         0
  bMaxPacketSize0         8
  idVendor           0x17ef Lenovo
  idProduct          0x6019 M-U0025-O Mouse
  bcdDevice            1.00
  iManufacturer           1 PixArt
  iProduct                2 Lenovo USB Optical Mouse
  iSerial                 0
  bNumConfigurations      1
  Configuration Descriptor:
    bLength                 9
    bDescriptorType         2
    wTotalLength       0x0022
    bNumInterfaces          1
    bConfigurationValue     1
    iConfiguration          0
    bmAttributes         0xa0
      (Bus Powered)
      Remote Wakeup
    MaxPower              100mA
    Interface Descriptor:
      bLength                 9
      bDescriptorType         4
      bInterfaceNumber        0
      bAlternateSetting       0
      bNumEndpoints           1
      bInterfaceClass         3 Human Interface Device
      bInterfaceSubClass      1 Boot Interface Subclass
      bInterfaceProtocol      2 Mouse
      iInterface              0
        HID Device Descriptor:
          bLength                 9
          bDescriptorType        33
          bcdHID               1.11
          bCountryCode            0 Not supported
          bNumDescriptors         1
          bDescriptorType        34 Report
          wDescriptorLength      46
         Report Descriptors:
           ** UNAVAILABLE **
      Endpoint Descriptor:
        bLength                 7
        bDescriptorType         5
        bEndpointAddress     0x81  EP 1 IN
        bmAttributes            3
          Transfer Type            Interrupt
          Synch Type               None
          Usage Type               Data
        wMaxPacketSize     0x0004  1x 4 bytes
        bInterval              10
Device Status:     0x0000
  (Bus Powered)
```

delan, 2023-11-11:
Thanks! I’ve [added](https://github.com/delan/usb3sun/commit/dc965b92e0eb1cb8f02df57a9f5b368a1d7067d7) this to the compatibility list. To help me diagnose the problem, can you flash the firmware below and attach the output you see on the UART_TX header? Set your UART to 115200 8N1, and be sure to connect both UART_TX and GND. If flashed correctly, your display will say “5a88d79f53.01” and the Sun keyboard interface will be disabled.

https://bucket.daz.cat/usb3sun/5a88d79f53.01%5B115200%2C8N1%2CUHID_VERBOSE%2CCFG_TUSB_DEBUG%3D3%5D.uf2

hanshuebner, 2023-11-11:
Here is the log file.  WIth the debug firmware, the timing seems to be different enough to make the enumeration at power-up somewhat work, although the tones don't sound quite right to me.  I recorded videos with the debug and the non-debug firmware for comparison:

[ZOC2311__dev_tty.usbserial-1221200309.log](https://github.com/delan/usb3sun/files/13325841/ZOC2311__dev_tty.usbserial-1221200309.log)

https://photos.app.goo.gl/pNuCwReeYDb4q52j6 (debug firmware)
https://photos.app.goo.gl/WJcabqi5TXRbQhb89 (non-debug firmware)

hanshuebner, 2023-11-12:
Hi Delan, I'm seeing the same issue with other keyboard/mouse combinations, so it does not seem to be a specific incompatibility.  How can I help diagnosing this further?

delan, 2023-11-12:
This smells a lot like [a previous tinyusb bug](https://cohost.org/delan/post/787278-usb3sun-a-usb-input#user-content-usb3sun-heisenbug) with the Microsoft Wired Keyboards 600 and 400, which I found by removing TU_LOG2 and TU_LOG3 lines until I could reproduce the problem, then inserting a delay accordingly (see [tinyusb2.patch](https://github.com/delan/usb3sun/blob/69845a2542b733e7301189c8374efba7ddb3d28a/tinyusb2.patch)).

I can try upgrading [tinyusb](https://github.com/adafruit/Adafruit_TinyUSB_Arduino) and [pico pio usb](https://github.com/sekigon-gonnoc/Pico-PIO-USB) again next weekend, since they are [currently held back](https://cohost.org/delan/post/1650431-usb3sun-rev-a1-a-us#user-content-usb3sun-usb-shenanigans) due to regressions that I haven’t yet investigated. In the meantime, you can try binary searching the log messages until you find a place where we can try inserting a delay, like I did for those Microsoft keyboards.

If you haven’t already tried the [prebuilt firmware 1.5](https://github.com/delan/usb3sun/releases/tag/1.5), be sure to try that first in case that solves your problem.

hanshuebner, 2023-11-12:
I've tried the 1.5 release binary and with that, the problem does not exist.  That puzzles me because I have built the firmware from the default branch, and there are no differences in the firmware compared to 1.5.  I'm using a Mac, but I'm not sure how that'd matter.  In any case, I think the problem is solved for me now.

delan, 2023-11-13:
I wonder if there’s a gap in our build process causing a build reproducibility problem. Did you remember to apply the two patches in [the firmware docs](https://github.com/delan/usb3sun/blob/69845a2542b733e7301189c8374efba7ddb3d28a/doc/firmware.md)? Can you tell me:

- the sha256 of the firmware.uf2 or firmware.elf you built
- what commit you built it from
- the output of pio pkg list

hanshuebner, 2023-11-13:
I'm more inclined to think that I have a gap in my documentation reading process.  With the two patches applied, the firmware I built works just fine.  I feel particularly stupid because of this:

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

Thank you for your help!

Closed 2023-11-12.

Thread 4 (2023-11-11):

05AC:024F Apple Magic Keyboard with Numeric Keypad (model A1243)

delan, 2023-11-11:
reported by Anthony Sorace in http://a.9srv.net/reports/usb3sun.html

plan 9 /dev/usb/ctl:

```
ep9.0 enabled control rw speed high maxpkt 64 pollival 0 samplesz 0 hz 0 hub 4 port 3 rootport 1 addr 7 busy
hub csp 0x010009 ports 3 ’Apple, Inc.’ ’Keyboard Hub’ xhci
ep10.0 enabled control rw speed low maxpkt 8 pollival 0 samplesz 0 hz 0 hub 7 port 2 rootport 1 addr 8 busy
hid csp 0x010103 csp 0x000003 vid 0x05ac did 0x024f ’Apple Inc.’ ’Apple Keyboard’ xhci
ep10.1 enabled interrupt r speed low maxpkt 8 pollival 10 samplesz 0 hz 0 hub 7 port 2 rootport 1 addr 8 busy
```

delan, 2023-11-11:
> The usb3sun makes no beep on connect, but makes the standard beep on disconnect.

this suggests we are getting our tuh_umount_cb (note: not tuh_hid_umount_cb) on disconnect, but not our tuh_hid_mount_cb (note: not tuh_mount_cb) on connect.

> If a different (working) keyboard is attached, it behaves normally. If the Apple keyboard is re-attached, though, the usb3sun seems hung: no connections from any keyboard are recognized, and no beep is emited on disconnecting the Apple keyboard.

this suggests the usb stack may be hitting an assertion failure or one of its device limits.

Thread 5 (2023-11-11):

1209:2303 Atreus (Keyboardio version) keyboard with Kaleidoscope

delan, 2023-11-11:
reported by Anthony Sorace in http://a.9srv.net/reports/usb3sun.html

plan 9 /dev/usb/ctl:

```
ep12.0 enabled control rw speed full maxpkt 64 pollival 0 samplesz 0 hz 0 hub 4 port 3 rootport 1 addr 15 busy
239 csp 0x0102ef csp 0x000202 csp 0x00000a csp 0x000003 csp 0x000003 csp 0x010103 vid 0x1209 did 0x2303 Keyboardio Atreus xhci
ep12.6 enabled interrupt r speed full maxpkt 64 pollival 1 samplesz 0 hz 0 hub 4 port 3 rootport 1 addr 15 busy
```

delan, 2023-11-11:
> The usb3sun makes no beep on connect, but makes the standard beep on disconnect.

this suggests we are getting our tuh_umount_cb (note: not tuh_hid_umount_cb) on disconnect, but not our tuh_hid_mount_cb (note: not tuh_mount_cb) on connect.

> If a different (working) keyboard is attached, it behaves normally. If the Apple keyboard is re-attached, though, the usb3sun seems hung: no connections from any keyboard are recognized, and no beep is emited on disconnecting the Apple keyboard.

this suggests the usb stack may be hitting an assertion failure or one of its device limits.

delan, 2023-11-11:
> Notably, the Keyboardio Atreus does not exhibit this behavior; the usb3sun beeps on connect/disconnect as for the working keyboards.

this suggests we are getting both our tuh_hid_mount_cb (note: not tuh_mount_cb) on connect, and our tuh_umount_cb (note: not tuh_hid_umount_cb) on disconnect.

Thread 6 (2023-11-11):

3367:1903 Endgame Gear XM1r mouse

delan, 2023-11-11:
buttons only (16-bit dx/dy, no boot protocol)

```
$ sudo lsusb -vd 3367:1903
Bus 005 Device 002: ID 3367:1903 EndGameGear XM1 Gaming Mouse
Device Descriptor:
  bLength                18
  bDescriptorType         1
  bcdUSB               2.00
  bDeviceClass            0
  bDeviceSubClass         0
  bDeviceProtocol         0
  bMaxPacketSize0        64
  idVendor           0x3367
  idProduct          0x1903
  bcdDevice            2.00
  iManufacturer           1 EndGameGear
  iProduct                2 XM1 Gaming Mouse
  iSerial                 3 0000000000000000
  bNumConfigurations      1
  Configuration Descriptor:
    bLength                 9
    bDescriptorType         2
    wTotalLength       0x0054
    bNumInterfaces          3
    bConfigurationValue     1
    iConfiguration          2 XM1 Gaming Mouse
    bmAttributes         0xa0
      (Bus Powered)
      Remote Wakeup
    MaxPower              500mA
    Interface Descriptor:
      bLength                 9
      bDescriptorType         4
      bInterfaceNumber        0
      bAlternateSetting       0
      bNumEndpoints           1
      bInterfaceClass         3 Human Interface Device
      bInterfaceSubClass      1 Boot Interface Subclass
      bInterfaceProtocol      2 Mouse
      iInterface              5 HID Device
        HID Device Descriptor:
          bLength                 9
          bDescriptorType        33
          bcdHID               1.11
          bCountryCode            0 Not supported
          bNumDescriptors         1
          bDescriptorType        34 Report
          wDescriptorLength      67
         Report Descriptors:
           ** UNAVAILABLE **
      Endpoint Descriptor:
        bLength                 7
        bDescriptorType         5
        bEndpointAddress     0x81  EP 1 IN
        bmAttributes            3
          Transfer Type            Interrupt
          Synch Type               None
          Usage Type               Data
        wMaxPacketSize     0x0008  1x 8 bytes
        bInterval               1
    Interface Descriptor:
      bLength                 9
      bDescriptorType         4
      bInterfaceNumber        1
      bAlternateSetting       0
      bNumEndpoints           1
      bInterfaceClass         3 Human Interface Device
      bInterfaceSubClass      0
      bInterfaceProtocol      0
      iInterface              5 HID Device
        HID Device Descriptor:
          bLength                 9
          bDescriptorType        33
          bcdHID               1.11
          bCountryCode            0 Not supported
          bNumDescriptors         1
          bDescriptorType        34 Report
          wDescriptorLength     158
         Report Descriptors:
           ** UNAVAILABLE **
      Endpoint Descriptor:
        bLength                 7
        bDescriptorType         5
        bEndpointAddress     0x82  EP 2 IN
        bmAttributes            3
          Transfer Type            Interrupt
          Synch Type               None
          Usage Type               Data
        wMaxPacketSize     0x0015  1x 21 bytes
        bInterval               1
    Interface Descriptor:
      bLength                 9
      bDescriptorType         4
      bInterfaceNumber        2
      bAlternateSetting       0
      bNumEndpoints           1
      bInterfaceClass         3 Human Interface Device
      bInterfaceSubClass      0
      bInterfaceProtocol      0
      iInterface              5 HID Device
        HID Device Descriptor:
          bLength                 9
          bDescriptorType        33
          bcdHID               1.11
          bCountryCode            0 Not supported
          bNumDescriptors         1
          bDescriptorType        34 Report
          wDescriptorLength      38
         Report Descriptors:
           ** UNAVAILABLE **
      Endpoint Descriptor:
        bLength                 7
        bDescriptorType         5
        bEndpointAddress     0x83  EP 3 IN
        bmAttributes            3
          Transfer Type            Interrupt
          Synch Type               None
          Usage Type               Data
        wMaxPacketSize     0x0040  1x 64 bytes
        bInterval               1
Device Status:     0x0001
  Self Powered
```

delan, 2025-04-24:
this device does advertise support for the boot mouse protocol, but if we send a Set_Protocol to switch from report protocol to boot protocol, the switch succeeds but no more reports are ever sent. cool.

that our firmware doesn’t do that yet is a bug (#19), but even once we fix that, we’ll need proper report protocol parsing to make this mouse work.

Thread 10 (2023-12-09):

support debug logging without disabling sun keyboard

delan, 2023-12-09:
unlike logging to usb cdc, logging to the debug header allows us to debug usb problems (CFG_TUSB_DEBUG), but this requires three uarts and the rp2040 only has two, so we currently disable the sun keyboard when doing so. wouldn’t it be nice if the debug header (tx + rx, but rx unused so far) could work without disabling the sun keyboard (tx + rx) or mouse (tx only)?

the good news is, [SerialPIO](https://arduino-pico.readthedocs.io/en/latest/piouart.html) allows us to set up a third uart, freeing up one of the hardware uarts for debugging. the docs say SoftwareSerial (and SerialPIO?) don’t support inverted mode, which are needed for the sun interfaces, but thankfully this is not (or no longer?) true.

to avoid running out of pio resources when beeping, we would need to go back to using analogWrite (hardware pwm) instead of tone (pio) for the buzzer (reverting 8922fe6f6ba269e96bbdb21e620982492abc54a7), but that’s ok.

the bad news is, there seems to be no way to actually do this without pcb changes. here are our requirements:

- usb tx needs 1/4 sm and 22/32 instructions ([usb_tx.pio](https://github.com/sekigon-gonnoc/Pico-PIO-USB/blob/0f747aaa0c16f750bdfa2ba37ec25d6c8e1bc117/src/usb_tx.pio))
- usb rx needs 2/4 sm and 31/32 instructions ([usb_rx.pio](https://github.com/sekigon-gonnoc/Pico-PIO-USB/blob/0f747aaa0c16f750bdfa2ba37ec25d6c8e1bc117/src/usb_rx.pio))
- SerialPIO tx needs 1/4 sm and 6/32 instructions ([pio_tx_inv](https://github.com/earlephilhower/arduino-pico/blob/0c7454b6f78e8e548ce8307ba533fa5b021b0483/cores/rp2040/pio_uart.pio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), [pio_tx_inv_program_instructions](https://github.com/earlephilhower/arduino-pico/blob/0c7454b6f78e8e548ce8307ba533fa5b021b0483/cores/rp2040/pio_uart.pio.h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))
- SerialPIO rx needs 1/4 sm and 7/32 instructions ([pio_rx_inv](https://github.com/earlephilhower/arduino-pico/blob/0c7454b6f78e8e548ce8307ba533fa5b021b0483/cores/rp2040/pio_uart.pio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), [pio_rx_inv_program_instructions](https://github.com/earlephilhower/arduino-pico/blob/0c7454b6f78e8e548ce8307ba533fa5b021b0483/cores/rp2040/pio_uart.pio.h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))
- UART_TX wired to pin 0 (valid for UART0 or SerialPIO)
- UART_RX wired to pin 1 (valid for UART0 or SerialPIO)
- INT_KTX wired to pin 12 (valid for UART0 or SerialPIO)
- INT_KRX wired to pin 13 (valid for UART0 or SerialPIO)
- INT_MTX wired to pin 8 (valid for UART1 or SerialPIO)
- debug console needs to be on a hardware UART?

if we move sun mouse tx to SerialPIO (and bump pio_cfg.sm_tx etc accordingly), both the sun and usb interfaces still work, and this frees up hardware UART1! but UART1 is not allowed on pins 0 + 1 (UART_TX + UART_RX).

if we move sun keyboard tx and rx to SerialPIO (and bump pio_cfg.sm_tx etc accordingly), we are guaranteed to run out of pio instruction space for usb, because 6+7+min(22,31)>32 and min(6,7)+max(22,31)>32.

if we move sun keyboard tx only to SerialPIO (and bump pio_cfg.sm_tx etc accordingly), we can free up hardware UART0 tx for debug logging! believe it or not, UART0 can be set to tx on pin 0 (UART_TX) and rx on pin 13 (INT_KRX)! but sharing it with the sun keyboard like this means we need to log at 1200 baud, which not only [would need](https://github.com/raspberrypi/picoprobe/blob/721b69cf5c8535e57995dbdd2e74f1bbc2f36944/include/board_pico_config.h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) a modified picoprobe firmware, but is also extremely slow: it takes 80(!) seconds to boot usb3sun with all debug logging on.

so we have three options, unless there’s some way to run the debug console over SerialPIO:
1. move sun mouse to SerialPIO, rewire UART_TX + UART_RX to pins valid for UART1
2. move sun mouse to SerialPIO, move sun keyboard to UART1, rewire sun keyboard to pins valid for UART1
3. do nothing, at least until we need a new pcb rev for some other reason

delan, 2024-05-25:
fixed in [pcb rev B0](https://github.com/delan/usb3sun/releases/tag/B0)

Closed 2024-05-25.

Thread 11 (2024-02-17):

adapter can hang until power cycled after being reset

delan, 2024-02-17:
when resetting the adapter, the firmware can start getting stuck in Adafruit_SSD1306::begin or the initial Adafruit_SSD1306::display (pico led on), until the adapter is power cycled. this is especially likely to happen if you mash the reset button several times in quick succession. stack trace:

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

our 4pin i2c display (U2) [doesn’t expose RES#](https://github.com/adafruit/Adafruit_SSD1306/issues/106#issuecomment-359274073), so we need to switch U2.VCC externally.

delan, 2024-05-25:
fixed in [pcb rev B0](https://github.com/delan/usb3sun/releases/tag/B0)

Closed 2024-05-25.

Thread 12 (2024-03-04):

regressions when upgrading Pico PIO USB to 0.5.3

delan, 2024-03-04:
- usb3sun d59f48b6d3e4939538a4ba5fd8dfc1c40b121cac
- Microsoft Wired Keyboard 600 (045E:0750)

[Pico PIO USB](https://github.com/sekigon-gonnoc/Pico-PIO-USB)
- 0.5.2 = works
- 9357706baa587f8b23010e5751cfb77354d4a08e = works
- 58879cfa0eca5725d8db6443ec17f8896a321042 = Control FAILED
- 0.5.3 = Control FAILED

cause seems to be sekigon-gonnoc/Pico-PIO-USB#88
- sof_count mask increases from 0x1f (5-bit) to 0x7ff (11-bit)
- 0x3ff (10-bit) = Control FAILED
- 0x1ff (9-bit) = works

delan, 2024-03-04:
when upgrading Adafruit TinyUSB Library to 3.1.0 (#13), the failure mode is different, but the same workaround works

```
[1:1] Class Request: 21 0A 00 00 01 00 00 00
on EP 81 with 0 bytes: FAILED
HID xfer callback
  Get Report callback (1, 0)
[1] Claimed EP 0x81
  Queue EP 81 with 8 bytes ...
OK
on EP 00 with 8 bytes: FAILED
[1:1] Control FAILED, xferred_bytes = 8
21 0A 00 00 01 00 00 00

HID Get Report Descriptor
[1:1] Get Descriptor: 81 06 00 22 01 00 6A 00
on EP 81 with 0 bytes: FAILED
HID xfer callback
  Get Report callback (1, 0)
[1] Claimed EP 0x81
  Queue EP 81 with 8 bytes ...
OK
on EP 00 with 8 bytes: FAILED
[1:1] Control FAILED, xferred_bytes = 8
81 06 00 22 01 00 6A 00

process_set_config 582: ASSERT FAILED
on EP 81 with 0 bytes: FAILED
HID xfer callback
  Get Report callback (1, 0)
[1] Claimed EP 0x81
  Queue EP 81 with 8 bytes ...
OK
on EP 81 with 0 bytes: FAILED
HID xfer callback
  Get Report callback (1, 0)
[1] Claimed EP 0x81
  Queue EP 81 with 8 bytes ...
OK
on EP 81 with 0 bytes: FAILED
HID xfer callback
  Get Report callback (1, 0)
[1] Claimed EP 0x81
  Queue EP 81 with 8 bytes ...
OK
on EP 81 with 0 bytes: FAILED
[...]
```

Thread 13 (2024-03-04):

regressions when upgrading Adafruit TinyUSB Library to 3.1.0

delan, 2024-03-04:
- usb3sun d59f48b6d3e4939538a4ba5fd8dfc1c40b121cac
- Microsoft Wired Keyboard 600 (045E:0750)

[Adafruit TinyUSB Library](https://github.com/adafruit/Adafruit_TinyUSB_Arduino)
- 2.0.1 = works
- 3.1.0 = adafruit/Adafruit_TinyUSB_Arduino#296
- successful workaround in [tinyusb3.patch.txt](https://github.com/delan/usb3sun/files/14480101/tinyusb3.patch.txt)

status of other patches with 3.1.0
- [tinyusb1.patch](https://github.com/delan/usb3sun/blob/d59f48b6d3e4939538a4ba5fd8dfc1c40b121cac/tinyusb1.patch) is definitely no longer required
- [tinyusb2.patch](https://github.com/delan/usb3sun/blob/d59f48b6d3e4939538a4ba5fd8dfc1c40b121cac/tinyusb1.patch) seems to no longer be required?
  - we should bisect and figure out why
- we need to update [debug1.patch](https://github.com/delan/usb3sun/blob/d59f48b6d3e4939538a4ba5fd8dfc1c40b121cac/debug1.patch) → [debug1.patch.txt](https://github.com/delan/usb3sun/files/14480123/debug1.patch.txt)
  - `#include <Arduino.h>` in Adafruit_TinyUSB.h now yields “undefined reference to _ZN17Adafruit_USBD_CDC16getInstanceCountEv”
  - moving the declaration to the local Adafruit_TinyUSB_API.h in .pio doesn’t work, we need to patch the copy in ~/.platformio/packages/framework-arduinopico
  - using HardwareSerial in declaration now yields “'HardwareSerial' does not name a type” due to circular include
- we now need [debug3.patch.txt](https://github.com/delan/usb3sun/files/14480120/debug3.patch.txt)
  `git -C ~/.platformio/packages/framework-arduinopico apply $PWD/debug3.patch`

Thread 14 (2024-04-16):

writing settings can cause usb devices to malfunction

delan, 2024-04-16:
- affects pcb rev A3 and firmware 1.5
- affects Microsoft Wheel Mouse Optical 1.1A (045E:0040)
    - writing settings has a >20% chance of causing malfunction
    - red led goes dim, mouse spews reports until disconnected
- probably due to suspending interrupts and pausing the other core when writing to flash
    - same failure if you replace Settings::write impl with just noInterrupts() + sleep_ms(5) + interrupts()

delan, 2024-05-25:
workaround in [firmware 2.0](https://github.com/delan/usb3sun/releases/tag/2.0): settings are now saved when you close the menu, and you can hold **Shift** to reboot the adapter after saving (**Shift+Enter**).

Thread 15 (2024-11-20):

“The IDPROM contents are invalid” when reprogramming on Ultra5

delan, 2024-11-20:
before reprogramming:

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

after reprogramming:

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

Ultra5 has no real-machine-type (`real-machine-type ?`), so the system type byte and first byte of date are left unchanged. this usually ends up being FFh in both cases, but that seems to be invalid, even though the checksum is definitely still 29h:

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

delan, 2024-11-20:
after 1738e5ddd6aa367606f4d0a663db2160774e77ad:

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

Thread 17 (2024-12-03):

Linker error when compiling newest firmware (Ubuntu MATE 22.04 LTS, Kernel 5.15 x86_64)

europa64, 2024-12-03:
I've been working on getting the newest firmware compiled, and I've run into a linker error.

Here's my `uname` string:
`Linux 5.15.0-78-generic #85-Ubuntu SMP Fri Jul 7 15:25:09 UTC 2023 x86_64 GNU/Linux`

and here's the error itself:
```/home/europa/.platformio/packages/toolchain-rp2040-earlephilhower/bin/../lib/gcc/arm-none-eabi/14.2.0/../../../../arm-none-eabi/bin/ld: warning: /home/europa/.platformio/packages/toolchain-rp2040-earlephilhower/bin/../lib/gcc/arm-none-eabi/14.2.0/thumb/crtn.o: missing .note.GNU-stack section implies executable stack
/home/europa/.platformio/packages/toolchain-rp2040-earlephilhower/bin/../lib/gcc/arm-none-eabi/14.2.0/../../../../arm-none-eabi/bin/ld: NOTE: This behaviour is deprecated and will be removed in a future version of the linker
/home/europa/.platformio/packages/toolchain-rp2040-earlephilhower/bin/../lib/gcc/arm-none-eabi/14.2.0/../../../../arm-none-eabi/bin/ld: warning: .pio/build/pico/firmware.elf has a LOAD segment with RWX permissions
/home/europa/.platformio/packages/toolchain-rp2040-earlephilhower/bin/../lib/gcc/arm-none-eabi/14.2.0/../../../../arm-none-eabi/bin/ld: /home/europa/.platformio/packages/toolchain-rp2040-earlephilhower/bin/../lib/gcc/arm-none-eabi/14.2.0/../../../../arm-none-eabi/lib/thumb/libc.a(libc_a-findfp.o): in function `std':
/workdir/repo/newlib/newlib/libc/stdio/findfp.c:93:(.text+0xda): undefined reference to `__retarget_lock_init_recursive'
/home/europa/.platformio/packages/toolchain-rp2040-earlephilhower/bin/../lib/gcc/arm-none-eabi/14.2.0/../../../../arm-none-eabi/bin/ld: /workdir/repo/newlib/newlib/libc/stdio/findfp.c:93:(.text+0x124): undefined reference to `__retarget_lock_init_recursive'
/home/europa/.platformio/packages/toolchain-rp2040-earlephilhower/bin/../lib/gcc/arm-none-eabi/14.2.0/../../../../arm-none-eabi/bin/ld: /workdir/repo/newlib/newlib/libc/stdio/findfp.c:93:(.text+0x17c): undefined reference to `__retarget_lock_init_recursive'
/home/europa/.platformio/packages/toolchain-rp2040-earlephilhower/bin/../lib/gcc/arm-none-eabi/14.2.0/../../../../arm-none-eabi/bin/ld: /home/europa/.platformio/packages/toolchain-rp2040-earlephilhower/bin/../lib/gcc/arm-none-eabi/14.2.0/../../../../arm-none-eabi/lib/thumb/libc.a(libc_a-findfp.o): in function `__sfp':
/workdir/repo/newlib/newlib/libc/stdio/findfp.c:201:(.text+0x1ea): undefined reference to `__retarget_lock_init_recursive'
collect2: error: ld returned 1 exit status
*** [.pio/build/pico/firmware.elf] Error 1
```

delan, 2025-02-26:
thanks for the report! i can reproduce this on nixos with a fresh `~/.platformio` and `.pio`:

```
/home/delan/.platformio/packages/toolchain-rp2040-earlephilhower/bin/../lib/gcc/arm-none-eabi/14.2.0/../../../../arm-none-eabi/bin/ld: warning: /home/delan/.platformio/packages/toolchain-rp2040-earlephilhower/bin/../lib/gcc/arm-none-eabi/14.2.0/thumb/crtn.o: missing .note.GNU-stack section implies executable stack
/home/delan/.platformio/packages/toolchain-rp2040-earlephilhower/bin/../lib/gcc/arm-none-eabi/14.2.0/../../../../arm-none-eabi/bin/ld: NOTE: This behaviour is deprecated and will be removed in a future version of the linker
/home/delan/.platformio/packages/toolchain-rp2040-earlephilhower/bin/../lib/gcc/arm-none-eabi/14.2.0/../../../../arm-none-eabi/bin/ld: warning: .pio/build/pico/firmware.elf has a LOAD segment with RWX permissions
/home/delan/.platformio/packages/toolchain-rp2040-earlephilhower/bin/../lib/gcc/arm-none-eabi/14.2.0/../../../../arm-none-eabi/bin/ld: /home/delan/.platformio/packages/toolchain-rp2040-earlephilhower/bin/../lib/gcc/arm-none-eabi/14.2.0/../../../../arm-none-eabi/lib/thumb/libc.a(libc_a-findfp.o): in function `std':
/workdir/repo/newlib/newlib/libc/stdio/findfp.c:93:(.text+0xda): undefined reference to `__retarget_lock_init_recursive'
/home/delan/.platformio/packages/toolchain-rp2040-earlephilhower/bin/../lib/gcc/arm-none-eabi/14.2.0/../../../../arm-none-eabi/bin/ld: /workdir/repo/newlib/newlib/libc/stdio/findfp.c:93:(.text+0x124): undefined reference to `__retarget_lock_init_recursive'
/home/delan/.platformio/packages/toolchain-rp2040-earlephilhower/bin/../lib/gcc/arm-none-eabi/14.2.0/../../../../arm-none-eabi/bin/ld: /workdir/repo/newlib/newlib/libc/stdio/findfp.c:93:(.text+0x17c): undefined reference to `__retarget_lock_init_recursive'
/home/delan/.platformio/packages/toolchain-rp2040-earlephilhower/bin/../lib/gcc/arm-none-eabi/14.2.0/../../../../arm-none-eabi/bin/ld: /home/delan/.platformio/packages/toolchain-rp2040-earlephilhower/bin/../lib/gcc/arm-none-eabi/14.2.0/../../../../arm-none-eabi/lib/thumb/libc.a(libc_a-findfp.o): in function `__sfp':
/workdir/repo/newlib/newlib/libc/stdio/findfp.c:201:(.text+0x1ea): undefined reference to `__retarget_lock_init_recursive'
```

it looks like this is maxgerhardt/platform-raspberrypi#79 (and [several others](https://github.com/maxgerhardt/platform-raspberrypi/issues?q=__retarget_lock_init_recursive)), caused by me pinning the framework version but failing to pin the platform version. i’ll pin the platform to a compatible version.

delan, 2025-02-26:
a02bb3ebe49d80b7ca608287310b9c2a175e3397 should fix this. let me know how you go :)

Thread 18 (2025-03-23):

main arrow keys on usb keyboards are unmapped

delan, 2025-03-23:

techomancer, 2025-06-15:
yeah, super annoying because I only have tenkeyless keyboards in my house (i have a thing agains numpads).
also del does not work as del in sunpci, i guess it sends different scancode?
would it be possible to add alternate mapping maybe with right control to send numpad del?
i really do not want to buy big keyboard, but maybe i will have to for amiga 2000 and amigahid-pico

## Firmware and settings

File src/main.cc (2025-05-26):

#include "config.h"

#include <atomic>

#ifdef USB3SUN_HAL_ARDUINO_PICO
#include <Arduino.h>
#include <Adafruit_TinyUSB.h>
#endif

#include "bindings.h"
#include "buzzer.h"
#include "cli.h"
#include "hal.h"
#include "menu.h"
#include "pinout.h"
#include "rust.h"
#include "settings.h"
#include "state.h"
#include "sunm.h"
#include "sunk.h"
#include "usb.h"
#include "view.h"

const char *const MODIFIER_NAMES[] = {
  "CtrlL", "ShiftL", "AltL", "GuiL",
  "CtrlR", "ShiftR", "AltR", "GuiR",
};

const char *const BUTTON_NAMES[] = {
  "LeftClick", "RightClick", "MiddleClick", "MouseBack", "MouseForward",
};

enum class Message : uint32_t {
  UHID_LED_FROM_STATE,
  UHID_LED_ALL_OFF,
  UHID_LED_ALL_ON,
};

// core 1 only
struct {
  bool present = false;
  uint8_t dev_addr;
  uint8_t instance;
  uint8_t if_protocol;
  struct {
    bool present = false;
    uint8_t report_id;
    uint8_t report;
  } led;
} hid[16];

std::atomic<bool> waiting = true;

Pinout pinout;
State state;
Buzzer buzzer;
Settings settings;
USB3SUN_MUTEX usb3sun_mutex buzzerMutex;
USB3SUN_MUTEX usb3sun_mutex settingsMutex;

void drawStatus(int16_t x, int16_t y, const char *label, bool on);

struct DefaultView : View {
  const char *name() const override {
    return "DefaultView";
  }

  void handlePaint() override {
    usb3sun_display_text(0, 0, false, USB3SUN_VERSION);
    drawStatus(78, 0, "CLK", state.clickEnabled);
    drawStatus(104, 0, "BEL", state.bell);
    drawStatus(0, 18, "CAP", state.caps);
    drawStatus(26, 18, "CMP", state.compose);
    drawStatus(52, 18, "SCR", state.scroll);
    drawStatus(78, 18, "NUM", state.num);
    if (buzzer.current != Buzzer::_::NONE) {
      const auto x = 106;
      const auto y = 16;
      usb3sun_display_rect(x + 6, y + 1, 2, 11, 0, false, true);
      usb3sun_display_rect(x + 5, y + 2, 4, 10, 0, false, true);
      usb3sun_display_rect(x + 4, y + 4, 6, 8, 0, false, true);
      usb3sun_display_rect(x + 2, y + 9, 10, 3, 0, false, true);
      usb3sun_display_rect(x + 1, y + 10, 12, 2, 0, false, true);
      usb3sun_display_rect(x + 5, y + 13, 4, 1, 0, false, true);
    } else {
      usb3sun_display_rect(106, 16, 14, 14, 0, true, true);
    }
  }

  void handleKey(const UsbkChanges &changes) override {
#ifdef DEBUG_TIMINGS
    unsigned long t = usb3sun_micros();
#endif

#ifdef SUNK_ENABLE
    for (size_t i = 0; i < changes.dvLen; i++) {
      // for DV bindings, make when key makes and break when key breaks
      if (uint8_t sunkMake = USBK_TO_SUNK.dv[changes.dv[i].usbkModifier])
        sunkSend(changes.dv[i].make, sunkMake);
    }
#endif

    // treat simultaneous DV and Sel changes as DV before Sel, for special bindings
    const uint8_t lastModifiers = changes.kreport.modifier;

    for (size_t i = 0; i < changes.selLen; i++) {
      const uint8_t usbkSelector = changes.sel[i].usbkSelector;
      const uint8_t make = changes.sel[i].make;

      // CtrlR+Space acts like a special binding, but opens the settings menu
      // note: no other modifiers are allowed, to avoid getting them stuck down
      if (changes.sel[i].usbkSelector == USBK_SPACE && lastModifiers == USBK_CTRL_R) {
        MENU_VIEW.open();
        continue;
      }

      static bool specialBindingIsPressed[256]{};
      bool consumedBySpecialBinding[256]{};

      // for special bindings (CtrlR+Sel):
      // • make when the Sel key makes and the DV keys include CtrlR
      // • break when the Sel key breaks, even if the DV keys no longer include CtrlR
      // • do not make when CtrlR makes after the Sel key makes
      if (uint8_t sunkMake = USBK_TO_SUNK.special[usbkSelector]) {
        if (make && !!(state.lastModifiers & USBK_CTRL_R)) {
          sunkSend(true, sunkMake);
          specialBindingIsPressed[usbkSelector] = true;
          consumedBySpecialBinding[usbkSelector] = true;
        } else if (!make && specialBindingIsPressed[usbkSelector]) {
          sunkSend(false, sunkMake);
          specialBindingIsPressed[usbkSelector] = false;
          consumedBySpecialBinding[usbkSelector] = true;
        }
      }

      // for Sel bindings
      // • make when key makes and break when key breaks
      // • do not make or break when key was consumed by the corresponding special binding
      if (uint8_t sunkMake = USBK_TO_SUNK.sel[usbkSelector])
        if (!consumedBySpecialBinding[usbkSelector])
          sunkSend(make, sunkMake);
    }

#ifdef DEBUG_TIMINGS
    Sprintf("sent in %ju\n", usb3sun_micros() - t);
#endif
  }
};

static DefaultView DEFAULT_VIEW{};

void setup() {
  // pico led on, then configure pin modes
  pinout.begin();
  Sprintln("usb3sun " USB3SUN_VERSION);
  Sprintf("pinout: v%zu\n", usb3sun_pinout_version());

  usb3sun_display_init();
  Settings::begin();
  settings.readAll();
  pinout.beginSun();

  View::push(&DEFAULT_VIEW);

#ifdef WAIT_PIN
  while (usb3sun_gpio_read(WAIT_PIN));
#endif
#ifdef WAIT_SERIAL
  while (usb3sun_debug_cdc_read() == -1);
#endif
  waiting = false;

  usb3sun_gpio_write(LED_PIN, false);
}

void drawStatus(int16_t x, int16_t y, const char *label, bool on) {
  usb3sun_display_rect(x, y, 24, 14, 4, false, on);
  usb3sun_display_text(x + 3, y + 4, on, label);
}

void loop() {
  usb3sun_display_clear();
  View::paint();
  usb3sun_display_flush();

#ifdef UHID_LED_TEST
  static int z = 0;
  Message message = ++z % 2 == 0
    ? Message::UHID_LED_ALL_OFF
    : Message::UHID_LED_ALL_ON;
  usb3sun_fifo_push((uint32_t)message);
#endif

  int input;
  while ((input = usb3sun_debug_uart_read()) != -1) {
    handleCliInput(input);
  }
#ifdef SUNK_SNIFFER_ENABLE
  while ((input = usb3sun_sunk_sniff_tx()) != -1) {
    uint8_t command = input;
    Sprintf("sunk: sniff tx %02Xh (%d)\n", command, command);
  }
#endif


  usb3sun_sleep_micros(10'000);
}

#if defined(SUNK_ENABLE) || defined(SUNK_SNIFFER_ENABLE)
void sunkEvent() {
  int result;
  while ((result = usb3sun_sunk_read()) != -1) {
    uint8_t command = result;
    Sprintf("sunk: rx %02Xh\n", command);
    switch (command) {
      case SUNK_RESET: {
#ifndef SUNK_SNIFFER_ENABLE
        // self test fail:
        // usb3sun_sunk_write(0x7E);
        // usb3sun_sunk_write(0x01);
        uint8_t response[]{SUNK_RESET_RESPONSE, 0x04, 0x7F}; // TODO optional make code
        usb3sun_sunk_write(response, sizeof response);
#endif
      } break;
      case SUNK_BELL_ON:
        state.bell = true;
        buzzer.update();
        break;
      case SUNK_BELL_OFF:
        state.bell = false;
        buzzer.update();
        break;
      case SUNK_CLICK_ON:
        state.clickEnabled = true;
        break;
      case SUNK_CLICK_OFF:
        state.clickEnabled = false;
        break;
      case SUNK_LED: {
        while ((result = usb3sun_sunk_read()) == -1) usb3sun_sleep_micros(1'000);
        uint8_t status = result;
        Sprintf("sunk: led status %02Xh\n", status);
        state.num = status & 1 << 0;
        state.compose = status & 1 << 1;
        state.scroll = status & 1 << 2;
        state.caps = status & 1 << 3;

        // ensure state update finished, then notify
        usb3sun_dmb();
        usb3sun_fifo_push((uint32_t)Message::UHID_LED_FROM_STATE);
      } break;
      case SUNK_LAYOUT: {
#ifndef SUNK_SNIFFER_ENABLE
        // UNITED STATES (TODO alternate layouts)
        uint8_t response[]{SUNK_LAYOUT_RESPONSE, 0b00000000};
        usb3sun_sunk_write(response, sizeof response);
#endif
      } break;
    }
  }
}
#endif

void serialEvent1() {
#if defined(SUNK_ENABLE) || defined(SUNK_SNIFFER_ENABLE)
  sunkEvent();
#endif
}

void serialEvent2() {
#if defined(SUNK_ENABLE) || defined(SUNK_SNIFFER_ENABLE)
  sunkEvent();
#endif
}

void setup1() {
  while (waiting);

  // Check for CPU frequency, must be multiple of 120Mhz for bit-banging USB
  uint32_t cpu_hz = usb3sun_clock_speed();
  if (cpu_hz != 120000000uL && cpu_hz != 240000000uL) {
    usb3sun_panic("error: cpu frequency %u, set [env:pico] board_build.f_cpu = 120000000L\n", cpu_hz);
  }

  usb3sun_usb_init();
}

void loop1() {
  uint32_t message;
  if (usb3sun_fifo_pop(&message)) {
    for (size_t i = 0; i < sizeof(hid) / sizeof(*hid); i++) {
      if (!hid[i].present || !hid[i].led.present)
        continue;
      uint8_t dev_addr = hid[i].dev_addr;
      uint8_t instance = hid[i].instance;
      uint8_t report_id = hid[i].led.report_id;
      switch (message) {
        case (uint32_t)Message::UHID_LED_FROM_STATE:
          hid[i].led.report =
            state.num << 0
            | state.caps << 1
            | state.scroll << 2
            | state.compose << 3;
          break;
        case (uint32_t)Message::UHID_LED_ALL_OFF:
          hid[i].led.report = 0x00;
          break;
        case (uint32_t)Message::UHID_LED_ALL_ON:
          hid[i].led.report = 0xFF;
          break;
      }
#if defined(UHID_LED_ENABLE)
#ifndef UHID_VERBOSE
      Sprint("*");
#endif
#ifdef UHID_VERBOSE
      Sprintf("hid [%zu]: usb [%u:%u]: set led report %02Xh\n", i, dev_addr, instance, hid[i].led.report);
#endif
      usb3sun_uhid_set_led_report(dev_addr, instance, report_id, hid[i].led.report);
#else
      (void) dev_addr;
      (void) instance;
      (void) report_id;
#endif
    }
  }
  usb3sun_usb_task();
  buzzer.update();
}

// Invoked when device with hid interface is mounted
// Report descriptor is also available for use.
// tuh_hid_parse_report_descriptor() can be used to parse common/simple enough
// descriptor. Note: if report descriptor length > CFG_TUH_ENUMERATION_BUFSIZE,
// it will be skipped therefore report_desc = NULL, desc_len = 0
void tuh_hid_mount_cb(uint8_t dev_addr, uint8_t instance, uint8_t const *desc_report, uint16_t desc_len) {
  uint16_t vid, pid;
  usb3sun_usb_vid_pid(dev_addr, &vid, &pid);
  Sprintf("usb [%u:%u]: hid mount vid:pid=%04x:%04x\n", dev_addr, instance, vid, pid);

  usb3sun_hid_report_info reports[16];
  size_t reports_len = usb3sun_uhid_parse_report_descriptor(reports, sizeof(reports) / sizeof(*reports), desc_report, desc_len);
  for (size_t i = 0; i < reports_len; i++)
    Sprintf("    reports[%zu] report_id=%u usage=%02Xh usage_page=%04Xh\n", i, reports[i].report_id, reports[i].usage, reports[i].usage_page);

  // hid_subclass_enum_t if_subclass = ...;
  uint8_t if_protocol = usb3sun_uhid_interface_protocol(dev_addr, instance);
  Sprintf("    bInterfaceProtocol=%u", if_protocol);
  switch (if_protocol) {
    case USB3SUN_UHID_KEYBOARD:
      Sprintln(" (boot keyboard)");
      break;
    case USB3SUN_UHID_MOUSE:
      Sprintln(" (boot mouse)");
      break;
    default:
      Sprintln();
  }

  // TODO non-boot input devices
  switch (if_protocol) {
    case USB3SUN_UHID_KEYBOARD:
    case USB3SUN_UHID_MOUSE: {
      bool ok = false;
      for (size_t i = 0; i < sizeof(hid) / sizeof(*hid); i++) {
        if (!hid[i].present) {
          Sprintf(
            "hid [%zu]: usb [%u:%u], bInterfaceProtocol=%u\n",
            i, dev_addr, instance, if_protocol
          );
          hid[i].dev_addr = dev_addr;
          hid[i].instance = instance;
          hid[i].if_protocol = if_protocol;
          hid[i].led.present = false;
          if (if_protocol == USB3SUN_UHID_KEYBOARD) {
            for (size_t j = 0; j < reports_len; j++) {
              if (reports[j].usage_page == 1 && reports[j].usage == 6) {
                hid[i].led.present = true;
                hid[i].led.report_id = reports[j].report_id;
                Sprintf("hid [%zu]: led report_id=%u\n", i, hid[i].led.report_id);
              }
            }
          }
          hid[i].present = true;
          ok = true;
          break;
        }
      }
      if (!ok)
        Sprintln("error: usb [%u:%u]: hid table full");
    }
  }

  if (!usb3sun_uhid_request_report(dev_addr, instance))
    Sprintf("error: usb [%u:%u]: failed to request to receive report\n", dev_addr, instance);

  buzzer.plug();
}

// FIXME this never seems to get called?
void tuh_hid_umount_cb(uint8_t dev_addr, uint8_t instance) {
  Sprintf("usb [%u:%u]: hid unmount\n", dev_addr, instance);
}

void tuh_mount_cb(uint8_t dev_addr) {
  Sprintf("usb [%u]: mount\n", dev_addr);
}

void tuh_umount_cb(uint8_t dev_addr) {
  Sprintf("usb [%u]: unmount\n", dev_addr);
  for (size_t i = 0; i < sizeof(hid) / sizeof(*hid); i++) {
    if (hid[i].present && hid[i].dev_addr == dev_addr) {
      Sprintf("hid [%zu]: removing\n", i);
      hid[i].present = false;
    }
  }
  buzzer.unplug();
}

void tuh_hid_set_protocol_complete_cb(uint8_t dev_addr, uint8_t instance, uint8_t protocol) {
  // haven’t seen this actually get printed so far, but only tried a few devices
  Sprintf("usb [%u:%u]: hid set protocol returned %u\n", dev_addr, instance, protocol);
}

// Invoked when received report from device via interrupt endpoint
void tuh_hid_report_received_cb(uint8_t dev_addr, uint8_t instance, uint8_t const *report, uint16_t len) {
  uint8_t if_protocol = usb3sun_uhid_interface_protocol(dev_addr, instance);
#ifdef UHID_VERBOSE
  Sprintf("usb [%u:%u]: hid report if_protocol=%u", dev_addr, instance, if_protocol);
  for (uint16_t i = 0; i < len; i++)
    Sprintf(" %02Xh", report[i]);
#else
  Sprint(".");
  (void) len;
#endif

  switch (if_protocol) {
    case USB3SUN_UHID_KEYBOARD: {
      const UsbkReport *kreport = reinterpret_cast<const UsbkReport *>(report);

#ifdef DEBUG_TIMINGS
      unsigned long t = usb3sun_micros();
#endif

      for (int i = 0; i < 6; i++) {
        if (kreport->keycode[i] != USBK_RESERVED && kreport->keycode[i] < USBK_FIRST_KEYCODE) {
#ifdef UHID_VERBOSE
          Sprintf(" !%u\n", kreport->keycode[i]);
#endif
          goto out;
        }
      }

      UsbkChanges changes{};
      changes.kreport = *kreport;

      for (int i = 0; i < 8; i++) {
        if ((state.lastModifiers & 1 << i) != (kreport->modifier & 1 << i)) {
#ifdef UHID_VERBOSE
          Sprintf(" %c%s", kreport->modifier & 1 << i ? '+' : '-', MODIFIER_NAMES[i]);
#endif
          changes.dv[changes.dvLen++] = {(uint8_t) (1u << i), kreport->modifier & 1 << i ? true : false};
        }
      }

      for (int i = 0; i < 6; i++) {
        bool oldInNews = false;
        bool newInOlds = false;
        for (int j = 0; j < 6; j++) {
          if (state.lastKeys[i] == kreport->keycode[j])
            oldInNews = true;
          if (kreport->keycode[i] == state.lastKeys[j])
            newInOlds = true;
        }
        if (!oldInNews && state.lastKeys[i] >= USBK_FIRST_KEYCODE) {
#ifdef UHID_VERBOSE
          Sprintf(" -%u", state.lastKeys[i]);
#endif
          changes.sel[changes.selLen++] = {state.lastKeys[i], false};
        }
        if (!newInOlds && kreport->keycode[i] >= USBK_FIRST_KEYCODE) {
#ifdef UHID_VERBOSE
          Sprintf(" +%u", kreport->keycode[i]);
#endif
          changes.sel[changes.selLen++] = {kreport->keycode[i], true};
        }
      }

#ifdef UHID_VERBOSE
      Sprintln();
#endif
#ifdef DEBUG_TIMINGS
      Sprintf("diffed in %ju\n", usb3sun_micros() - t);
#endif

      View::sendKeys(changes);

      // commit the DV and Sel changes
      state.lastModifiers = changes.kreport.modifier;
      for (int i = 0; i < 6; i++)
        state.lastKeys[i] = changes.kreport.keycode[i];
    } break;
    case USB3SUN_UHID_MOUSE: {
      const UsbmReport *mreport = reinterpret_cast<const UsbmReport *>(report);
#ifdef UHID_VERBOSE
      Sprintf(" buttons=%u x=%d y=%d", mreport->buttons, mreport->x, mreport->y);
#endif

#ifdef UHID_VERBOSE
      for (int i = 0; i < 3; i++)
        if ((state.lastButtons & 1 << i) != (mreport->buttons & 1 << i))
          Sprintf(" %c%s", mreport->buttons & 1 << i ? '+' : '-', BUTTON_NAMES[i]);
      Sprintln();
#endif

      sunmSend(
        mreport->x, mreport->y,
        !!(mreport->buttons & USBM_LEFT),
        !!(mreport->buttons & USBM_MIDDLE),
        !!(mreport->buttons & USBM_RIGHT));

      state.lastButtons = mreport->buttons;
    } break;
    default: {
#ifdef UHID_VERBOSE
      Sprintln();
#endif
    } break;
  }
out:
  // continue to request to receive report
  if (!usb3sun_uhid_request_report(dev_addr, instance))
    Sprintf("error: usb [%u:%u]: failed to request to receive report\n", dev_addr, instance);
}

#ifdef USB3SUN_HAL_LINUX_NATIVE

#include <cstring>
#include <iostream>
#include <unistd.h>
#include <fcntl.h>
#include <sys/stat.h>
#include <sys/types.h>
#include <sys/wait.h>

#define TEST_REQUIRES(expr) do { fprintf(stderr, ">>> skipping test (requires %s)\n", #expr); return true; } while (0)
#define TEST_ASSERT_EQ(actual, expected) do { if (actual != expected) { std::cerr << "\n" __FILE__ ":" << __LINE__ << ": assertion failed: " #actual "\n    actual: " << actual << "\n    expected: " << expected << "\n"; return false; } } while (0)
static bool assert_then_clear_test_history(const char *file, size_t line, const std::vector<Op> &expected) {
  const std::vector<Entry> &actual = usb3sun_test_get_history();
  std::optional<size_t> first_difference{};
  for (size_t i = 0; i < actual.size() || i < expected.size(); i++) {
    if ((i < actual.size()) != (i < expected.size()) || actual[i].op != expected[i]) {
      first_difference = i;
      break;
    }
  }
  if (first_difference.has_value()) {
    std::cerr << "\n" << file << ":" << line << ": assertion failed: bad test history!\n";
    for (size_t i = 0; i < *first_difference; i++) {
      std::cerr << "    " << actual[i] << "\n";
    }
    for (size_t i = *first_difference; i < actual.size() || i < expected.size(); i++) {
      std::cerr << "!!!";
      if (i < actual.size()) {
        std::cerr << " " << actual[i];
      }
      if (i < expected.size()) {
        std::cerr << " (expected " << expected[i] << ")";
      }
      std::cerr << "\n";
    }
  }
  usb3sun_test_clear_history();
  return !first_difference.has_value();
}
#define assert_then_clear_test_history(...) assert_then_clear_test_history(__FILE__, __LINE__, __VA_ARGS__)

static std::vector<const char *> test_names = {
  "setup_pinout_v1",
  "setup_pinout_v2",
  "sunk_reset",
  "uhid_mount",
  "buzzer_bell",
  "buzzer_click",
  "settings_read_ok",
  "settings_read_not_found",
  "settings_read_v1_ok",
  "settings_read_v1_wrong_version",
  "settings_read_v1_too_short",
  "view_stack",
  "menu_settings",
  "menu_hostid",
};

static void help() {
  std::cerr << "usage: path/to/program <demo|all|test_name>\n";
  std::cerr << "...where test_name can be one of:\n";
  for (const char *&name : test_names) {
    std::cerr << "    " << name << "\n";
  }
}

static std::vector<uint8_t> bytes(size_t len, const uint8_t *data) {
  return {data, data + len};
}

static std::vector<uint8_t> bytes(size_t len, const char *data) {
  return bytes(len, reinterpret_cast<const uint8_t *>(data));
}
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
int main(int argc, char **argv) {
  if (argc >= 2) {
    const char *test_name = argv[1];
    if (!strcmp(test_name, "demo")) {
      if (argc >= 3) {
        initDisplay(argv[2]);
      } else {
        char displayPath[] = "/tmp/usb3sun.XXXXXX\0display";
        if (mkdtemp(displayPath)) {
          displayPath[19] = '/';
          initDisplay(displayPath);
        } else {
          perror("mkdtemp");
        }
      }
      usb3sun_test_init(0);
      usb3sun_test_exit_on_reboot();
      usb3sun_test_terminal_demo_mode(true);
      setup();
      setup1();
      while (true) {
        constexpr size_t escAltTimeout = 100'000ul;
        static char prev = '\0';
        static uint64_t tLastEsc = usb3sun_micros();
        bool hadInput = false;
        int input;
        while ((input = usb3sun_debug_uart_read()) != -1) {
          handleDemoInput(static_cast<uint8_t>(input));
          hadInput = true;
          prev = input;
          if (input == /* ESC */ '\033') {
            tLastEsc = usb3sun_micros();
          }
        }
        if (!hadInput && prev == /* ESC */ '\033') {
          if (usb3sun_micros() - tLastEsc > escAltTimeout) {
            handleDemoInput({});
          }
        }
        loop();
        loop1();
      }
    } else if (!strcmp(test_name, "all")) {
      for (const char *&name : test_names) {
        std::cerr << ">>> starting test: " << name << "\n";
        test_name = name;
        pid_t pid = fork();
        if (pid == 0) {
          if (run_test(test_name)) {
            return 0;
          } else {
            std::cerr << ">>> test failed: " << test_name << "\n";
            return 1;
          }
        } else if (pid == -1) {
          perror("fatal: fork");
          return 1;
        } else {
          int result;
          wait(&result);
          if (!WIFEXITED(result) || WEXITSTATUS(result) != 0) {
            std::cerr << "fatal: wait(2) returned " << result << "\n";
            return 1;
          }
        }
      }
      return 0;
    } else {
      return run_test(test_name) ? 0 : 1;
    }
  }
  help();
  return 0;
}

#endif

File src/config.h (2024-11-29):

#define DISPLAY_ROTATION 0  // 0|1|2|3 where 0 means GND pin is bottom left

#define DEBUG_LOGGING           // allow any logging
#define DEBUG_OVER_CDC          // log to Serial (USB CDC); excludes TinyUSB debugging
#define DEBUG_OVER_UART         // log to Serial1 (UART0); includes TinyUSB debugging
                                // (ignored in pinout v1 when SUNK_ENABLE is defined)
#define DEBUG_UART_BAUD 115200  // only 115200 works with stock picoprobe firmware

// #define DEBUG_TIMINGS       // log time spent on critical operations
// #define BUZZER_VERBOSE      // log buzzer state changes for debugging
// #define SUNK_VERBOSE        // log keyboard tx for debugging
// #define SUNM_VERBOSE        // log mouse tx for debugging
// #define UHID_VERBOSE        // log hid reports for debugging

// #define UHID_LED_ENABLE     // enable leds on usb keyboards?
// #define UHID_LED_TEST       // blink leds on all usb keyboards

// #define WAIT_PIN 22      // GP# number (optional) to wait for ground on boot
// #define WAIT_SERIAL      // wait for serial input over USB CDC on boot (buggy)
#define USB0_DP 2           // GP# number for USB root port 0 D+
#define USB0_DM (USB_DP+1)  // GP# number for USB root port 0 D- (always D+ GP# + 1)
#define USB1_DP 4           // GP# number for USB root port 1 D+
#define USB1_DM (USB_DP+1)  // GP# number for USB root port 1 D- (always D+ GP# + 1)
#define BUZZER_PIN 28       // GP# number for positive of passive piezo buzzer
#define PINOUT_V2_PIN 7     // GP# number for detecting pinout v2 (rev A4+)
#define LED_PIN 25          // GP# number for pico’s built-in led

// the following must be GP# numbers valid for...
#define DEBUG_UART_TX 0     // ...UART0 TX: connect to picoprobe GP5
#define DEBUG_UART_RX 1     // ...UART0 RX: connect to picoprobe GP4
#define KTX_ENABLE 13       // ...any: break preventer for sun keyboard tx
#define DISPLAY_ENABLE 12   // ...any: external reset for SSD1306
#define DISPLAY_SCL 17      // ...I2C0 SCL: SCL pin of SSD1306
#define DISPLAY_SDA 16      // ...I2C0 SDA: SDA pin of SSD1306

// pinout v1/v2 config
// the following must be GP# numbers valid for...
                            // pin 1: 0 V (purple)
                            // pin 2: 0 V (brown)
                            // pin 3: +5 Vdc (blue)
                            // n/c: mouse rx
#define SUN_MRX_V1 9        // ...UART1 RX (required by SerialUART api)
                            // pin 4: mouse tx (gray)
#define SUN_MTX_V1 8        // ...UART1 TX
#define SUN_MTX_V2 14       // ...any
                            // pin 5: keyboard rx (red)
#define SUN_KRX_V1 13       // ...UART0 RX
#define SUN_KRX_V2 9        // ...UART1 RX
                            // pin 6: keyboard tx (green)
#define SUN_KTX_V1 12       // ...UART0 TX
#define SUN_KTX_V2 8        // ...UART1 TX
                            // pin 7: power key (yellow)
#define POWER_KEY 15        // ...any
                            // pin 8: +5 Vdc (orange)

// the following should generally be set in platformio.ini only, but remember
// to update compile_commands.json (pio run -t compiledb) when changing these,
// so clangd knows what features are enabled.
// -DSUNK_ENABLE in platformio.ini to enable sun keyboard interface
// -DSUNM_ENABLE in platformio.ini to enable sun mouse interface
// -DSUNK_SNIFFER_ENABLE in platform.ini to enable sun keyboard sniffer
// -DWIPE_SETTINGS in platformio.ini to wipe settings on every boot

#if defined(SUNK_ENABLE) || defined(SUNM_ENABLE)
#ifdef SUNK_SNIFFER_ENABLE
#error SUNK_ENABLE and SUNM_ENABLE are not allowed when SUNK_SNIFFER_ENABLE is set
#endif
#endif

#if defined(DEBUG_LOGGING)
#define Sprint(...) do { pinout.debugPrint(__VA_ARGS__); } while (0)
#define Sprintln(...) do { pinout.debugPrintln(__VA_ARGS__); } while (0)
#define Sprintf(...) do { pinout.debugPrintf(__VA_ARGS__); } while (0)
#else
#define Sprint(...) do {} while (0)
#define Sprintln(...) do {} while (0)
#define Sprintf(...) do {} while (0)
#endif

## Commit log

2022-12-07 fix Serial flushing with -DUSE_TINYUSB
    [main.cc]
2022-12-07 wait on boot and fix uart pin assignment
    [main.cc]
2022-12-07 improve buzzer-related status display
    [main.cc]
2022-12-07 fix tone-based buzzer (ty @ar1a)
    [main.cc]
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2022-12-07 change menu binding to CtrlR+Space
    [main.cc]
2022-12-08 fix keyboard rx in SUNK_LED
    [main.cc]
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2022-12-08 fix mouse tx format
    [config.h, main.cc]
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2023-01-07 fix minor error in bill of materials for resistors
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2023-01-07 fix bug in assembly section and add troubleshooting tip
2023-01-08 fix bug where mouse baud was too high
    (introduced in 50582effc58439b34bc68170c964e646415e4b76)
    [main.cc]
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2023-01-08 fix bug where led bits other than num were always treated as zero
    [main.cc]
2023-01-08 fix bug where button states were inverted in mouse tx
    [main.cc]
2023-01-08 fix bug where click happens when releasing a key
    [main.cc]
2023-01-08 fix bug where bell would pop then go silent
    [main.cc]
2023-04-10 pcb: initial kicad project
    [usb3sun.kicad_pcb, usb3sun.kicad_sch]
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2023-04-10 pcb schematic: use logical symbol for pico
    [usb3sun.kicad_pcb, usb3sun.kicad_sch]
2023-04-10 pcb schematic: add title and revision
    [usb3sun.kicad_sch]
2023-04-10 pcb schematic: aria shark review
    [usb3sun.kicad_sch]
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2023-04-11 pcb schematic: rework power to allow running on VSUN without VBUS
    [power.kicad_sch, usb3sun.kicad_sch]
2023-04-12 pcb schematic: rework power to use MAX40200 ideal diodes
    [usb3sun.kicad_sch]
2023-04-12 pcb schematic: clean up subcircuit boxes
    [usb3sun.kicad_sch]
2023-04-12 add caps to ideal diodes
    [usb3sun.kicad_sch]
2023-04-12 pick a fuse
    https://jlcpcb.com/partdetail/2981875-JK_nSMD10016V/C2830246
    [usb3sun.kicad_sch]
2023-04-12 add ESD protection and properly shield ports
    [usb3sun.kicad_sch]
2023-04-12 add mounting holes and ground one of them
    [usb3sun.kicad_sch]
2023-04-12 assign missing footprints
    [usb3sun.kicad_sch]
2023-04-12 fuse individual usb ports
    [usb3sun.kicad_sch]
2023-04-12 add 100uF cap to usb ports
    [usb3sun.kicad_sch]
2023-04-12 add SRV05-4 ESD protection to usb ports
    [usb3sun.kicad_sch]
2023-04-12 add 22 ohm termination resistors
    [usb3sun.kicad_sch]
2023-04-14 pcb schematic: clean up layouts and ERC lints
    [usb3sun.kicad_sch]
2023-04-14 pcb layout: redraw from scratch
    [usb3sun.kicad_pcb, usb3sun.kicad_sch]
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2023-04-15 pcb layout: use SMT piezo speaker
    [usb3sun.kicad_pcb, usb3sun.kicad_sch]
2023-04-15 pcb layout: shorten board edge on usb side
    [usb3sun.kicad_pcb, usb3sun.kicad_sch]
2023-04-15 pcb layout: don’t hide any objects on F.Fab/B.Fab
    [usb3sun.kicad_pcb]
2023-04-15 pcb layout: make board 100 mils narrower
    [usb3sun.kicad_pcb]
2023-04-15 pcb layout: remove pico holes
    [usb3sun.kicad_pcb]
2023-04-15 pcb layout: fix some thermal relief lints
    [usb3sun.kicad_pcb]
2023-04-15 pcb layout: rework to have only pico on back side
    [usb3sun.kicad_pcb, usb3sun.kicad_sch]
2023-04-15 pcb layout: trim unused space and stitch ground planes
    [usb3sun.kicad_pcb]
2023-04-15 pcb layout: unlock OSHW logo
    [usb3sun.kicad_pcb]
2023-04-15 pcb layout: expose picoprobe pins and fix remaining vias in pads
    [usb3sun.kicad_pcb, usb3sun.kicad_sch]
2023-04-15 pcb layout: fix ERC/DRC lints and finishing touches
    [usb3sun.kicad_pcb, usb3sun.kicad_sch]
2023-04-15 pcb layout: cleanup tracks/vias and add teardrops
    [usb3sun.kicad_pcb]
2023-04-15 pcb layout: update copper fill
    [usb3sun.kicad_pcb]
2023-04-15 pcb layout: fix incorrect footprint for picoprobe header
    [usb3sun.kicad_pcb]
2023-04-17 pcb layout: replace MD-80SM with another connector due to stock
    [usb3sun.kicad_pcb, usb3sun.kicad_sch]
2023-04-17 pcb layout: use curved teardrops and move sus via
    [BOM-usb3sun.csv, usb3sun.kicad_pcb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]
2023-04-26 pcb: finalise rev A0
    [usb3sun.kicad_pcb, usb3sun.kicad_sch]
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2023-04-28 fix panic when combining PICOPROBE_ENABLE and CFG_TUSB_DEBUG
    [main.cc]
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2023-05-06 replace click mode “setting” with click override setting
    [buzzer.cc, main.cc]
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2023-05-10 pcb: start new rev
    [usb3sun.kicad_pcb, usb3sun.kicad_sch]
2023-05-10 pcb: add reset and hard power key switches
    [usb3sun.kicad_pcb, usb3sun.kicad_sch]
2023-05-10 pcb: add led indicators for vbus and vsun
    [usb3sun.kicad_pcb, usb3sun.kicad_sch]
2023-05-10 pcb: expose UART0 for picoprobe on debug header
    [usb3sun.kicad_pcb, usb3sun.kicad_sch]
2023-05-10 pcb layout: move power button away from display like reset button
    [usb3sun.kicad_pcb]
2023-05-10 pcb: make all mounting holes padded on both sides
    [usb3sun.kicad_pcb, usb3sun.kicad_sch]
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2023-05-10 pcb: make other three mounting holes floating (but keep double pads)
    [usb3sun.kicad_pcb, usb3sun.kicad_sch]
2023-05-10 pcb: add mounting holes for display mechanical support
    [usb3sun.kicad_pcb, usb3sun.kicad_sch]
2023-05-10 pcb: stitch vias to improve ground plane islands
    [usb3sun.kicad_pcb]
2023-05-10 pcb: finalise rev A1 with tweaks to mini-din position and edge cuts
    [BOM-usb3sun.csv, usb3sun.kicad_pcb, usb3sun.kicad_sch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]
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2023-06-22 hardware: add 3d printed support for the display module
    [support.FCStd, support.stl]
2023-06-28 pcb: change switch from TS-1187A-C-H-B to -B-A-B (jlcpcb basic)
    [usb3sun.kicad_pcb]
2023-06-28 pcb: reduce brightness of power supply leds to ~10% Iᵥ
    [usb3sun.kicad_sch]
2023-06-28 pcb: sync schematic and layout
    [usb3sun.kicad_pcb, usb3sun.kicad_sch]
2023-06-28 pcb: clean up schematic for readability
    [usb3sun.kicad_pcb, usb3sun.kicad_sch]
2023-06-29 pcb: add usb-c port to make firmware updates easier
    [usb3sun.kicad_pcb, usb3sun.kicad_sch]
2023-06-29 pcb: add fuse after power supply switching
    [usb3sun.kicad_pcb, usb3sun.kicad_sch]
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2023-06-29 pcb: add gpio fallback for D+ and D- in case of errata
    [usb3sun.kicad_pcb, usb3sun.kicad_sch]
2023-06-29 pcb: add “debug only” to silkscreen near usb-c port
    [usb3sun.kicad_pcb]
2023-06-29 pcb: add more vias and fix text constraint violations
    [usb3sun.kicad_pcb]
2023-06-29 pcb: finalise rev A2
    [BOM-usb3sun.csv, usb3sun.kicad_pcb, usb3sun.kicad_sch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]
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2023-06-30 add user guide and update README accordingly
    [usb3sun.kicad_pcb]
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2023-07-15 fix bug where long menu item names would wrap
    [main.cc]
2023-07-17 sunk: fix bug where idle would go out of sync after opening menu
    [main.cc]
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2023-07-17 usbk: look up bindings in constant time (45 us → 20 us)
    [main.cc]
2023-07-17 sunk: allow special bindings (CtrlR) when other modifiers are pressed
    [main.cc]
2023-07-17 sunk: fix bug where special bindings fail if CtrlR is released first
    [main.cc]
2023-07-17 buzzer: log state changes only when BUZZER_VERBOSE is set
    [buzzer.cc, config.h]
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2023-09-16 pcb: fix bug where D+ can leak through U7 onto VBUS
    [usb3sun.kicad_pcb, usb3sun.kicad_sch]
2023-09-18 pcb: add ao!! dog and serial number box
    [usb3sun.kicad_pcb]
2023-09-26 pcb: use zener diode current sources for led indicators
    [usb3sun.kicad_pcb, usb3sun.kicad_sch]
2023-09-26 pcb: move +5V and VBUS traces further from board edge
    [usb3sun.kicad_pcb]
2023-09-26 pcb: clean up drawing sheet
    [usb3sun.kicad_pcb, usb3sun.kicad_sch]
2023-09-26 pcb: finalise rev A3
    [BOM-led.csv, BOM-usb3sun.csv, SC0915.step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]
2023-09-26 pcb: replace Q5 with jlcpcb basic parts Q5 + Q6
    [BOM-usb3sun.csv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]
2023-09-26 pcb: replace J1 with compatible due to stock shortage
    [BOM-usb3sun.csv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]
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2024-02-17 buzzer: migrate back to pwm to free up pio insn space
    [buzzer.cc]
2024-02-17 buzzer: stop pwm tones at precise times with alarms
    [buzzer.cc]
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2024-02-18 pcb: pinout v2: move sunk to uart1, move sunm to pio uart
    [usb3sun.kicad_pcb, usb3sun.kicad_sch]
2024-02-18 pcb: add external reset for display module
    [usb3sun.kicad_pcb, usb3sun.kicad_sch]
2024-02-18 pcb: fix unconnected ground fill to display external reset
    [usb3sun.kicad_pcb]
2024-02-18 pcb: improve ground fill coverage
    [usb3sun.kicad_pcb]
2024-02-18 pcb: put /DISPLAY_GND in power netclass
    [usb3sun.kicad_pcb, usb3sun.kicad_sch]
2024-02-18 firmware: remove fake sun feature, which was broken in pinout v2
    [config.h, main.cc]
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2024-02-18 pinout: fix bug where debug print macros may evaluate twice
    [config.h, pinout.cc]
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2024-02-18 sunk + sunm: reduce debug output and use short log prefixes
    [main.cc]
2024-02-18 [wip] break preventer (has drc violations)
    [usb3sun.kicad_pcb, usb3sun.kicad_sch]
2024-02-19 [wip] break preventer attempt 2, with 2N7002DW
    [usb3sun.kicad_pcb, usb3sun.kicad_sch]
2024-02-19 [wip] break preventer attempt 2.1
    [usb3sun.kicad_pcb]
2024-02-19 [wip] break preventer attempt 2.2
    [usb3sun.kicad_pcb]
2024-02-19 [wip] break preventer attempt 2.3
    [usb3sun.kicad_pcb, usb3sun.kicad_sch]
2024-02-19 pcb: sunk break preventer
    [usb3sun.kicad_pcb]
2024-02-19 pcb: remove JP1 + JP2, since there were no such errata
    [usb3sun.kicad_pcb, usb3sun.kicad_sch]
2024-02-19 pcb: clean up +5V trace now that JP1 + JP2 are gone
    [usb3sun.kicad_pcb]
2024-02-19 pcb: fix silkscreen that was accidentally moved
    [usb3sun.kicad_pcb]
2024-02-19 pcb: finalise rev B0
    [BOM-usb3sun.csv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]
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2024-03-02 rename DISPLAY_RES# to DISPLAY_ENABLE (and fix pin number)
    [usb3sun-CuBottom.gbr, usb3sun-CuTop.gbr, usb3sun-EdgeCuts.gbr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]
2024-03-02 firmware: break preventer: set KTX_ENABLE# low on boot
    [config.h, main.cc, pinout.cc]
2024-03-02 pcb: fix typo in schematic
    [usb3sun.kicad_sch]
2024-03-02 uhid: disable led support for now due to bugs and todo
    [config.h, main.cc]
2024-03-02 sunk: shorter prefix on led status log
    [main.cc]
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2024-03-09 uhid: fix incorrect printf args when dumping reports
    [main.cc]
2024-03-09 uhid: find and use correct report_id for leds
    [main.cc]
2024-03-09 uhid: fix use after free when updating leds
    [main.cc]
2024-03-09 uhid: fix missing newline when reporting ErrorRollOver
    [main.cc]
2024-11-16 migrate to kicad 8.0.5
    [usb3sun.kicad_pcb, usb3sun.kicad_sch]
2024-11-24 fix idprom output when real-machine-type is unavailable (fixes #15)
    [main.cc]
2025-03-13 pcb: update pcb from schematic for kicad 8
    [usb3sun.kicad_pcb]
2025-03-13 pcb: change part for J1 due to stock
    [usb3sun.kicad_pcb, usb3sun.kicad_sch]
2025-03-13 pcb: finalise rev B1
    [BOM-usb3sun.csv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]
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2025-05-26 increase delay after DISPLAY_ENABLE (fixes #20)
    [hal.cc, main.cc, pinout.cc]
